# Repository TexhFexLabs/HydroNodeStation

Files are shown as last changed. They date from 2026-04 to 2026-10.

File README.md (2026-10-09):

<div align="center">
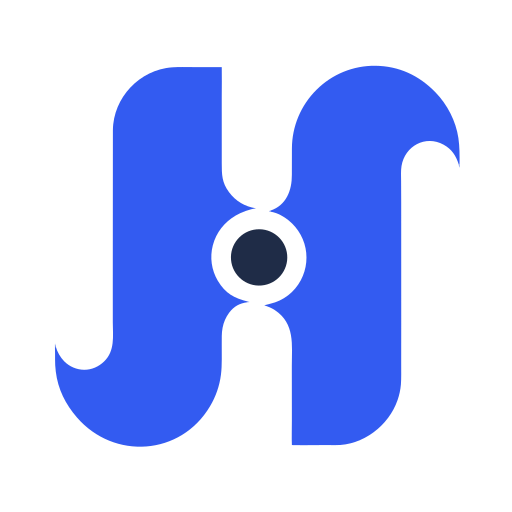
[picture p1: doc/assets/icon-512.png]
HydroNode logo
  
  <h1>HydroNodeStation</h1>
  <p><strong>Solar-powered, open-source LoRaWAN environmental monitoring node</strong></p>
  <p>Powered by <strong>HydroNode</strong></p>

  
  
  
  
  
  
  
</div>

---

> **Live now.** A station is deployed outdoors and streaming real sensor data.
> [View the live dashboard.](https://hydronode.tech/stations/public/004dd7e7-5c27-4de0-bff5-24116f721658)

<div align="center">
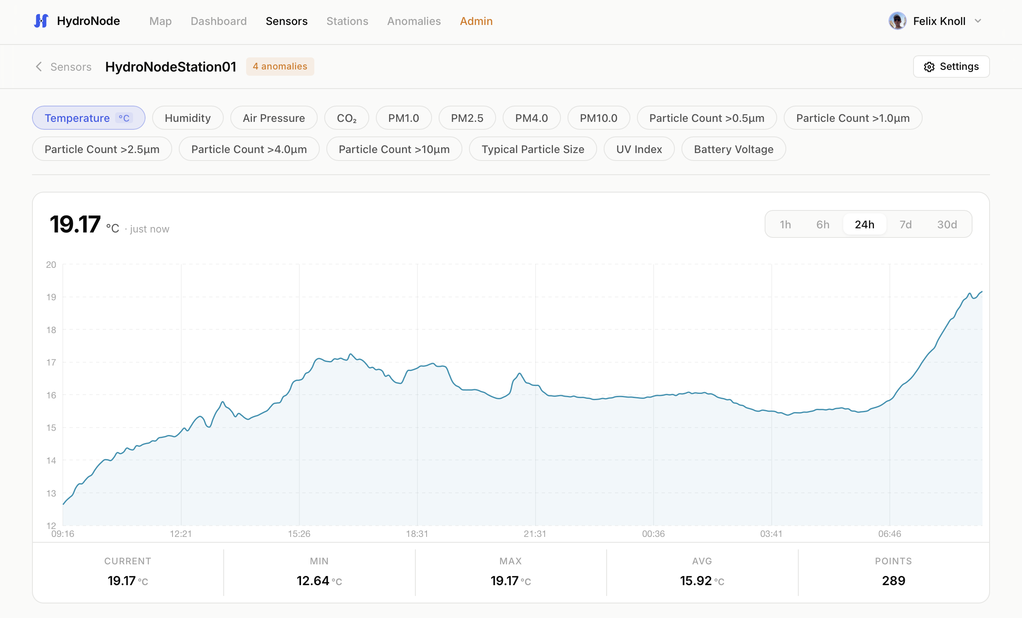
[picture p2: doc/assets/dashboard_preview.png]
HydroNode live dashboard showing HydroNodeStation sensor data
  
</div>

---

## What this is

Hyperlocal environmental data is scarce. Most weather and air quality stations are expensive, need mains power, and are installed at only a handful of official sites per city. Whole neighbourhoods have no measurements of the air they breathe.

The limiting factor is not the sensors. It is power and connectivity. A station that needs mains power or Wi-Fi can only go where that infrastructure already exists, which is not where the data gaps are.

HydroNodeStation is a monitoring node that needs no mains power, no Wi-Fi and no cellular contract. It runs on a small solar panel and a single LiPo cell, transmits over LoRaWAN, and is designed to be reproduced by anyone with a JLCPCB account and a 3D printer.

It is not a paper design. It was built, assembled and deployed as part of a university engineering project, and one station has been reporting continuously.

**Project status:** hardware revision 2 (PCB 1.1) is the supported board, firmware 2.1.0 is written for it and awaits its field acceptance test. Revision 1 boards stay on firmware 1.6.x, which is deployed; one station is live in the field. Long-term solar autonomy through a winter is not verified yet. See [Power budget](#power-budget-measured) for measured numbers instead of estimates.

<div align="center">
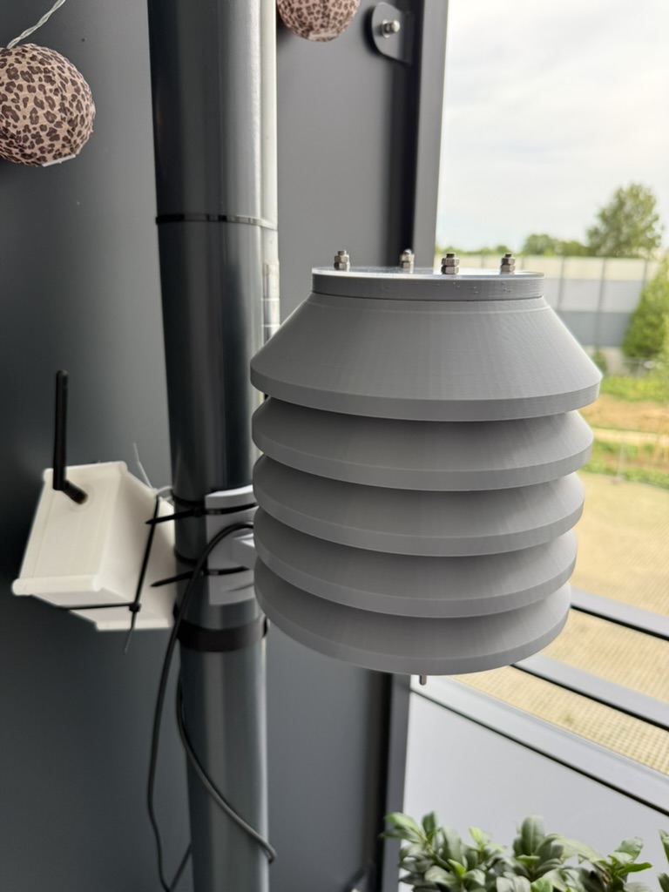
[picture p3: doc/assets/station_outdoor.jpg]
HydroNodeStation deployed outdoors, Stevenson screen mounted on a railing post
  
  <br><em>The deployed station.</em>
</div>

---

## Quick links

| | |
|---|---|
| Live dashboard | [hydronode.tech](https://hydronode.tech/stations/public/004dd7e7-5c27-4de0-bff5-24116f721658) |
| Hardware design (EasyEDA Pro / OSHWLab) | [oshwlab.com/knollfelix004/project_fegzdygg](https://oshwlab.com/knollfelix004/project_fegzdygg) |
| Build a station | [Jump to the build guide](#build-a-station) |
| Firmware reference | [doc/GETTING_STARTED.md](doc/GETTING_STARTED.md) |
| Configuration reference | [doc/CONFIGURATION.md](doc/CONFIGURATION.md) |
| Adding a sensor (Qwiic) | [doc/ADDING_SENSORS.md](doc/ADDING_SENSORS.md) |
| Reliability and rollout notes | [doc/RELIABILITY.md](doc/RELIABILITY.md) |
| Licensing | [LICENSING.md](LICENSING.md) |
| Development history | [doc/DEVELOPMENT_HISTORY.md](doc/DEVELOPMENT_HISTORY.md) |

---

## What it measures

| Quantity | Sensor | I2C address | Notes |
|---|---|---|---|
| CO2 concentration | Sensirion **SCD41** | 0x62 | Single-shot photoacoustic NDIR, plus or minus 40 ppm |
| Particulate matter | Sensirion **SPS30** | 0x69 | PM1.0, PM2.5, PM4, PM10 and number concentration |
| Temperature and humidity | Sensirion **SHT45** | 0x44 | plus or minus 0.1 degrees C, plus or minus 1.0 percent RH |
| Barometric pressure | Bosch **BMP390** | 0x77 | plus or minus 0.5 hPa absolute |
| UV index | Lite-On **LTR390** | 0x53 | UVA and ambient light |
| Battery state of charge | Maxim **MAX17048** | 0x36 | Fuel gauge, no sense resistor needed |

All six share one I2C bus. Sensors are commanded into their own sleep states between measurements. The SPS30 sits on a separate 5 V rail that the firmware switches off entirely through a GPIO.

The sensor set is a starting point, not a limit. Any I2C sensor can be added on the Qwiic connector (CN2) with a firmware adaptation, see [doc/ADDING_SENSORS.md](doc/ADDING_SENSORS.md).

---

## Hardware

### Custom 4-layer PCB

<div align="center">
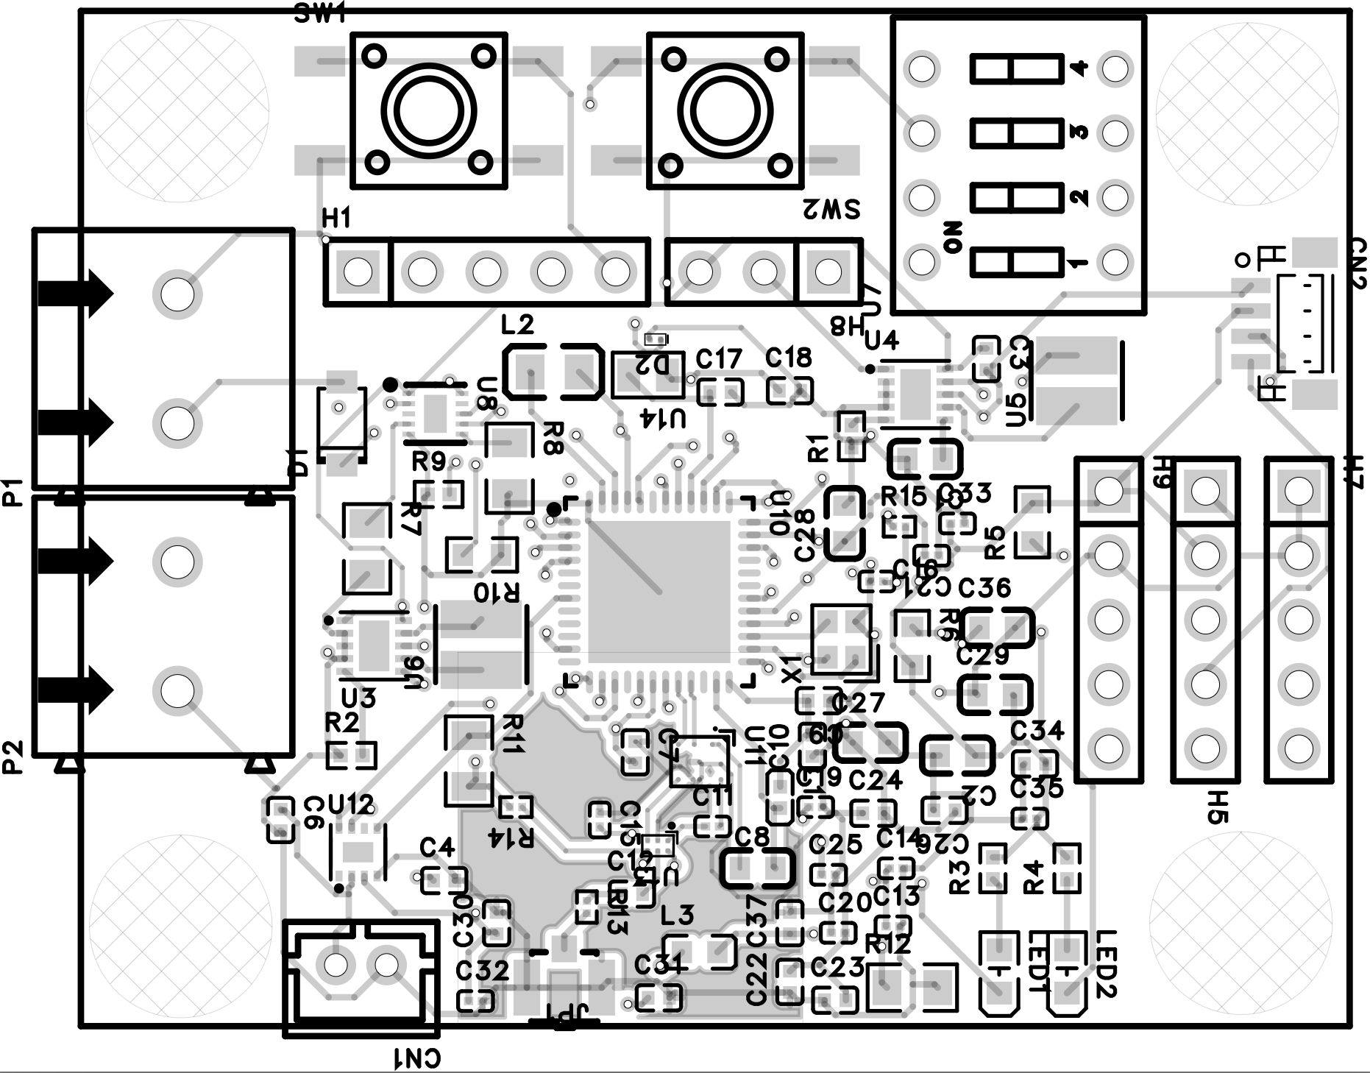
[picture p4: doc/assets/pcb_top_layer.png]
HydroNodeStation PCB top layer
  
</div>

Designed from scratch in EasyEDA Pro, fabricated and assembled at JLCPCB.

| Function | Part |
|---|---|
| MCU and radio | **STM32WLE5CCU6**, Cortex-M4 at 48 MHz with an integrated sub-GHz LoRa transceiver |
| RF front end | **BALFHB-WL-02D3** balun on RFO_HP and **BGS12SN6** TX/RX switch (select PC13, supply PB12), 32 MHz crystal |
| Antenna | External SMA connector |
| Solar charger | **BQ25185** |
| Regulators | Three **TPS63900** buck-boost converters. 3.3 V primary always on, 5 V for the SPS30 (EN5V, PA9) and a switchable 3.3 V rail (EN3V3SW, PA8) |
| Fuel gauge | **MAX17048** |
| Solar measurement | **INA226** on a 68 mOhm shunt plus a voltage divider on ADC PB2 |

**Stackup.** Top and bottom carry signal and supply. Inner 1 is a dedicated ground layer with a continuous copper pour. Inner 2 is a second signal layer. The continuous ground layer gives short return paths and keeps common-mode noise off the I2C and control lines.

**RF layout.** Traces in the RF section are 50 ohm controlled impedance for 868 MHz. A dense ground via fence surrounds the balun, the switch, the decoupling capacitors and the SMA path. It ties the RF field down to the ground layer and suppresses coupling into the rest of the board.

**Connectors.** A 2-pin JST connector and a parallel screw terminal for the battery, a 2-pin screw terminal for the solar panel, a 6-pin screw terminal for the cable to the Stevenson screen (I2C, supply, panel lead), and a 4-pin header for the ST-Link V2 (NRST, SWDCLK, SWDIO, GND). Test pads are provided on the supply rails, the I2C bus and the charger CE pin.

> **Revision 2 (PCB 1.1) pin changes against revision 1.** Charger CE moves to PA2, the RF switch is supplied from PB12, the 5 V and switchable 3.3 V rails have enable pins (PA9, PA8), and an INA226 measures the solar input. Firmware 2.0 requires these; firmware 1.6.x stays for revision 1.

> **Two faults in revision 1, both fixed in the published design.**
>
> **TPS63900 regulator section.** A wiring mistake. The deployed station runs the same chip on a breakout board plugged into the PCB headers as a workaround.
>
> **BQ25185 CE pin.** It has to be driven by an MCU GPIO so the firmware can reset the charger's internal 6 hour safety timeout. Without that, charging stops silently after six hours, which is fatal on a solar node. Revision 2 routes CE to a GPIO that the firmware pulses. On boards already fabricated, this pin has to be hand-soldered to the GPIO.

### Stevenson screen enclosure

<div align="center">
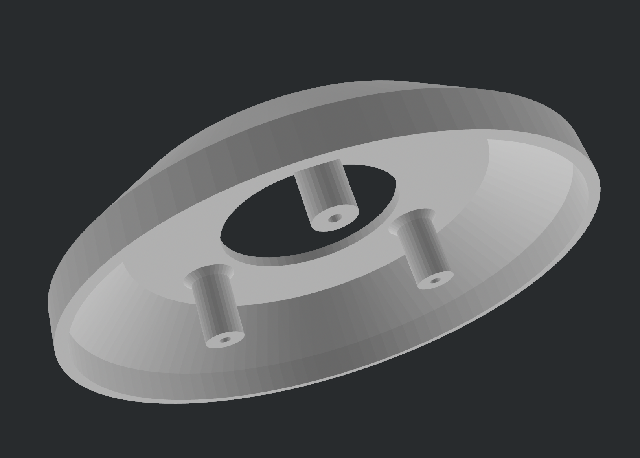
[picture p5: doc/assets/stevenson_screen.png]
3D-printed Stevenson screen middle section
  
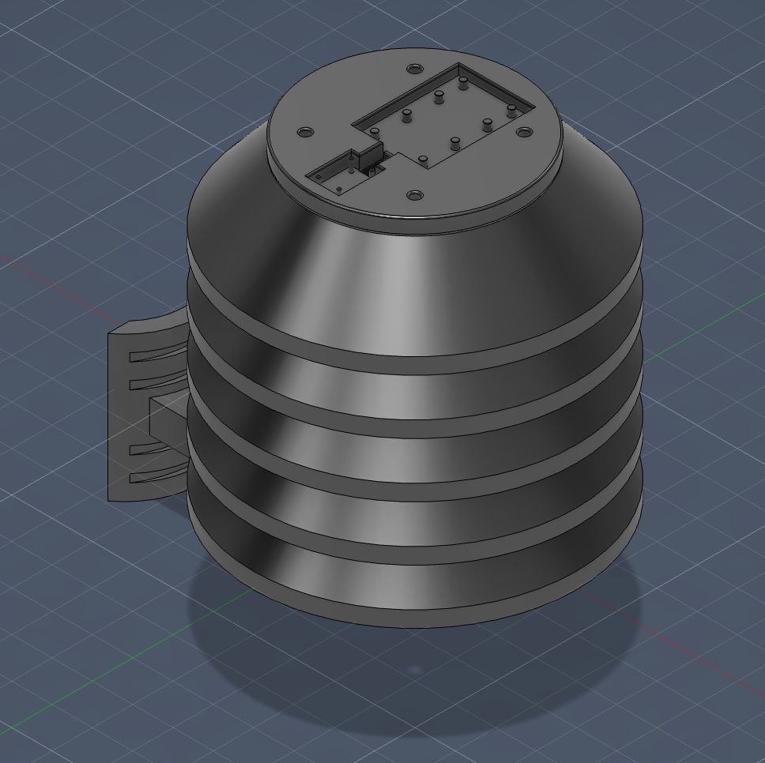
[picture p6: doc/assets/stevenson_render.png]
CAD render of the Stevenson screen with the PCB mounting plate
  
  <br><em>Printed part and the CAD model it comes from. The plate on top carries the PCB.</em>
</div>

Designed in Fusion 360, printed in white ASA. Stacked louvers block direct sun and driving rain while air circulates freely. Without that the housing heats up in sunlight and the temperature and humidity readings are wrong. ASA was chosen over PLA and PETG for outdoor UV stability. A PLA enclosure becomes brittle within a season.

Both models are in [`hardware/CAD/`](hardware/CAD/) as `.3mf` and print on any consumer FDM printer.

### System architecture

```mermaid
flowchart LR
    subgraph Field ["Field deployment"]
        Node1(("HydroNode\nStation #1"))
        Node2(("HydroNode\nStation #2"))
    end

    subgraph Network ["LoRaWAN network server"]
        NS["Helium IoT / ChirpStack v4 / TTN"]
    end

    subgraph Backend ["HydroNode cloud"]
        API{"HTTPS\nwebhook endpoint"}
        Kafka["Kafka pipeline\n(validation and processing)"]
        DB[("PostgreSQL")]
    end

    subgraph Client ["End users"]
        App["iOS app and web dashboard"]
    end

    Node1 -- LoRaWAN --> NS
    Node2 -- LoRaWAN --> NS
    NS -- HTTPS webhook --> API
    API --> Kafka
    Kafka --> DB
    DB --> App
```

---

## Build a station

This is the complete path from ordering parts to seeing your own readings on the dashboard. Budget two to three weeks, most of which is PCB lead time.

### Step 1: order the PCB

1. Open the [OSHWLab project](https://oshwlab.com/knollfelix004/project_fegzdygg) and fork it. It opens in EasyEDA Pro in the browser, so no desktop EDA installation is needed.
2. Order from the editor through JLCPCB. 4 layers, standard process, no exotic requirements.
3. Enable SMT assembly. This matters. The STM32WLE5, the balun and the RF switch are fine-pitch parts, and hand-soldering them is where most reproduction attempts fail.
4. The bill of materials with LCSC part numbers is generated by EasyEDA on the project page and can be ordered from there directly. Populate only the sensors you need, see the cost table below.

### Step 2: order the remaining parts

These are not on the PCB and have to be sourced separately.

| Part | What is deployed today | Notes |
|---|---|---|
| Solar panel | **AnySolar SOLAR CELL G3 THIN**, 6.91 V, 570.8 mW, Vmpp 5.58 V, Impp 102 mA | Fully sufficient in summer. Winter operation is not verified yet. **Do not use a smaller panel.** Same size or larger only. |
| Battery | 1S LiPo, **1200 mAh** | Scale with the panel. Larger is fine and helps in winter. Much smaller is risky, since several overcast days in a row will drain it. |
| Antenna | 868 MHz antenna with an SMA connector | The board has an external SMA connector, so any matched antenna works. |
| Cable to the screen | 6-core cable | Runs from the PCB screw terminal to the sensor head: I2C, supply, panel lead. |
| Cable gland | Waterproof, sized for your cable | For the panel lead entering the enclosure. |
| UV window | 2 mm polystyrene sheet | See the note below. |
| Programmer | ST-Link V2 | Connects to NRST, SWDCLK, SWDIO, GND. |
| Serial adapter | USB to UART, 3.3 V | Needed once, to read the Device EUI off header H1 at 115200 baud. |

> **About the UV window.** The LTR390 has to see UV through the enclosure, but ordinary glass and PETG block most of it and produce a reading that is wrong rather than missing. The deployed station uses roughly 2 mm of polystyrene with an empirical correction factor of 17/13, applied in the firmware as integer arithmetic. That was a cost decision. It works, but polystyrene is not UV-stable and will degrade outdoors. **UV-transmitting acrylic (PMMA UVT) is the better choice** for a station meant to last. Quartz or borosilicate is better still and costs around 50 EUR for a small disc. Issue [#2](../../issues/2) tracks cheaper options.

### Step 3: print the enclosure

Both models are in [`hardware/CAD/`](hardware/CAD/).

- `hydroNodeStation_outdoor_screen.3mf` is the Stevenson screen for the sensor head.
- `hydroNodeStation_outdoor_box.3mf` is the housing for the PCB.

Print in **white ASA**, not PLA and not PETG. White reflects sunlight, which matters for the temperature reading, and ASA survives UV exposure. Expect to iterate once on fit. The original design took several print runs to get right.

### Step 4: assemble

1. Mount the PCB on the plate at the top of the Stevenson screen.
2. Wire the 6-core cable from the PCB screw terminal to the sensor head.
3. Connect the battery to the JST connector or the parallel screw terminal.
4. Connect the solar panel to its screw terminal, routing the lead through the cable gland.
5. Screw the antenna onto the SMA connector.
6. Fit the UV window over the LTR390.

> **Building from revision 1 boards?** Hand-solder the BQ25185 CE pin to the MCU GPIO before you deploy. Without it, charging stops after six hours and the station dies over a few days while sitting in full sun.

> **Battery protection.** In the published schematic the BQ25185 TS/MR pin uses a fixed 10 kilohm resistor, so the charger does not measure battery temperature. Outdoor winter operation needs an appropriate battery NTC and a verified undervoltage path. The firmware cannot protect an unprotected cell below MCU operating voltage. See [doc/RELIABILITY.md](doc/RELIABILITY.md).

### Step 5: install the toolchain

| Tool | Version |
|---|---|
| `arm-none-eabi-gcc` | 12 or newer |
| `cmake` | 3.22 or newer |
| `ninja` | any |
| `openocd` or STM32CubeProgrammer | any |

```bash
# macOS
brew install arm-none-eabi-gcc cmake ninja

# Ubuntu / Debian
sudo apt install gcc-arm-none-eabi cmake ninja-build
```

### Step 6: build the firmware

```bash
git clone https://github.com/TexhFexLabs/HydroNodeStation.git
cd HydroNodeStation/stm32_node

cmake -B build/Release -DCMAKE_BUILD_TYPE=Release -DCMAKE_TOOLCHAIN_FILE=cmake/gcc-arm-none-eabi.cmake
cmake --build build/Release
```

The output is `build/Release/LoRaWAN_End_Node_LBM.elf` plus `.bin` and `.hex`. The `Debug` target builds the same firmware with trace output over USART1, which step 7 uses. Firmware 2.0 needs a revision 2 board (PCB 1.1); for revision 1 check out a 1.6.x release.

Leave the LoRaWAN keys alone for now. `LORAWAN_DEVICE_EUI` stays at all zeros, which tells the firmware to derive the Device EUI from the STM32 hardware UID.

### Step 7: flash and read the Device EUI

Connect the ST-Link V2 to NRST, SWDCLK, SWDIO and GND, then flash:

```bash
openocd -f interface/stlink.cfg -f target/stm32wlx.cfg \
        -c "program build/Release/LoRaWAN_End_Node_LBM.elf verify reset exit"
```

STM32CubeProgrammer works too. Open the `.elf`, select ST-Link, click Download.

Clear the option byte **IWDG_STDBY** once per board, otherwise the station cannot use its Standby stage at deep discharge (it then stays in RECOVERY and reports `0x0544`):

```bash
STM32_Programmer_CLI -c port=SWD -ob IWDG_STDBY=0
```

To read the Device EUI, flash the `Debug` build once (`cmake --preset Debug && cmake --build --preset Debug`, then flash `build/Debug/LoRaWAN_End_Node_LBM.elf`). Connect the USB to UART adapter to header **H1** (PB6 = TX, PB7 = RX) at 115200 baud. The firmware prints the derived **Device EUI** on boot. Write it down, it is needed in the next two steps. With DIP 1 closed, LED1 flashes once per join attempt and twice when the join succeeds.

### Step 8: register the device on a LoRaWAN network server

Create an OTAA device with that Device EUI. Use LoRaWAN 1.0.4 and the regional parameters for your region, EU868 in Europe. Helium IoT, ChirpStack v4 and The Things Network all work.

The network server returns a **Join EUI** and an **App Key**.

### Step 9: enter the keys and reflash

Create `stm32_node/LoRaWAN/App/se-identity-local.h`. This file is git-ignored, and the firmware picks it up automatically:

```c
#define LORAWAN_DEVICE_EUI    00,00,00,00,00,00,00,00   // leave at zero, derived from the chip UID
#define LORAWAN_JOIN_EUI      AA,BB,CC,DD,EE,FF,00,11   // from your network server
#define LORAWAN_APP_KEY       AA,BB,CC,DD,EE,FF,00,11,22,33,44,55,66,77,88,99
#define LORAWAN_GEN_APP_KEY   AA,BB,CC,DD,EE,FF,00,11,22,33,44,55,66,77,88,99
```

`LORAWAN_GEN_APP_KEY` takes the same value as `LORAWAN_APP_KEY` under LoRaWAN 1.0.x.

Never put real keys in the tracked `se-identity.h`, and never commit them. See [SECURITY.md](SECURITY.md).

Rebuild the `Release` target and flash it. The station now starts the OTAA join with your credentials.

### Step 10: connect it to HydroNode

1. Open [hydronode.tech](https://hydronode.tech) or the HydroNode app and register. The first sensor slot is included at no cost.
2. Select the sensor, then go to **Settings, LoRaWAN Binding**.
3. Enter the **Device EUI** from step 7 and save.
4. HydroNode then shows a **webhook URL**.
5. Enter that URL on your network server under **Integrations, HTTP / Webhook**.

That is the whole integration. The backend decodes the payload by fPort, stores it and runs anomaly detection without further configuration. Readings appear in the dashboard and the app from the next uplink onward.

To run your own backend instead, the payload decoder is published as [`doc/payload-decoder.js`](doc/payload-decoder.js) and the payload format is specified in [doc/CONFIGURATION.md](doc/CONFIGURATION.md). Nothing in the firmware is tied to the HydroNode infrastructure.

### Step 11: verify

The first uplink lands on fPort 2 and should appear within one to two minutes if there is gateway coverage.

To place the antenna, close DIP 4 (installation mode) and DIP 1 before power-on. For 30 minutes after the join the station sends every 60 seconds and runs a link check after every third uplink; LED1 then flashes once per gateway that heard it, or once long when none answered.

To check the sensors without LoRaWAN, close DIP 3 (debug profile) before power-on. The node skips LoRaWAN entirely, reads all sensors including the solar measurement in a loop and prints the values on H1 at 115200 baud. This works with the Release build. Open both switches again for normal operation; they are read only at boot.

### Cost

| Build | Sensors populated | Sensor cost |
|---|---|---|
| Minimal | Temperature, humidity, pressure (SHT30 as a substitute) | under 30 USD |
| Air quality | Plus LTR390 UV and SCD41 CO2 | around 70 USD |
| Full node | All six channels including the SPS30 | 120 to 150 USD |

Sensors only. The board itself, the RF section, the power stage and the fabrication come on top, roughly 200 EUR for 5 assembled boards. Unpopulated sensor positions cost nothing and break nothing, so one design serves a single hobbyist node and a research-grade array.

---

## Firmware

Firmware 2.1.0 runs on PCB 1.1. Since 2.1 the send interval and the four battery thresholds can be changed by downlink `14` and the station reports the values in effect on fPort 6. It keeps everything firmware 1.6 brought (fix of the uplink outage after 49.71 days, watchdog and progress recovery, robust sensor shutdown, battery recovery, transactional NVM) and adds solar and fuel gauge data on ports 2 and 3, fault and event reports on fPort 99, command acknowledgements, an adaptive measurement plan with a Standby stage for deep discharge, a daily link check with rejoin, and the installation mode. See [doc/CONFIGURATION.md](doc/CONFIGURATION.md) and [doc/RELIABILITY.md](doc/RELIABILITY.md).

The firmware runs on the STM32Cube ecosystem with the Semtech **LoRa Basics Modem**.

- **STOP2 deep sleep** between transmissions, capped at 8 seconds so the independent watchdog stays fed.
- **3 minute measurement cycle** (`APP_TX_DUTYCYCLE`), adjustable over the air between 30 and 3600 seconds.
- **CO2 every fifth uplink, particulate matter every tenth.** The expensive sensors do not run every cycle.
- **Solar sampling every 30 seconds.** INA226 voltage, current and power, energy and sunshine time, plus the panel voltage on the ADC, collected into a 22-byte block on ports 2 and 3.
- **LoRaWAN Class A** with network-controlled adaptive data rate and a daily link check. Three days without an answer trigger a rejoin.
- **Faults reach the backend.** Missing sensors, read errors, supply states, rejoins and every restart with its reason are reported on fPort 99.
- **Staggered pre-wakeup.** Slow sensors start ahead of the transmit window so the MCU sleeps through their measurement time instead of waiting for them.
    - The **SCD41** runs two power-cycled single shots. A throwaway stabilisation shot starts 12 seconds before the uplink, the useful shot 6 seconds before it. Only the second is transmitted. Without the first, the reading after a power cycle is measurably wrong.
    - The **SPS30** starts 16.5 seconds before the uplink to cover fan spin-up and settling.
- **Battery policy** with hysteresis. Below 3500 mV the interval doubles and PM pauses. Below 3300 mV the node cancels radio and sensor work and checks the voltage every 60 seconds until it recovers. Two readings below 3200 mV put it into Standby with an hourly wake-up (needs the option byte IWDG_STDBY cleared, see [doc/CONFIGURATION.md](doc/CONFIGURATION.md#power-modes)). These are the defaults; downlink `14` changes all four thresholds and the interval (firmware 2.1).

### Downlink commands

Sent on fPort 2. Every command is acknowledged on fPort 99 with its result.

| Payload | Action |
|---|---|
| `10 HH LL` | Set the transmit interval in seconds, 30 to 3600, persisted to flash and in effect at once |
| `11` | Trigger an SPS30 fan cleaning cycle |
| `12` | Request boot, reset and sensor diagnostics on fPort 5 |
| `14 …` | Set interval and the four battery thresholds (12 bytes, firmware 2.1); the station answers with its values on fPort 6 |
| `FF` | Software reset |

The SPS30 also cleans itself every 120 hours, but only when the battery is above 4120 mV.

### Where the data ends up

<div align="center">
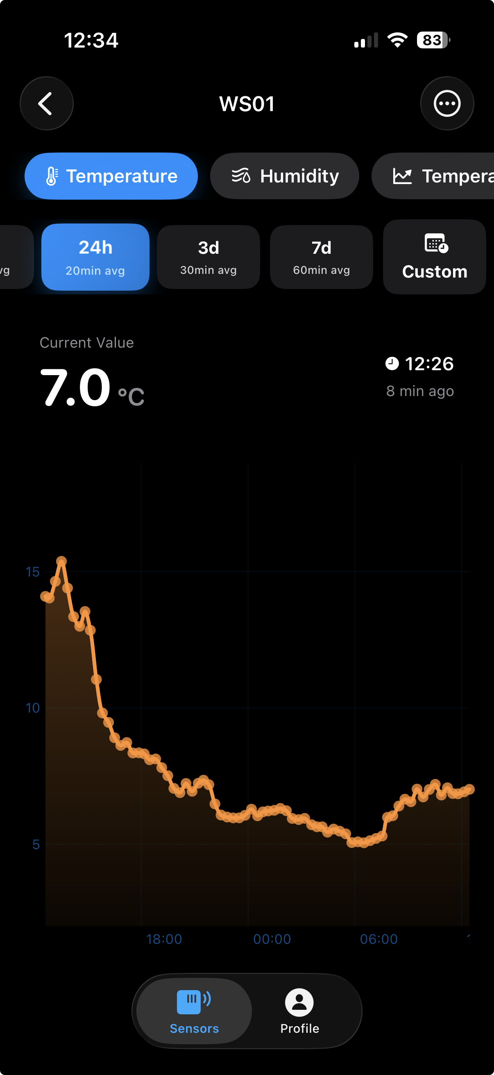
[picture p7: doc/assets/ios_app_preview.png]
iOS app showing a 24 hour temperature chart for station WS01
  
  <br><em>Every channel gets its own history view. The same data is on the public dashboard without a login.</em>
</div>

The network server posts each uplink straight to the HydroNode backend over an HTTPS webhook, with no message broker in between. A Kafka pipeline validates it into PostgreSQL.

### Power budget (measured)

These are PPK2 measurements on the custom PCB, not datasheet arithmetic.

| Source | Interval | Extra charge per event | Events per day | mC per day |
|---|---|---|---|---|
| Baseline (1.1 mA over 86400 s) | | | | 95,040 |
| LoRa transmit (+0.7 mA for 10 s) | 3 min | 7 mC | 480 | 3,360 |
| SCD41 CO2 | 15 min | 77 mC | 96 | 7,392 |
| SPS30 (55 mA for 30 s minus idle) | 30 min | 1,617 mC | 48 | 77,616 |
| **Total** | | | | **183,408** |

`183,408 mC / 3600 = 50.9 mAh per day`, so `1200 mAh / 50.9` is about **24 days on a 1200 mAh cell with no solar input**.

<div align="center">
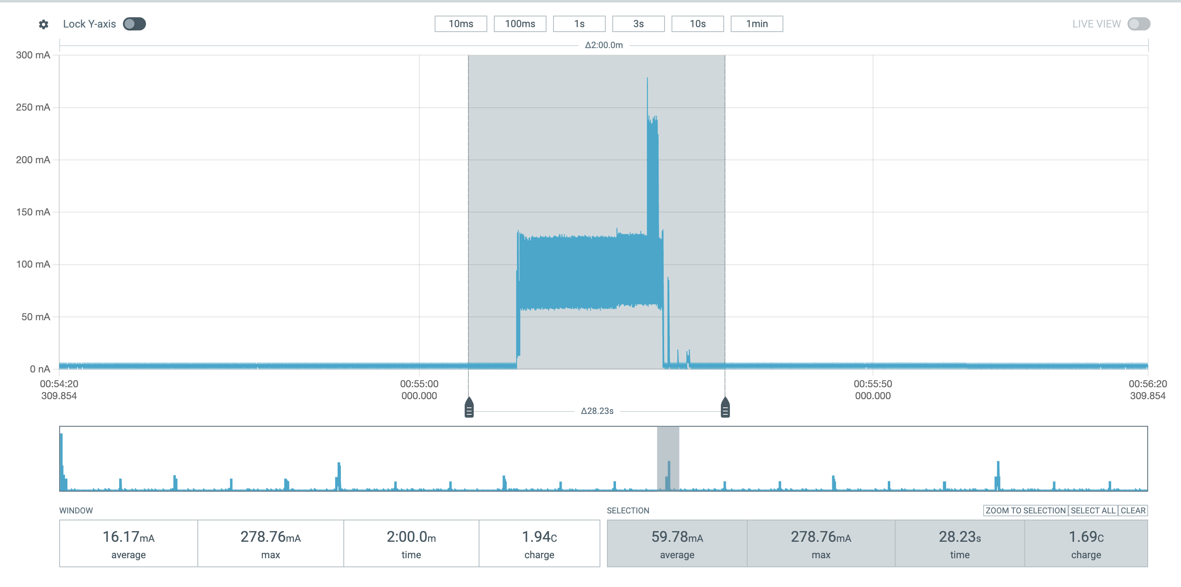
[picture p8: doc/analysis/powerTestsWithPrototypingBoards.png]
PPK2 current trace showing an SPS30 measurement event against the sleep baseline
  
  <br><em>PPK2 capture of one SPS30 measurement event: 28 s, 1.69 C, peaking at 279 mA against the
  sleep baseline. Recorded during the prototyping-board stage. The numbers in the table above are
  from the custom PCB.</em>
</div>

> **One unsolved problem.** The day-average baseline draw is 1.1 mA. Adding up the sleep currents of every component on the board gives roughly 5.7 microamps, a factor of about 200. The suspects are SCD41 IR source leakage, BQ25185 quiescent current and PCB leakage paths. This is not solved, and closing it is the highest-impact open task on the project. If you have hunted sleep-current problems on STM32WL designs, see issue [#1](../../issues/1).

Solar harvesting is designed to keep the node online indefinitely. Energy-balance logging through a full seasonal cycle is running now. No autonomy figure will be published before matched PPK2 measurements support it.

---

## Repository structure

```
HydroNodeStation/
├── stm32_node/          Firmware (STM32WLE5, CMake, LoRa Basics Modem)
│   ├── Core/Src/        Own sensor drivers: SHT45, BMP390, LTR390, SCD41, SPS30, MAX17048, BQ25185
│   ├── LoRaWAN/App/     Application logic and the key template
│   ├── tests/           Host-side regression tests, no hardware required
│   └── cmake/           Toolchain files
├── hardware/
│   ├── ordered_pcb/     Schematic PDF and PCB renders as fabricated
│   ├── schematics_pcb/  Schematic and PCB exports
│   ├── CAD/             Stevenson screen and PCB housing, .3mf
│   └── datasheets/      Component datasheets, vendor copyright, see LICENSING.md
├── doc/
│   ├── GETTING_STARTED.md          Firmware reference
│   ├── CONFIGURATION.md            Pins, timing, power modes, payloads, fault codes, downlinks
│   ├── ADDING_SENSORS.md           Where your own Qwiic/I2C sensor goes in the firmware
│   ├── RELIABILITY.md              Reliability and rollout notes, firmware 1.6 and 2.0
│   ├── DEVELOPMENT_HISTORY.md      Issue and pull request record of the private phase
│   ├── payload-decoder.js          LoRaWAN payload decoder
│   ├── open-source-documentation/  OSHWLab project description
│   ├── study-documentation/        Full project report, German
│   ├── zwischenbericht/            Interim report, German
│   ├── presentations/              Pitch decks
│   ├── assets/                     Images used in the documentation
│   └── analysis/                   Power measurements
└── LICENSES/            Full licence texts
```

The live bill of materials with LCSC part numbers is generated by EasyEDA on the [OSHWLab project page](https://oshwlab.com/knollfelix004/project_fegzdygg) and can be ordered from there directly.

---

## Contributing

Contributions are welcome. The design only gets better with more deployments behind it, and you do not need to write firmware to help.

The most useful things right now:

- **Field reports.** Build a station, deploy it, and report your location, sensor configuration and what broke. Real deployment data is worth more than code.
- **The 1.1 mA leakage hunt.** See the power budget above. Highest impact open problem.
- **A UV-transmitting window that lasts.** Polystyrene works but degrades. See issue [#2](../../issues/2).
- **Drivers for additional I2C sensors.** The bus architecture is deliberately open-ended.
- **Enclosure improvements.** Sealing, print reliability, alternative mounts.

Open an issue first for anything non-trivial. Details are in [CONTRIBUTING.md](CONTRIBUTING.md), and this project follows the [Contributor Covenant](CODE_OF_CONDUCT.md).

Issues labelled [`good first issue`](../../issues?q=is%3Aissue+is%3Aopen+label%3A%22good+first+issue%22) and [`help wanted`](../../issues?q=is%3Aissue+is%3Aopen+label%3A%22help+wanted%22) are the easiest way in.

---

## Security

Never commit real LoRaWAN keys. [SECURITY.md](SECURITY.md) explains how key material is handled here and how to report a vulnerability privately.

---

## License

This is a mixed hardware and software project with three licences. The file-level map is in [LICENSING.md](LICENSING.md).

| Part | Licence |
|---|---|
| Hardware: schematic, PCB, CAD | [CERN-OHL-S v2](LICENSE), strongly reciprocal |
| Documentation and media | [CC BY-SA 4.0](LICENSES/CC-BY-SA-4.0.txt) |
| Firmware, own code | [MIT](LICENSES/MIT.txt) |
| Firmware, ST and Arm and Semtech components | Unchanged upstream terms, BSD-3-Clause and Apache-2.0 |

There is no non-commercial restriction. You may build, modify and sell this design. Modified hardware designs have to be shared back under the same licence.

---

## Built with

Designed in [EasyEDA Pro](https://easyeda.com/), fabricated at [JLCPCB](https://jlcpcb.com/), and published on [OSHWLab](https://oshwlab.com/knollfelix004/project_fegzdygg). The complete 4-layer board including the RF section was designed in a browser, ordered from the editor, and shared so anyone can fork it.

---

<div align="center">
  <strong>Build it. Deploy it. Fork it.</strong><br>
  Live data at <a href="https://hydronode.tech">hydronode.tech</a>
</div>

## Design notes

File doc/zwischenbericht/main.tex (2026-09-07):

\documentclass[11pt,a4paper]{scrartcl}

\usepackage[T1]{fontenc}
\usepackage[utf8]{inputenc}
\usepackage[ngerman]{babel}
\usepackage{lmodern}
\usepackage{microtype}
\usepackage[a4paper,margin=2.5cm]{geometry}
% xcolor loaded below with table option
\usepackage{graphicx}
\usepackage{float}
\usepackage{setspace}
\usepackage{amsmath}
\usepackage{longtable}
\usepackage{multirow}
\usepackage{booktabs}
\usepackage{tabularx}
\usepackage{array}
\usepackage[table]{xcolor}
\usepackage[hidelinks]{hyperref}
\usepackage{xurl}

\definecolor{accent}{HTML}{0B4F6C}
\definecolor{colgreen}{HTML}{2E7D32}
\definecolor{colorange}{HTML}{E65100}
\definecolor{colred}{HTML}{C62828}
\definecolor{colblue}{HTML}{0B4F6C}
\definecolor{rowgray}{HTML}{F5F5F5}

\setstretch{1.15}
\setkomafont{disposition}{\color{accent}\bfseries}

\newcommand{\status}[1]{%
  \ifstrequal{#1}{Fertig}{\textcolor{colgreen}{\textbf{Fertig}}}{}%
  \ifstrequal{#1}{In Arbeit}{\textcolor{colorange}{\textbf{In Arbeit}}}{}%
  \ifstrequal{#1}{Geplant}{\textcolor{colblue}{\textbf{Geplant}}}{}%
  \ifstrequal{#1}{Weggelassen}{\textcolor{colred}{\textbf{Weggelassen}}}{}%
}

\begin{document}

% ───────────────────────────────────────────────────────
%  Titelseite
% ───────────────────────────────────────────────────────
\begin{titlepage}
  \centering
  \vspace*{3cm}

  {\color{accent}\rule{\linewidth}{2pt}}
  \vspace{0.8cm}

  {\LARGE\bfseries\color{accent} DAPI Zwischenstatusbericht\par}
  \vspace{0.4cm}
  {\large HydroNodeStation 01\par}
  {\normalsize Autarke Wetterstation inkl.\ KI-Analyse im HydroNode-Netzwerk\par}

  \vspace{0.8cm}
  {\color{accent}\rule{\linewidth}{1pt}}
  \vspace{2cm}

  \begin{tabular}{ll}
    \textbf{Autor:}       & Felix Knoll \\[4pt]
    \textbf{Kurs:}        & DAPI, Einzel-Projekt \\[4pt]
    \textbf{Datum:}       & 30.\ Mai 2026 \\
  \end{tabular}

  \vfill
  {\color{accent}\rule{\linewidth}{2pt}}
\end{titlepage}

% ───────────────────────────────────────────────────────
\section{Projektstatus}
% ───────────────────────────────────────────────────────

Das Projekt \textit{HydroNodeStation 01} befindet sich auf der Zielgeraden.
Der technische Kern ist abgeschlossen: Alle fünf Kernsensoren (Temperatur,
Luftfeuchtigkeit, Luftdruck, UV-Index, Feinstaub, CO${}_2$) liefern zuverlässige
Messwerte.
Die Station sendet Daten über LoRaWAN im Helium-Netzwerk; die Datenpipeline über
Amazon SNS zum HydroNode-Backend ist aktiv.
Website und iOS-App zeigen Echtzeit- und Verlaufsdaten an.

Der aktuelle Schwerpunkt liegt auf dem Hardwaretest im 3D-gedruckten
Stevenson-Screen-Gehäuse im Ausseneinsatz, die bisherigen Ergebnisse sehen gut aus.
Der TPS63900-Spannungsregler des PCBs hatte einen Fehler; als Workaround läuft
der Chip derzeit als externes Breakout-Board an den PCB-Headern, mit minimalem
Mehraufwand und gleicher Effizienz.
Das korrigierte PCB-Design ist bereits erarbeitet.
Offen sind noch die finale Solar-Verifikation, die KI-Evaluation und die
Abschlussdokumentation.

% ───────────────────────────────────────────────────────
\section{Soll-Zustand (Projektplan)}
% ───────────────────────────────────────────────────────

Im Projektplan wurden 20 Features mit insgesamt \textbf{160 Stunden} eingeplant
(Tabelle~\ref{tab:features}).

\begin{longtable}{>{\bfseries}p{0.5cm} p{13.5cm} r}
  \toprule
  \# & Feature / Aufgabe & Std. \\
  \midrule
  \endfirsthead
  \toprule
  \# & Feature / Aufgabe & Std. \\
  \midrule
  \endhead
  \bottomrule
  \endfoot
  \bottomrule
  \endlastfoot

  1  & Hardware-Auswahl \& Beschaffung (MCU, Sensoren, Solar, Akku, Gehäuse) & 8 \\
  \rowcolor{rowgray}
  2  & Schaltplan \& Aufbau der Wetterstation-Elektronik & 9 \\
  3  & Sensor: Temperatur, Luftfeuchtigkeit \& Luftdruck & 2 \\
  \rowcolor{rowgray}
  4  & Sensor: UV-Index \& Lichtstärke & 2 \\
  5  & Sensor: Partikelkonzentration (SPS30) & 4 \\
  \rowcolor{rowgray}
  6  & Sensor: CO${}_2$-Konzentration (SCD41) & 4 \\
  7  & Sensor: Umgebungslautstärke (MEMS-Mikrofon) & 3 \\
  \rowcolor{rowgray}
  8  & Standalone-Test: Sensoren \& LoRaWAN ohne Systemanbindung & 8 \\
  9  & PCB-Design, Bestellung \& Bestückung & 9 \\
  \rowcolor{rowgray}
  10 & Autarke Stromversorgung: Solar-Laderegler \& LiPo-Akku-Management & 13 \\
  11 & Deep-Sleep \& Power-Management Firmware & 7 \\
  \rowcolor{rowgray}
  12 & LoRaWAN-Firmware: Payload-Codec, Sendezyklus, Duty-Cycle-Management & 12 \\
  13 & Helium-Netzwerk: Registrierung, Console-Integration, Decoder & 5 \\
  \rowcolor{rowgray}
  14 & Backend: LoRaWAN-Datenpipeline zu HydroNode (Amazon SNS) & 8 \\
  15 & Website: Echtzeit-Dashboard für alle Stationssensoren & 14 \\
  \rowcolor{rowgray}
  16 & App: Historische Verlaufsdiagramme (alle Sensorkanäle) & 6 \\
  17 & App: Stations-Verwaltung (Hinzufügen, Benennen, Statusanzeige) & 4 \\
  \rowcolor{rowgray}
  18 & KI-Evaluation: Datensatz-Aufbereitung \& Modellauswahl & 8 \\
  19 & KI-Evaluation: Testing, Benchmarking \& Ergebnisdokumentation & 8 \\
  \rowcolor{rowgray}
  20 & Feldtest, Integrationstests \& Abschlussdokumentation & 16 \\
  \midrule
  \multicolumn{2}{r}{\textbf{Gesamt}} & \textbf{160} \\
\end{longtable}
\vspace{-1em}
\begin{center}
  \small\textit{Tabelle 1: Geplante Features mit Aufwandsschätzung aus dem Projektplan (Pitch, 26.03.2026)}
  \label{tab:features}
\end{center}

% ───────────────────────────────────────────────────────
\section{Ist-Zustand (aktueller Stand)}
% ───────────────────────────────────────────────────────

Bis zum 30.\ Mai 2026 wurden insgesamt \textbf{154 Stunden} in das Projekt investiert.
Der grösste Teil der geplanten Features ist abgeschlossen oder befindet sich in einem
fortgeschrittenen Stadium.

\subsection{Abgeschlossene Bereiche}

\begin{itemize}
  \item \textbf{Hardware \& Beschaffung:} Alle Komponenten wurden ausgewählt und bestellt.
        Als Hauptchip wird der STM32WLE5JC verwendet, der MCU und LoRa-Transceiver
        in einem einzigen Chip integriert und dadurch sehr energieeffizient ist.

  \item \textbf{Sensorik:} Folgende Sensoren sind in Betrieb und liefern zuverlässige
        Messwerte: SHT45 (Temperatur und Luftfeuchtigkeit), BMP390 (Luftdruck),
        LTR390 (UV-Index), SPS30 (Feinstaub) und SCD41 (CO${}_2$).
        Der im Plan vorgesehene Lautstärkesensor (MAX4466) wurde aus dem Scope
        genommen, da der Fokus auf den Kernsensoren liegt.

  \item \textbf{PCB-Design und Bestückung:} Ein eigenes PCB wurde in EasyEDA entworfen
        und über JLCPCB produziert. Das PCB ist bestückt und läuft stabil.
        Ein Fehler im TPS63900-Spannungsregler wurde identifiziert: Der Chip arbeitet
        nicht wie geplant. In Absprache mit einem Experten wurden Anpassungen erarbeitet;
        das korrigierte PCB-Design sollte für die bereits bestellten Boards passen.
        Als physischer Workaround wurde der fehlerhafte IC vom LiPo-Akku-Plus und dem
        3{,}3-V-Netz getrennt und der gleiche Chip als Breakout-Board an die PCB-Header
        angesteckt. Das System läuft damit identisch wie zuvor, mit minimalem
        Overhead und gleicher Effizienz.
        Das PCB-Design wird auf OSHWLab als Open-Source-Projekt veröffentlicht und
        nimmt am OSHWLab Open-Source-Contest teil.

  \item \textbf{Firmware:} Deep-Sleep und Power-Management sind implementiert und
        getestet. Der LoRaWAN-Stack mit Payload-Codec, Sendezyklus und
        Duty-Cycle-Management läuft stabil.

  \item \textbf{Helium-Netzwerk \& Backend:} Die Station sendet Daten erfolgreich
        über das Helium-Netzwerk. Die Datenpipeline über Amazon SNS zum HydroNode-
        Backend ist aktiv.

  \item \textbf{Website:} Ein Echtzeit-Dashboard für alle Stationssensoren wurde
        erstellt und ist öffentlich erreichbar. Die aktuellen Messwerte der Station
        können bereits live eingesehen werden unter:\\
        \url{https://hydronode.tech/stations/public/004dd7e7-5c27-4de0-bff5-24116f721658}

  \item \textbf{App-Erweiterungen:} Die iOS-App wurde um historische Verlaufsdiagramme
        für alle Sensorkanäle sowie um die Stationsverwaltung erweitert.

  \item \textbf{Gehäuse:} Das Gehäuse folgt dem Stevenson-Screen-Prinzip: übereinander
        angeordnete Lamellen halten Sonne und Regen ab, lassen aber Luft frei
        zirkulieren. Gedruckt in UV-beständigem ASA-Filament auf einem eigens
        angeschafften 3D-Drucker. Die Sensorik ist eingebaut; der Freilufttest läuft
        mit bisher guten Ergebnissen.
\end{itemize}

\subsection{Laufende Bereiche}

\begin{itemize}
  \item \textbf{Solarladung:} Das PCB läuft bereits mit Akku-Betrieb. Der TPS63900
        wird repariert, danach ist die vollständige Autarkie mit Solar gegeben.

  \item \textbf{KI-Evaluation:} Im HydroNode-Backend werden Sensordaten bereits
        automatisch auf Anomalien analysiert, auch mit den neuen Outdoor-Daten.
        Eine formale Evaluation mit Modellauswahl, Benchmarking und Dokumentation
        steht noch aus.

  \item \textbf{Feldtest \& Abschlussdokumentation:} Erste Langzeittests laufen
        bereits. Ein finaler Feldtest mit Aufstellung an der OTH Regensburg ist geplant.
\end{itemize}

% ───────────────────────────────────────────────────────
\section{Soll / Ist Vergleich}
% ───────────────────────────────────────────────────────

Tabelle~\ref{tab:vergleich} zeigt den Vergleich zwischen dem geplanten und dem
aktuellen Status für alle Features.

\begin{longtable}{>{\bfseries}p{0.5cm} p{6.5cm} r r l}
  \toprule
  \# & Feature & Geplant & Ist (est.) & Status \\
  \midrule
  \endfirsthead
  \toprule
  \# & Feature & Geplant & Ist (est.) & Status \\
  \midrule
  \endhead
  \bottomrule
  \endfoot
  \bottomrule
  \endlastfoot

  1  & Hardware-Auswahl \& Beschaffung & 8\,h & 7\,h & \status{Fertig} \\
  \rowcolor{rowgray}
  2  & Schaltplan \& Elektronik-Aufbau & 9\,h & 4\,h & \status{Fertig} \\
  3  & Sensor: Temperatur / Feuchte / Druck & 2\,h & 3\,h & \status{Fertig} \\
  \rowcolor{rowgray}
  4  & Sensor: UV-Index (LTR390 statt VEML6075) & 2\,h & 2\,h & \status{Fertig} \\
  5  & Sensor: Feinstaub SPS30 & 4\,h & 3\,h & \status{Fertig} \\
  \rowcolor{rowgray}
  6  & Sensor: CO${}_2$ SCD41 & 4\,h & 3\,h & \status{Fertig} \\
  7  & Sensor: Lautstärke (MAX4466) & 3\,h & 0\,h & \status{Weggelassen} \\
  \rowcolor{rowgray}
  8  & Standalone-Tests Sensoren \& LoRaWAN & 8\,h & 3\,h & \status{Fertig} \\
  9  & PCB-Design, Bestellung \& Bestückung & 9\,h & \textasciitilde56\,h & \status{In Arbeit} \\
  \rowcolor{rowgray}
  10 & Autarke Stromversorgung Solar \& Akku & 13\,h & \textasciitilde7\,h & \status{In Arbeit} \\
  11 & Deep-Sleep \& Power-Management & 7\,h & \textasciitilde10\,h & \status{Fertig} \\
  \rowcolor{rowgray}
  12 & LoRaWAN-Firmware & 12\,h & \textasciitilde11\,h & \status{Fertig} \\
  13 & Helium-Netzwerk Registrierung \& Decoder & 5\,h & \textasciitilde3\,h & \status{Fertig} \\
  \rowcolor{rowgray}
  14 & Backend: Pipeline zu HydroNode & 8\,h & \textasciitilde3\,h & \status{Fertig} \\
  15 & Website Echtzeit-Dashboard & 14\,h & 10\,h & \status{Fertig} \\
  \rowcolor{rowgray}
  16 & App: Verlaufsdiagramme & 6\,h & \textasciitilde6\,h & \status{Fertig} \\
  17 & App: Stationsverwaltung & 4\,h & \textasciitilde6\,h & \status{Fertig} \\
  \rowcolor{rowgray}
  18 & KI-Eval: Datensatz \& Modellauswahl & 8\,h & \textasciitilde2\,h & \status{In Arbeit} \\
  19 & KI-Eval: Testing \& Benchmarking & 8\,h & 0\,h & \status{Geplant} \\
  \rowcolor{rowgray}
  20 & Feldtest \& Abschlussdokumentation & 16\,h & \textasciitilde7\,h & \status{In Arbeit} \\
  \midrule
  \multicolumn{2}{l}{\textbf{Gesamt (inkl.\ 3D-Gehäuse, nicht geplant)}} & \textbf{160\,h} & \textbf{154\,h} & \\
\end{longtable}
\vspace{-1em}
\begin{center}
  \small\textit{Tabelle 2: Soll/Ist-Vergleich aller Features.}
  \label{tab:vergleich}
\end{center}

\noindent\textbf{Hinweis:} Die Ist-Stunden pro Feature sind Schätzungen. Im Arbeitstagebuch
wird nach Datum und Tätigkeit erfasst, nicht nach Feature-Nummer. Deshalb lassen sich
die Stunden nur näherungsweise zuordnen.

% ───────────────────────────────────────────────────────
\section{Stundenvergleich}
% ───────────────────────────────────────────────────────

Tabelle~\ref{tab:stunden} vergleicht die geplanten und tatsächlich aufgewendeten Stunden
gruppiert nach Bereich.

\begin{table}[H]
  \centering
  \begin{tabularx}{\textwidth}{X r r r}
    \toprule
    \textbf{Bereich} & \textbf{Geplant (h)} & \textbf{Ist (h, est.)} & \textbf{Differenz} \\
    \midrule
    Hardware, Beschaffung, Schaltplan & 17 & \textasciitilde9 & $-8$ \\
    Sensorik (5 von 6 Sensoren) & 12 & \textasciitilde11 & $-1$ \\
    Standalone-Tests & 8 & \textasciitilde3 & $-5$ \\
    PCB-Design, Bestellung, Inbetriebnahme & 9 & \textasciitilde50 & $+41$ \\
    Autarke Stromversorgung (Solar) & 13 & \textasciitilde7 & $-6$ \\
    Firmware (Deep-Sleep, LoRaWAN) & 19 & \textasciitilde21 & $+2$ \\
    Helium-Netzwerk \& Backend & 13 & \textasciitilde6 & $-7$ \\
    Website \& App & 24 & \textasciitilde23 & $-1$ \\
    KI-Evaluation & 16 & \textasciitilde2 & $-14$ \\
    Feldtest \& Dokumentation & 16 & \textasciitilde10 & $-6$ \\
    3D-Gehäuse (nicht geplant) & 0 & \textasciitilde12 & $+12$ \\
    \midrule
    \textbf{Gesamt (exakt laut Arbeitstagebuch)} & \textbf{160} & \textbf{154} & $-6$ \\
    \bottomrule
  \end{tabularx}
  \caption{Stundenvergleich Soll/Ist nach Bereichen (Ist-Werte geschätzt aus Arbeitstagebuch)}
  \label{tab:stunden}
\end{table}

\paragraph{Wichtigste Beobachtung:} Das PCB-Design hat mit ca.\ 50 Stunden weit mehr
Zeit gekostet als die geplanten 9 Stunden. Das entspricht einem Mehraufwand von rund
\textbf{+41 Stunden} in diesem Bereich. Dieser Mehraufwand wurde durch Einsparungen in
anderen Bereichen teilweise ausgeglichen: Helium und Backend liefen schneller als
erwartet, und die Standalone-Tests waren durch frühe Prototypentests bereits
abgedeckt. Der exakte Gesamtwert von 154 Stunden stammt direkt aus dem Arbeitstagebuch.

% ───────────────────────────────────────────────────────
\section{Abweichungen und Probleme}
% ───────────────────────────────────────────────────────

\subsection{PCB-Aufwand deutlich höher als geplant}

\textbf{Problem:} Im Projektplan waren 9 Stunden für das PCB eingeplant. Tatsächlich
wurden ca.\ 56 Stunden aufgewendet.

\textbf{Grund:} Das PCB wurde von Grund auf in EasyEDA neu entwickelt, da kein
geeignetes Open-Source-Design für den STM32WLE5JC mit allen benötigten Schnittstellen
existiert. EasyEDA ist ein browserbasiertes PCB-Design-Tool, das eng mit LCSC und
JLCPCB verknüpft ist und dadurch Bauteilauswahl und Fertigung vereinfacht. Hinzu kamen
mehrere Iterationen für RF-Design, Antennenmatching und Komponentenplatzierung. Nach
Erhalt der gefertigten Platine wurden ausserdem Bugs gefunden und behoben, unter
anderem ein fehlerhafter TPS63900-Spannungsregler. Das fertige Design wird auf
OSHWLab als Open-Source-Projekt veröffentlicht und nimmt am OSHWLab Open-Source-Contest
teil.

\textbf{Lösung:} Das Problem wurde in Absprache mit einem Experten analysiert; das
korrigierte PCB-Design soll für die bereits bestellten Boards funktionieren.
Als physischer Workaround wurde der fehlerhafte TPS63900 vom LiPo-Akku-Plus und dem
3{,}3-V-Netz getrennt und derselbe Chip als Breakout-Board an die PCB-Header angesteckt.
Das System läuft damit identisch wie zuvor, mit minimalem Overhead und gleicher Effizienz.
Die Solarladung wird nach finaler Verifikation freigeschaltet.

\subsection{Sensor-Wechsel}

\textbf{Situation:} Im Projektplan wurden bestimmte Sensoren als Kandidaten genannt.
Im Verlauf wurden leistungsfähigere Alternativen gewählt: BME280 wurde durch SHT45
und BMP390 ersetzt (genauer und energieeffizienter), VEML6075 durch LTR390
(breiterer UV-Messbereich, I2C statt analoger Ausgang).

\textbf{Bewertung:} Alle Sensoren laufen stabil. Die neuen Sensoren sind für den
Aussenbetrieb besser geeignet als die ursprünglich geplanten.

\subsection{Lautstärkesensor entfallen}

\textbf{Problem:} Feature 7 (Sensor Umgebungslautstärke, MAX4466, 3 Stunden geplant)
wurde aus dem Scope genommen.

\textbf{Grund:} Der Fokus lag auf den Kernfunktionen. Ein analoges MEMS-Mikrofon
erfordert zusätzliche Signalverarbeitung, die im verfügbaren Zeitrahmen nicht
sauber umgesetzt werden konnte.

\textbf{Lösung:} Das Feature wird als ``out of scope'' markiert. Die wichtigsten
Umweltdaten (Temperatur, Luftfeuchtigkeit, Luftdruck, UV, Feinstaub, CO${}_2$)
werden vollständig erfasst.

\subsection{KI-Evaluation noch nicht abgeschlossen}

\textbf{Problem:} Für die KI-Evaluation waren 16 Stunden geplant. Bisher wurden
erst ca.\ 2 Stunden investiert, da der PCB-Aufwand Priorität hatte.

\textbf{Lösung:} Die KI-Analyse ist bereits im Backend aktiv (Anomalieerkennung auf
Sensordaten). Eine formale Evaluation mit Modellauswahl und Dokumentation ist als
nächster Schritt geplant, sobald die Hardware vollständig stabil läuft.

\subsection{Nicht geplanter Mehraufwand: Gehäuse nach Stevenson-Screen-Prinzip}

\textbf{Situation:} Das Gehäuse-Design und der 3D-Druck wurde im Projektplan nicht
als eigenes Feature aufgeführt. Tatsächlich wurden ca.\ 11 Stunden für Design in
Fusion 360 und mehrere Druckdurchläufe aufgewendet.

\textbf{Warum dieser Aufwand nötig war:} Für eine korrekte Messung von
Aussentemperatur und Luftfeuchtigkeit darf sich das Gehäuse nicht durch Sonneneinstrahlung
aufheizen. Deshalb wurde das Design an einen Stevenson-Screen angelehnt: übereinander
liegende Lamellen blockieren direkte Sonneneinstrahlung und Regen, lassen aber
gleichzeitig Luft frei zirkulieren. Als Material wurde ASA gewählt, da ASA
UV-beständig, witterungsfest und für den dauerhaften Ausseneinsatz geeignet ist.
Der Druck erfolgte auf einem eigens für das Projekt angeschafften 3D-Drucker.

\subsection{Offener Punkt: UV-transparentes Glas für den UV-Sensor}

\textbf{Problem:} Der UV-Sensor LTR390 muss geschützt verbaut werden und trotzdem
UV-Licht empfangen können. Normales Glas oder transparentes PETG blockiert einen
grossen Teil der UV-Strahlung und verfälscht so die Messwerte.

\textbf{Stand:} Das passende UV-transparente Glas (Quarzglas oder Borosilikatglas)
würde mit Versand ca.\ 50 Euro kosten. Aktuell werden günstigere Alternativen
getestet, zum Beispiel dünne UV-transparente Kunststofffolien oder andere optische
Materialien, die UV-A und UV-B durchlassen. Dieses Detail ist für die Genauigkeit
der UV-Messung im Feldtest relevant.

% ───────────────────────────────────────────────────────
\section{Restarbeiten und Ausblick}
% ───────────────────────────────────────────────────────

Folgende Aufgaben stehen noch an:

\begin{enumerate}
  \item \textbf{Sensorplatine löten:} Eine eigene kleine Platine für den Stevenson-Screen
        wird noch gelötet. Sie wird über ein Datenkabel mit dem PCB verbunden und
        nimmt alle Sensoren passend auf.

  \item \textbf{3D-Druck Sensorhalterung:} Das abschliessende 3D-Modell für die
        Aufnahme der Sensorplatine im Stevenson-Screen muss noch gedruckt werden.

  \item \textbf{Solar-Autarkie:} Die vollständige Autarkie mit Solarversorgung muss
        noch validiert werden, insbesondere ob an bewölkten Tagen ausreichend Strom
        für den Dauerbetrieb erzeugt wird.

  \item \textbf{KI-Evaluation:} Datensatz aufbereiten, Modell auswählen
        und Ergebnisse dokumentieren.

  \item \textbf{Feldtest:} Station dauerhaft aufstellen (geplant an der OTH
        Regensburg), Langzeit-Integrationstests durchführen.

  \item \textbf{Abschlussdokumentation:} Alle Ergebnisse in der Studiendokumentation
        zusammenführen und finalisieren.
\end{enumerate}

\vspace{1em}
\noindent Der technische Kern des Projekts ist fertiggestellt. Die Station sendet
Sensordaten autark über LoRaWAN, die Daten sind in der App und auf der Website
einsehbar. Die verbleibenden Arbeiten betreffen hauptsächlich die Solar-Verifikation,
die KI-Evaluation und die Abschlussdokumentation.

\end{document}

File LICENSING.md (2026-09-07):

# Licensing

HydroNodeStation is a mixed hardware/software project, so different parts of
this repository carry different licences. All of them are OSI- or OSHWA-aligned
open-source licences. There is no non-commercial restriction anywhere.

| Part of the project | Paths | Licence | SPDX |
|---|---|---|---|
| **Hardware design**: schematic, PCB, CAD enclosure models | `hardware/` | CERN Open Hardware Licence Version 2, Strongly Reciprocal | `CERN-OHL-S-2.0` |
| **Documentation and media**: docs, reports, images, renders | `doc/`, `README.md` | Creative Commons Attribution-ShareAlike 4.0 International | `CC-BY-SA-4.0` |
| **Firmware**, own code | see list below | MIT | `MIT` |
| **Firmware**, third party | `stm32_node/Drivers/`, `stm32_node/Middlewares/`, `stm32_node/Utilities/` | unchanged upstream terms | see below |

Copyright © 2026 Felix Knoll (TexhFexLabs), unless stated otherwise.

Full licence texts are in [`LICENSES/`](LICENSES/). The repository root
[`LICENSE`](LICENSE) contains CERN-OHL-S v2, because the hardware design is the
defining artefact of this project.

---

## Why these licences

**CERN-OHL-S v2 for the hardware.** It is the reference licence for open-source
hardware and it is *strongly reciprocal*: anyone may study, build, modify, and
sell this board, but if they distribute a modified design they must release
their changes under the same terms. The community keeps the derivatives.

**CC BY-SA 4.0 for the documentation.** Same reciprocal idea, applied to text
and images. Creative Commons explicitly recommends against using CC licences
for hardware designs or software, which is why they are scoped to documentation
only here.

**MIT for the firmware.** No friction. Anyone can lift a sensor driver from this
repository into a completely unrelated project without licence contamination.
Sensor drivers are exactly the kind of code that should be trivially reusable.

---

## Firmware: own code (MIT)

The following files were written for this project and are MIT licensed:

```
stm32_node/Core/Inc/bmp390.h          stm32_node/Core/Src/bmp390.c
stm32_node/Core/Inc/bq25185.h         stm32_node/Core/Src/bq25185.c
stm32_node/Core/Inc/ltr390.h          stm32_node/Core/Src/ltr390.c
stm32_node/Core/Inc/max17048.h        stm32_node/Core/Src/max17048.c
stm32_node/Core/Inc/scd41.h           stm32_node/Core/Src/scd41.c
stm32_node/Core/Inc/sht45.h           stm32_node/Core/Src/sht45.c
stm32_node/Core/Inc/sps30.h           stm32_node/Core/Src/sps30.c
stm32_node/Core/Inc/sw_uart.h         stm32_node/Core/Src/sw_uart.c
stm32_node/Core/Inc/nvm_store.h       stm32_node/Core/Src/nvm_store.c
stm32_node/Core/Inc/power_policy.h    stm32_node/Core/Src/power_policy.c
stm32_node/Core/Inc/runtime_health.h  stm32_node/Core/Src/runtime_health.c
stm32_node/Core/Inc/debug_profile.h   stm32_node/Core/Src/debug_profile.c
stm32_node/tests/                     doc/payload-decoder.js
```

**Mixed files.** `stm32_node/Core/Src/*.c` and `stm32_node/LoRaWAN/App/*.c` that
were generated by STM32CubeMX keep their original STMicroelectronics copyright
header. The project's own logic in those files lives inside the
`/* USER CODE BEGIN */ … /* USER CODE END */` blocks and is contributed by the
author under MIT. The generated scaffolding around it stays under ST's terms.

## Firmware: third-party components

Vendored and left untouched. Their original licences apply in full:

| Component | Origin | Licence |
|---|---|---|
| STM32WLxx HAL / LL drivers | STMicroelectronics | BSD-3-Clause |
| CMSIS Core | Arm Limited | Apache-2.0 |
| LoRa Basics Modem (`smtc_modem_*`) | Semtech / STMicroelectronics | BSD-3-Clause (Revised) |
| Sequencer, timer server, low-power manager | STMicroelectronics | BSD-3-Clause |

Nothing in this repository relicenses those components.

---

## Reusing this project

**You may**, under the terms above:

- build the board, for yourself or commercially
- modify the schematic, PCB, and enclosure
- sell assembled stations
- lift the firmware drivers into your own projects
- reuse the documentation

**You must**, in return:

- credit the original project (all three licences require attribution)
- release modified *hardware designs* under CERN-OHL-S v2 (hardware reciprocity)
- release modified *documentation* under CC BY-SA 4.0

The MIT-licensed firmware carries no reciprocity requirement.

## Notice for redistribution

If you build and distribute hardware based on this design, CERN-OHL-S v2 §3.3
requires you to pass on the design files (or a written offer for them) together
with the product, and to keep the licence notices intact.

## Trademarks

"HydroNode" and "TexhFexLabs" are not licensed under any of the above. You may
state that your device is based on HydroNodeStation; do not present it as an
official HydroNode product.

## Datasheets

`hardware/datasheets/` contains manufacturer datasheets and application notes
(STMicroelectronics, Sensirion, Bosch, Seeed Studio). Those documents are the
property of their respective manufacturers, are included here purely for the
convenience of anyone reproducing the board, and are **not** covered by this
project's licences.

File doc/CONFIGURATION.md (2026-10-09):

# Configuration reference (firmware 2.0, PCB 1.1)

Firmware 2.0 targets hardware revision 2 (PCB 1.1). Boards of revision 1 stay on firmware 1.6.x: the pin map differs (charger CE, RF switch supply, switched rails, INA226) and 2.0 does not run on them.

For fault recovery, migration and hardware test requirements see [RELIABILITY.md](RELIABILITY.md).

## Credentials

Put production credentials in `stm32_node/LoRaWAN/App/se-identity-local.h`, which is ignored by Git. Use the same four `LORAWAN_DEVICE_EUI`, `LORAWAN_JOIN_EUI`, `LORAWAN_APP_KEY`, and `LORAWAN_GEN_APP_KEY` macro names as in `se-identity.h`. Do not edit the tracked default header or use skip-worktree to hide production keys. Byte lists use comma-separated hexadecimal tokens without `0x`, as in the default header. An all-zero DevEUI selects the silicon-derived ID; a nonzero one is respected.

## Build flags

`Core/Inc/sys_conf.h`:

| Flag | Release | Meaning |
|---|---|---|
| `APP_LOG_ENABLED` | 0 | Trace over USART1 (H1, PB6/PB7). The Debug preset sets 1. |
| `DEBUGGER_ENABLED` | 0 | Keeps SWD alive in STOP2. Never routes probe lines onto board pins. |
| `LOW_POWER_DISABLE` | 0 | 0 enables STOP2. |
| `SCD41_ENABLED` | 1 | 0 excludes all CO2 work; port 3 is then never sent. |
| `PULSE_COUNTERS_ENABLED` | 0 | 1 counts contacts on PA4 and PA5 (see below). 0 keeps the pins analog and sends `0xFFFF` in both counter fields. |

Both CMake presets (Release, Debug) target the STM32WLE5 on PCB 1.1. `stm32_node.ioc` is frozen and must not be regenerated, see `stm32_node/CLAUDE.md`.

## Pins (PCB 1.1)

| Net | Pin | Use |
|---|---|---|
| `EN5V` | PA9 | 5 V rail (SPS30). On from boot, stays on; the SPS30 sleeps over I2C. |
| `EN3V3SW` | PA8 | Switchable 3.3 V rail. Off; nothing on this station uses it. |
| `CHG_CE` | PA2 | BQ25185 CE. Analog = charging (R7 pulls low), push-pull high for the 500 ms pulse every 2 h. |
| `RF_SW_VDD` / `RF_SW_CTRL` | PB12 / PC13 | RF switch supply and select, see RELIABILITY.md. PB0 (VDD_TCXO) is never driven. |
| `SOLAR_ADC` | PB2 (ADC_IN4) | Panel voltage through 150 k / 100 k, factor 2.5. |
| `MAX17048_ALRT` | PA0 | Analog, not used (gauge runs in hibernate). |
| `CNT1` / `CNT2` | PA4 / PA5 | Contact counters, only with `PULSE_COUNTERS_ENABLED`. |
| `DIP3_DEBUG` / `DIP4_INSTALL` | PB4 / PB8 | Read once at boot, active low. |
| `LED1` / `LED_DIAG` | PB5 / PB3 | Low-active, visible only with DIP 1 / DIP 2 closed. |
| `DBG_UART` | PB6 / PB7 | USART1 on H1, only while the debug profile or a trace writes. |

I2C2 on PA11 (SDA) / PA12 (SCL) carries SHT45 0x44, BMP390 0x77, LTR390 0x53, SCD41 0x62, SPS30 0x69, MAX17048 0x36 and INA226 0x40. The Qwiic connector CN2 (always powered from VCC) is on the same bus; firmware 2.0 has no driver for it, see [ADDING_SENSORS.md](ADDING_SENSORS.md). Unused pins are analog.

## Timing and energy

| Setting | Default | Location |
|---|---|---|
| Uplink interval | 180 s, downlink `10 HH LL` or `14` sets 30 to 3600 s and applies at once | `LoRaWAN/App/lora_app.h` |
| TX power | EIRP from the stack (EU868 16 dBm) minus `BOARD_ANTENNA_GAIN_DB` (2) = conducted power | `LoRaWAN/Target/radio_board_if.h` |
| Fault frames (fPort 99) | urgent with the next uplink, the rest at most hourly, counters daily | `Core/Inc/fault_report.h` |
| Settings report (fPort 6) | after every join, after every `10`/`14`, otherwise daily | `Core/Inc/device_settings.h` |
| SCD41 first / useful shot | 12 / 6 s before the uplink | `lora_app.h` |
| SPS30 start | 16.5 s before the uplink | `lora_app.h` |
| Solar sample (INA226 + ADC) | every 30 s in NORMAL and SAVE | `lora_app.c` |
| MAX17048 | hibernate, measures every 45 s on its own | `max17048.c` |
| Link check | 24 h after the join, then daily; rejoin after 3 unanswered days | `Core/Inc/link_check.h` |
| Charger CE pulse | 500 ms every 2 h | `lora_app.c` |
| Maximum STOP2 sleep | 8 s for the independent watchdog | `Core/Inc/runtime_health.h` |

### Power modes

The measurement plan follows the battery. The four thresholds have defaults in `Core/Inc/power_policy.h` (starting values to validate against the installed cell and its protection circuit) and can be changed by downlink `14` since firmware 2.1. The table shows the defaults; SAVE always ends at Save + 150 mV.

| Mode | Enter | Leave | Interval | CO2 | PM | Radio |
|---|---|---|---|---|---|---|
| NORMAL | | | 180 s | every 5th round | every 10th round | yes |
| SAVE | below Save (3500 mV) | Save + 150 (3650 mV) | 2 × interval | every 10th round (hourly) | no | yes |
| RECOVERY | below Recovery (3300 mV) or 3 invalid readings | Resume (3600 mV) stable for 60 s | none | no | no | off |
| Standby | in RECOVERY, 2 valid readings in a row below Standby (3200 mV) | wake-up every 60 min, boot at Resume (3600 mV) or more | none | no | no | off |

The station checks new thresholds against the same rules as the backend: every value 2800 to 4200 mV, Standby at least 50 mV below Recovery, Recovery at least 50 mV below Save, Resume at least 100 mV above Recovery and at most 400 mV above Save.

The battery is checked every 60 s. An invalid reading never leads into Standby: a missing measurement is no undervoltage. Mode changes are reported on fPort 99 (`0x0320`/`0x8320` SAVE, `0x0321`/`0x8321` RECOVERY). RECOVERY entry and exit leave together once the radio is back.

Standby turns off everything except VCC, the RTC with its LSE and the fuel gauge. The INA226 is shut down, the RF switch is off, and the EN pins float so the 1 MΩ pull-downs switch off the 5 V and 3V3SWITCHABLE rails. Waking up is a reset: the boot sees `PWR_FLAG_SB`, reads only the MAX17048, and goes back to Standby below Resume. Standby keeps Resume in the RTC backup register DR8, so these hourly checks never read flash. The full boot afterwards reports `0x0540` with reason 8.

**Option byte IWDG_STDBY.** The independent watchdog must be frozen in Standby, otherwise it resets the MCU after a few seconds. Clear `IWDG_STDBY` once when setting up a board, with STM32CubeProgrammer (Option bytes, User configuration, uncheck IWDG_STDBY) or `STM32_Programmer_CLI -c port=SWD -ob IWDG_STDBY=0`. The firmware checks `FLASH->OPTR` at every boot. Without the setting the station never enters Standby, stays in RECOVERY, and reports `0x0544` at every boot.

## DIP switches

| DIP | Function |
|---|---|
| 1 | Connects LED1 (PB5). Open: LED1 stays dark whatever the firmware does. |
| 2 | Connects LED_DIAG (PB3). |
| 3 | Debug profile: no LoRaWAN, all sensors (with INA226 V/I/P, solar ADC, SOC, charge rate, board temperature and counters) read in a loop and printed over USART1 on H1, 115200 baud. Wins over DIP 4. |
| 4 | Installation mode: after the first join, 30 min of 60-second uplinks on port 2 (the modem keeps the duty cycle), a link check after every 3rd accepted uplink, at most 10 per run. Normal operation afterwards until the next boot. |

DIP 3 and 4 are read once at boot with a short internal pull-up (closed = low); the pins are analog afterwards, so a closed switch draws no current.

## LEDs

| Phase | LED1 (DIP 1) | LED_DIAG (DIP 2) |
|---|---|---|
| Boot until the first uplink | short flash per join attempt, double flash on join, one flash for the first uplink; dark at the latest 30 min after boot | |
| Installation mode | 50 ms flash per accepted uplink; link check answer: one flash per gateway (max. 5), no answer: one long flash (1 s) | |
| Fault | | reason, pause, failing step (see RELIABILITY.md); reason 6 (LSE) and 8 (before Standby) as well |

Outside these patterns both pins are analog.

## Contact counters

With `PULSE_COUNTERS_ENABLED=1`, PA4 (counter 1, rain gauge, 50 ms lockout) and PA5 (counter 2, anemometer, 2 ms lockout) count falling edges through EXTI without internal pull-ups. LPTIM2 would count without waking up, but it does not run in Stop 2, so both channels use EXTI. The board's RC filter (1 MΩ / 1 nF) is meant for contacts up to about 50 Hz; fast signals are not supported. Counts are reported per block (see below) and saturate at `0xFFFE`.

## Downlinks (fPort 2)

| Payload | Action |
|---|---|
| `10 HH LL` | Set the interval in seconds, 30 to 3600. Stored in flash, then the next round is scheduled from now. The settings revision stays. |
| `14 RR II II SS SS CC CC BB BB UU UU` | Set interval and battery thresholds at once (firmware 2.1, 12 bytes, see below). |
| `11` | SPS30 fan cleaning, only in NORMAL with a valid battery reading |
| `12` | Diagnostic response on fPort 5 |
| `FF` | Restart. Stores reason 7 first; the acknowledgement is the `0x0540` entry with reason 7 after the boot. |

Every non-empty downlink on fPort 2 is acknowledged on fPort 99 as code `0x06CC` (CC = command byte) with the result in the detail. Empty downlinks and other ports are ignored without an acknowledgement. The acknowledgement leaves with the next fPort 99 frame, not at once.

| Result | Meaning |
|---|---|
| 0 | executed (`10`: the new interval is in effect; `14`: the new values are in effect) |
| 1 | length or parameter invalid |
| 2 | refused because of battery or power mode |
| 3 | could not be saved (`10`/`14`: nothing changes) |
| 4 | unknown command |
| 5 | the modem did not accept the reply (`12`) |
| 6 | execution failed (`11`: SPS30 did not respond or cleaning did not start) |

### Settings (`14`, firmware 2.1)

| Off | Field | Type |
|---|---|---|
| 0 | `0x14` | u8 |
| 1 | Revision, 1 to 255 (0 is reserved for factory values) | u8 |
| 2 | Interval, 30 to 3600 s | u16 |
| 4 | Save mV | u16 |
| 6 | Recovery mV | u16 |
| 8 | Standby mV | u16 |
| 10 | Resume mV | u16 |

Example: `14 07 0258 0D7A 0CB2 0C1C 0DDE` sets revision 7, 600 s, Save 3450, Recovery 3250, Standby 3100 and Resume 3550 mV. A wrong length, revision 0 or a value outside the rules answers `0x0614` with result 1 and changes nothing. Otherwise the station stores everything in one flash write, uses the interval from now and the thresholds from the next battery check, and answers result 0 (or 3 when the flash write failed). In every case the settings report on fPort 6 follows, so the backend sees the values in effect. The HydroNode backend sends `14` through its downlink integration (Profile, LoRaWAN).

The values live in the NVM config area next to the 2.0 interval record (one 16-byte record: version, revision, interval, four thresholds, CRC-16). A station updated from 2.0 starts with the default thresholds and its stored interval. A broken record means defaults and `0x0543` with detail 11.

## Payloads

All fields are big-endian. Every port has one fixed length. Missing unsigned values are `0xFFFF`, missing signed values `0x8000`. Decoder: [payload-decoder.js](payload-decoder.js).

| fPort | Bytes | Content |
|---|---|---|
| 2 | 32 | Base (10) + block (22) |
| 3 | 34 | Base (10) + CO2 (2) + block (22) |
| 4 | 32 | Base + CO2 + PM, no block (as in 1.x) |
| 5 | 26 | Diagnostics on request, layout in RELIABILITY.md |
| 6 | 18 | Settings report (firmware 2.1), below |
| 99 | 4 to 32 | Faults, events, command acknowledgements |

Port 4 carries no block: 54 bytes would not fit DR0 to DR2 (51 bytes in EU868). Its block values flow into the next port 2 or 3 frame.

**Base.** Temperature i16 0.01 °C, relative humidity u16 0.01 %, pressure u16 0.1 hPa, battery u16 mV, UV index u16 0.01. CO2 u16 ppm. Port 4 continues with PM1/2.5/4/10 u16 0.1 µg/m³, NC0.5/1/2.5/4/10 u16 0.1 #/cm³ and typical particle size u16 0.001 µm. Port 4 keeps its CO2 slot as missing when CO2 is disabled.

**Block** (offset from the start of the block):

| Off | Field | Type | Unit | Missing |
|---|---|---|---|---|
| 0 | Solar voltage INA226, mean | u16 | mV | `0xFFFF` |
| 2 | Solar current INA226, mean | u16 | 0.1 mA | `0xFFFF` |
| 4 | Solar power, mean | u16 | mW | `0xFFFF` |
| 6 | Solar energy since the last block | u16 | 0.1 mWh | `0xFFFF` |
| 8 | Sunshine time since the last block | u16 | s | `0xFFFF` |
| 10 | Solar voltage ADC PB2, mean | u16 | mV | `0xFFFF` |
| 12 | State of charge | u16 | 0.01 % | `0xFFFF` |
| 14 | Charge rate | i16 | 0.01 %/h | `0x8000` |
| 16 | Board temperature | i16 | 0.01 °C | `0x8000` |
| 18 | Counter 1 (PA4) since the last block | u16 | pulses | `0xFFFF` = off |
| 20 | Counter 2 (PA5) since the last block | u16 | pulses | `0xFFFF` = off |

"Since the last block" means since the last block the modem accepted. Sums saturate at `0xFFFE`. Sunshine counts a 30-second sample when the panel delivers more than 68 mW or the ADC sees more than 5.5 V. Backend layouts may leave the counters out; surplus bytes are ignored.

**Settings report** (fPort 6, unconfirmed, after every join behind the boot frame, after every `10`/`14` and otherwise daily, never in RECOVERY; one more uplink only when it is due):

| Off | Field | Type |
|---|---|---|
| 0 | Layout version (1) | u8 |
| 1 | Firmware major | u8 |
| 2 | Firmware minor | u8 |
| 3 | Hardware (2 = PCB 1.1) | u8 |
| 4 | Revision (0 = factory values) | u8 |
| 5 | Power mode (0 NORMAL, 1 SAVE, 2 RECOVERY) | u8 |
| 6 | Interval s | u16 |
| 8 | Save mV | u16 |
| 10 | Recovery mV | u16 |
| 12 | Standby mV | u16 |
| 14 | Resume mV | u16 |
| 16 | Flags: bit 0 Standby possible (IWDG_STDBY cleared), bit 1 values from the stored record, bit 2 contact counters built in | u16 |

Example with the factory values: `01 02 01 02 00 00 012C 0DAC 0CE4 0C80 0E10 0001`.

Firmware 1.x frames (port 2 with 10 bytes, port 3 with 12) still decode without the block, so a station keeping its DevEUI stays readable during the swap. Port 2 grows from 10 to 32 bytes; at SF12 an uplink takes about 1.5 s instead of 1.0 s, so the TTN fair use (30 s uplink airtime per day) gets tight at 180 s on poor links.

## Faults and events (fPort 99)

Unconfirmed uplink, 1 to 8 entries of 4 bytes: code u16 + detail u16. Code bit 15 = resolved (1) or occurred (0), bits 14..8 = category, bits 7..0 = part or event. The table is `stm32_node/Core/Inc/fault_codes.h`; codes are wire format and never renumbered.

| Category | Meaning | Bit 15 | Detail |
|---|---|---|---|
| `0x01` | Part not found at start | yes | 7-bit I2C address, otherwise 0. Resolved: 0 |
| `0x02` | Read errors in operation (3 in a row) | yes | HAL I2C error bits of the last attempt, otherwise 0. Resolved: failed attempts, saturating |
| `0x03` | Supply | yes | battery mV, `0xFFFF` unknown |
| `0x04` | Radio / LoRaWAN | no | see below |
| `0x05` | System | no | see below |
| `0x06` | Command acknowledgement | no | result, see Downlinks |

Parts for `0x01`/`0x02`: `0x01` SHT45, `0x02` BMP390, `0x03` LTR390, `0x04` SCD41, `0x05` SPS30, `0x06` MAX17048, `0x07` INA226, `0x08` solar ADC, `0x09` internal temperature sensor, `0x10` I2C bus (recovery failed).

| Code | Event | Detail |
|---|---|---|
| `0x0320` | SAVE | battery mV |
| `0x0321` | RECOVERY | battery mV |
| `0x0323` | Battery reading invalid | battery mV or `0xFFFF` |
| `0x0430` | Rejoined after the link check | days without an answer |
| `0x0431` | Uplink not sent (TX done "not sent"), once a day | count in that day |
| `0x0432` | Uplink request rejected (not BUSY/NO_TIME), once a day | count in that day |
| `0x0540` | Restart | high byte: reason, low byte: reset flags |
| `0x0541` | Firmware version | major << 8 \| minor, `0x0200` |
| `0x0542` | LSE started in the second attempt | attempts |
| `0x0543` | NVM error | last NVM error code |
| `0x0544` | Option byte IWDG_STDBY not cleared, no Standby | 0 |
| `0x054F` | Queue overflow | dropped entries |

Restart reasons (high byte of `0x0540`): 0 none, 1 HAL, 2 CPU, 3 modem, 4 missing progress, 5 NVM, 6 LSE, 7 command `FF`, 8 Standby wake-up. Reset flags (low byte): bit 0 pin, 1 brown-out, 2 software, 3 IWDG, 4 WWDG, 5 low-power, 6 option byte, bit 7 free.

Examples: `0102 0077` = BMP390 not found at start; `0205 0004` = SPS30 read errors (NACK); `8205 0007` = SPS30 reads again after 7 failed attempts; `0540 0001` + `0541 0200` = boot after a pin reset, firmware 2.0.

**Sending.** States (`0x01`-`0x03`) are reported once on entry and once on exit; repeated errors while a state is active add nothing. Events are reported per occurrence, except `0x0431`/`0x0432`: they are counted and reported once a day, only when the count is not 0. After every boot, once after the join, `0x0540` and `0x0541` leave in one frame.

Entries are urgent or normal. Urgent: boot info (`0x0540`-`0x0542`, `0x0544`), rejoin `0x0430`, part not found (`0x01`), supply (`0x03`) and command acknowledgements (`0x06`). They make a frame due with the next regular uplink. Everything else (read errors, NVM, the daily counters, overflow) waits until an hour has passed since the last fault frame, or rides along with an urgent one. A frame carries up to 8 entries, so a burst costs one uplink.

A part whose read errors open again within 6 h of its last report is flapping: the new open is reported, but "resolved" follows only after 6 h of good reads, and its detail counts every failed read since the open. One open and close per part and 6 h, at most one more open.

A RAM queue holds 16 entries; at most one fPort 99 frame per round, right after the accepted regular uplink. The rest follows in a later round. On overflow the oldest resolved entries go first, then the oldest; `0x054F` reports the loss. Nothing survives a reset except the restart reason (RTC backup DR6/DR7). Each frame costs one extra uplink, and only when something happened.

The HydroNode backend shows every entry in the device console, keeps open states in the monitoring status and can mail them (off by default). Because nothing survives a reset, the boot entry `0x0540` closes all open states; what is still broken is reported again right after it, and a state back within 24 h counts as the same fault (same "since", no second mail).

RF region is selected by `ACTIVE_REGION` in `lora_app.h`; the compiled region set is in `LoRaWAN/Target/lorawan_conf.h`.

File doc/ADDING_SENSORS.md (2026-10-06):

# Adding a sensor (Qwiic / I2C)

PCB 1.1 has a Qwiic connector, **CN2**: a 4-pin JST-SH (1 mm) socket with GND, 3.3 V, SDA, SCL. Qwiic (SparkFun) and STEMMA QT (Adafruit) breakouts plug straight in, and further boards can be chained. Firmware 2.0 ships no driver for anything on CN2; this page shows where your own code goes. Every place is marked in the source with a comment starting `ADD YOUR SENSOR`, so `grep -rn "ADD YOUR SENSOR" stm32_node` lists them all.

## Before you plug something in

- **Same bus.** CN2 is wired to I2C2 (PA11 SDA, PA12 SCL, 4.7 kOhm pull-ups to VCC) together with the built-in parts. Used addresses: `0x36` MAX17048, `0x40` INA226, `0x44` SHT45, `0x53` LTR390, `0x62` SCD41, `0x69` SPS30, `0x77` BMP390. Your part needs a different one.
- **Always powered.** CN2's 3.3 V comes from VCC, which is never switched off. Pick a part with a sleep or one-shot mode and put it to sleep after each reading, otherwise its idle current runs the battery down. A part that has to be cut off completely belongs on 3V3SWITCHABLE (connector P4), switched with `PowerRail_3V3Sw_Activate()` / `PowerRail_3V3Sw_Deactivate()` in `Core/Src/power_rail.c`.
- **One faulty module disturbs everything.** A breakout that holds SDA low blocks all sensors; the station then reports read errors for the other parts and `0x0210` (bus recovery failed) on fPort 99. Breakouts with their own pull-ups add to the board's 4.7 kOhm; with several of them, remove theirs.

## Step by step

1. **Driver.** Add `Core/Inc/<part>.h` and `Core/Src/<part>.c`, modelled on `sht45.c`: blocking `HAL_I2C_*` calls on `hi2c2` with a timeout, return codes, values as integers in a fixed unit (e.g. 0.01 degC), never floats on the wire. Add the `.c` file to the source list in `cmake/stm32cubemx/CMakeLists.txt`.
2. **Fault id.** Add `FAULT_COMP_<PART>` in `Core/Inc/fault_codes.h`. Ids `0x0A` to `0x0F` are free; beyond that raise `FAULT_COMPONENTS` in `fault_report.h` (at most `0x20`). Add the same id with its name to the backend table (`DeviceFaultCodes.COMPONENTS` in hydronode-backend) and to `PARTS` in `doc/payload-decoder.js`, so missing parts and read errors show up with a name instead of "Code 0x01NN".
3. **Data field.** Add a field to `sensor_t` in `Core/Inc/sys_sensors.h` and a free `SENSOR_VALID_*` bit (bits 6 to 15).
4. **Init.** In `EnvSensors_Init()` (`Core/Src/sys_sensors.c`): call your init and `Fault_ComponentInit(FAULT_COMP_<PART>, found, address)`.
5. **Read.** In `EnvSensors_Read()`: read, store the value, set the valid bit, call `note_result(FAULT_COMP_<PART>, ok)`, and `I2C2_RecoverBus()` after a failure, like the blocks above it. Three failures in a row become a read-error report on fPort 99 automatically.
6. **Sleep.** In `EnvSensors_Sleep()`: put the part back to sleep.
7. **Slow parts.** A part that needs seconds to measure gets a pre-measurement timer like the SCD41 (`ScheduleNextRound()` in `LoRaWAN/App/lora_app.c`). The timer callback only posts an event; the I2C work runs in `ProcessSensorEvents()`. Never touch I2C from a timer or interrupt.
8. **Send.** Ports 2, 3 and 4 have fixed lengths that backend layouts depend on; do not change them. Give your data its own port instead, for example fPort 6 = port 2 plus your bytes: a new constant and layout in `Core/Inc/payload.h` / `Core/Src/payload.c`, selected in `Payload_Port()`. Same length on every send, missing values as `0xFFFF` (unsigned) or `0x8000` (signed), at most 51 bytes so the frame still fits DR0 to DR2 in EU868. In HydroNode, add a layout for the new fPort in the sensor's LoRaWAN settings and enter the missing value per channel.
9. **Debug output.** Print the value in `DebugProfile_Run()` (`Core/Src/debug_profile.c`) so DIP 3 shows it on H1.
10. **Check.** `python3 tests/run_tests.py`, `node tests/test_decoder.js`, `cmake --build --preset Release`. Keep the last 8 KiB of flash free (the linker map shows the size).

Scaling and conversions are easiest to get right as a small host test in `stm32_node/tests/`, like `test_payload.c`.

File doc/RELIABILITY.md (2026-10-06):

# Long-term operation (firmware 1.6 and 2.0)

Firmware 2.0 runs on PCB 1.1 and keeps every mechanism of 1.6 below. What 2.0 adds for the new board is in [Firmware 2.0 (PCB 1.1)](#firmware-20-pcb-11) at the end.

The reproducible outage is in the STM32 LoRaWAN port: `SysTimeToMs(SysTimeGet()) / 1000` produces seconds from a wrapping 32-bit millisecond value. After 49.710 days, an alarm spanning the wrap has a deadline larger than the largest value this clock can ever return. No further periodic uplink occurs, even with a full battery. This defect matches the reported symptom; the historical field failures were not captured with a debugger.

## Implemented changes

| Area | Behavior in 1.6 |
|---|---|
| Time | All 44 affected middleware expressions use monotonic MCU seconds. The RTC epoch read accounts for a pending underflow interrupt and a wrap during the read. HAL_GetTick returns milliseconds; a temporary SysTick provides bounded startup timeouts. |
| Recovery | Independent IWDG starts before peripheral initialization. STOP2 sleeps are capped at 8 seconds; only thread-mode progress feeds the watchdog. Missing measurement cycles have a separate deadline (interval + 600 seconds); queued TX has a 900-second limit. Faults reset the MCU and preserve a reason in RTC backup registers. |
| Sensor scheduling | Sensor timer callbacks set flags only. The main loop serializes I2C work; the SCD41 driver no longer deinitializes the bus underneath other sensors. Late premeasurement events are discarded. Short device command delays remain bounded main-loop waits. |
| SPS30 | Stop waits 20 ms before Sleep; command errors propagate; initialization handles a sensor still measuring after a MCU-only reset. Failed shutdown attempts trigger recovery. A true sensor power cycle still requires suitable hardware. |
| Battery | Checks precede heavy work. NORMAL, SAVE and RECOVERY have hysteresis. Missing battery measurements never enable sensor loads or flash writes. Radio/sensor initialization is deferred at a low-voltage boot. |
| Joining | Standard modem join backoff is enabled. Unsuccessful attempts run in at most five-minute windows, followed by 5/10/20/40/60-minute pauses. There is no periodic reboot merely because the gateway is absent. |
| Flash | Two CRC-protected snapshots with sequence and final commit marker. Only the inactive page is erased. Legacy context/config is migrated without erasing the old pages. Unchanged data is not rewritten; failed nonce writes stop the join. |
| Data | Missing sensor values use explicit sentinels. The supplied decoder handles negative temperatures, missing data and malformed frames. Port 4 retains its CO2 slot even when SCD41 is disabled. |
| Credentials | `se-identity-local.h` supplies ignored local credentials. Tracked header contains defaults and no hidden skip-worktree changes. Debug logs print DevEUI, never keys. |
| Energy | Normal cadence is unchanged. Production UART/DWT reinitialization and activity LED are disabled. SPS30 sleep sequencing is corrected. No measured percentage saving is claimed. |

## Battery policy

Defaults are conservative starting values for a 1S LiPo, configurable in `Core/Inc/power_policy.h`. Validate against the actual cell and load behavior.

- Normal: default 180-second uplinks, CO2 every fifth and PM every tenth uplink.
- Below 3500 mV: SAVE doubles the interval. Return to NORMAL at 3650 mV.
- Below 3300 mV, or after three failed voltage reads: RECOVERY cancels sensor timers and radio activity. Check the battery every 60 seconds; wake briefly every at most 8 seconds for watchdog supervision.
- Recovery exit: at least 3600 mV on checks spanning 60 seconds. Below this threshold or on a failed reading, restart the stability interval. Sensor setup and join then resume automatically.
- A boot with insufficient/unknown voltage starts in RECOVERY. A healthy boot does not need the recovery delay.

The firmware cannot physically disconnect the permanently supplied sensors or protect an unprotected cell below MCU operating voltage. In the supplied schematic, BQ25185 TS/MR uses a fixed 10-kOhm resistor, so it does not measure battery temperature. An appropriate battery NTC and verified hardware undervoltage/restart path remain necessary for outdoor winter operation. The charger CE pulse remains independent every two hours; changing a working charging circuit without measured status/temperature feedback would be unjustified. The physical regulator workaround was not identified as the reported outage cause.

## Persistence and flashing

Application code is limited to 248 KiB. `0x0803E000` and `0x0803E800` store new snapshots. `0x0803F000` and `0x0803F800` remain the legacy context/config; an unused doubleword at `0x0803F7F8` marks migration. Do not mass-erase these pages during a routine upgrade. Do not downgrade to legacy firmware using stale nonce records; reprovision if a downgrade is required. Boot after an interrupted first migration uses a valid new snapshot or the original context. Once migration is marked, two invalid snapshots cause a fault instead of silently restoring obsolete nonces.

The first page rewrite implementation has been bypassed for application and modem state. `flash_if.c` remains available for legacy interfaces but is no longer used by these persistence callbacks. Read/write callbacks validate context type, offset and size. Flash writes require a valid battery reading at or above the recovery threshold. Reads of interrupted flash records handle ECC errors only while accessing those records; other CPU/NMI faults reset.

A write is reported successful once its snapshot is committed and verified. The migration marker is set afterwards and never decides the result: reporting a committed write as lost would reset the MCU over data that is safe. Because the legacy `flash_if.c` reprogrammed whole pages including their unused tail, the marker doubleword reads erased on an upgraded board but cannot be programmed again; the marker step therefore erases the legacy context page once before retrying. That page is obsolete at this point, since the snapshot being marked already carries the migrated content.

A fault blinks its reason on the diagnostic LED (PB3), then after a pause the failing step, and stores both in `RTC_BKP_DR6`/`DR7` for the next boot and the `0x12` diagnostic. Without this an unattended reset is undiagnosable: trace and debugger are disabled in the production build.

The modem performs OTAA after a restart; this is not full session continuation. Repeated power loss, flash endurance, oscillator failures and supply ramps still require physical fault-injection tests.

## Payload compatibility and diagnostics

Firmware 2.0 sends 32/34/32 bytes on fPort 2/3/4 (ports 2 and 3 end in the solar and fuel gauge block) and fault frames on fPort 99, see [CONFIGURATION.md](CONFIGURATION.md). Scaling of the base fields is unchanged. Missing unsigned fields are `0xFFFF`; missing signed fields are `0x8000`. Consumers must decode these as missing, not large numeric readings. Use [payload-decoder.js](payload-decoder.js); it still reads 1.x frames. The HydroNode backend marks such channels with a per-channel missing value and reads fPort 99 without a layout.

Downlink `0x12` on fPort 2 requests a diagnostic uplink on fPort 5 (26 bytes, big-endian; byte 14 is the fault reason, byte 15 the failing step, bytes 22-23 the modem anomaly count, byte 24 the NVM error count and byte 25 the last NVM error). This optional response can be deferred/rejected by a busy modem; it is not sent automatically every cycle.

| Offset | Field |
|---|---|
| 0 | Version = 1 (u8) |
| 1 | Power mode: 0 normal, 1 save, 2 recovery (u8) |
| 2 | MCU RTC seconds (u32; RTC can retain time across software resets) |
| 6 | Boot count (u32, RTC backup retained while powered) |
| 10 | RCC reset flags captured at boot (u32) |
| 14 | Previous explicit fault: 0 none, 1 HAL, 2 CPU, 3 modem, 4 missing progress, 5 NVM, 6 LSE, 7 command FF, 8 Standby wake-up (u16) |
| 16 | Uplink-request error count this boot (u16, saturating) |
| 18 | Sensor error count this boot (u16, saturating) |
| 20 | Last measurement validity bits: battery, T/RH, pressure, UV, CO2, PM (u16) |

## Validation

Run from the repository root:

```
python3 stm32_node/tests/run_tests.py
node stm32_node/tests/test_decoder.js
cmake -S stm32_node -B stm32_node/build/Release -DCMAKE_BUILD_TYPE=Release -DCMAKE_TOOLCHAIN_FILE=cmake/gcc-arm-none-eabi.cmake
cmake --build stm32_node/build/Release
```

Host tests compile the actual health module, power policy, NVM store, SPS30/SCD41 drivers, extracted modem alarm setter/supervisor function and extracted RTC epoch reader. They cover five simulated years / 876,000 alarms, 208 interrupted-write scenarios, CRC fallback, migration, invalid battery reads, hysteresis, SPS30 command timing and RTC interrupt ordering. These tests do not emulate an entire STM32 or RF network.

Resets are confined to conditions nothing else can recover from: CPU faults, the HAL error handler, a broken modem event queue, a transmission stuck for 15 minutes, five consecutive non-busy uplink rejections, a lost alarm timer, and the progress deadline. Modem panics, context read/write failures and an unreadable store are counted and reported, not reset: their conditions either resolve on their own or persist in flash, where a reset only loops. The stack's own panic sites are reachable in normal operation - the no-downlink threshold trips after 2400 uplinks, roughly five days at the default duty cycle.

Before field deployment, verify watchdog recovery, STOP2 current, RTC rollover, missing/shorted sensors, no-gateway behavior, voltage ramps with load spikes, actual flash power cuts and decoder compatibility on the board. Run a soak test beyond the former 50-day failure point. Firmware was built and host-tested, not flashed remotely.

## Energy claims

The study's roughly 1.1-mA baseline alone represents 26.4 mAh/day. Finding its physical cause can save more than small arithmetic optimizations. Its 77-mC CO2 entry is for one shot; this firmware intentionally takes two shots per useful reading. Its SPS30 event duration also differs from the current premeasurement schedule. Reintegrate current traces for the same firmware, battery-side voltage, radio conditions and measurement cadence before claiming a percentage saving. A doubled interval means 50% fewer periodic uplinks, not 50% less total power.

Hardware sources: [BQ25185 datasheet](https://www.ti.com/lit/ds/symlink/bq25185.pdf), repository `hardware/datasheets/sps30_datasheet.pdf` (Table 8, Sleep only in Idle), `hardware/datasheets/scd4x_low_power_appnote.pdf` (discard first single shot after power-down). Original study and schematic exports are retained as historical project documents.

Local verification on 2026-09-06: Release 88,144 B ROM, Debug 168,936 B ROM, CO2-disabled Release 87,000 B ROM. All three link successfully within the reserved flash limit. Remaining three compiler warnings are existing middleware variables unused when tracing is disabled.

## Firmware 2.0 (PCB 1.1)

| Area | Behavior in 2.0 |
|---|---|
| LSE | Started by the application, not by `HAL_RCC_OscConfig`: drive MEDIUMHIGH, 2 s for LSERDY, then LSE off, drive HIGH and a second attempt. A running LSE after a system reset is left alone. If the second attempt fails too, reason 6 goes to DR6, the code blinks on LED_DIAG and the MCU restarts after 60 s; a later cold start can succeed. There is no LSI fallback: the RTC times the LoRaWAN receive windows. A start that needed the second attempt is reported as `0x0542`. |
| Radio clock and PA | 32 MHz crystal X1, no TCXO (PB0 is never driven). Only RFO_HP is wired; `paSelect` follows the TX configuration instead of a fixed RFO_LP. The stack asks for EIRP; the PA gets that minus `BOARD_ANTENNA_GAIN_DB` (default 2 dB), so a 2 dBi antenna stays at 16 dBm EIRP. Change the define with the antenna. |
| RF switch | PB12 supplies the BGS12SN6 only while the radio works. The modem's TCXO hooks drive it: before every TX or RX task CTRL low, PB12 high, 1 ms settle; after every radio sleep CTRL low, PB12 low. The modem gets a 2 ms startup delay, so TX and both receive windows start early by that much and RX1/RX2 do not move. Receiving uses CTRL low (RF1), sending CTRL high (RF2); CTRL only changes while the switch is supplied. The radio planner sleeps between TX and RX1; the next task switches the supply on again. |
| ADR and link check | After every join the ADR profile is network controlled. 24 h after the join and then daily a LinkCheckReq leaves as its own MAC uplink after a regular TX done. Three unanswered days in a row: the station leaves the network, stops its timers and joins again with the normal backoff; the rejoin is reported as `0x0430` with the days. Every rejoin uses a DevNonce. Link checks in installation mode do not count as silent days. |
| Supply rails | 5 V is on from boot (after 5 ms for the regulator and 100 ms for the SPS30), also when the boot starts in RECOVERY. 3V3SWITCHABLE stays off. Levels are set before the pin mode changes. |
| Standby | A second stage below RECOVERY for deep discharge, see [CONFIGURATION.md](CONFIGURATION.md#power-modes). It needs the option byte IWDG_STDBY cleared; without it the station stays in RECOVERY and reports `0x0544`. The hourly checks in Standby do not count as boots; the boot that joins again reports `0x0540` with reason 8. |
| Fault reports | Missing parts, read errors, supply states, rejoins, rejected uplinks, NVM errors and every restart reach the backend on fPort 99 instead of only blinking on a board nobody watches. Urgent entries leave with the next uplink, the rest at most hourly; flapping parts are damped for 6 h and radio counters come once a day, so a bad sensor or poor coverage does not eat the airtime. |
| Diagnostics | Trace and the debug profile write over USART1 on H1 (PB6/PB7) only while they print. Probe lines are gone; a radio monitor output on a board pin breaks the build. |

Hardware verification of 2.0 (RF timing, levels, currents, LSE cold start, Standby wake-up) is tracked in the field acceptance test and still open.

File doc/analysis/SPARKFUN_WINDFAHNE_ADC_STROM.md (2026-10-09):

# SparkFun-Windfahne: ADC-Beschaltung und Strom

Stand: 06.10.2026. Forschung/Planung für zweite Station, keine Firmwareänderung. Basis: SparkFun Weather Meter SEN-15901; passende Kitrevision/Steckerbelegung prüfen.

## Anschluss

Die Windfahne ist passiv: acht Reedkontakte und Widerstände erzeugen 16 mögliche Widerstandswerte, teils durch zwei gleichzeitig geschlossene Kontakte. Sie hat keine eigene I2C-Schnittstelle und gibt ohne externe Speisung keine auslesbare Spannung aus.

Benötigt werden **ein ADC-Eingang** und ein externer **10-kΩ-Widerstand, vorzugsweise 1 %**. Für niedrigen mittleren Verbrauch den Widerstand über einen GPIO speisen:

`GPIO-Ausgang → 10 kΩ → Messpunkt → Windfahne → GND`

Der Messpunkt geht zusätzlich zum ADC-Eingang. GPIO HIGH entspricht etwa 3,3 V, GPIO LOW schaltet den Teiler praktisch stromlos. Die zwei Windfahnenleitungen liegen zwischen Messpunkt und GND. Ein dauerhaftes 3,3-V-Netz könnte ebenfalls speisen, würde jedoch den Teilerstrom ständig ziehen.

Der eine freie STM32-Analogeingang reicht dafür. Optional ein externer I2C-ADC wie ADS1115, falls der Pin anderweitig verwendet wird. Die fertigen Regen-/Windgeschwindigkeits-Impulszähler PA4/PA5 zählen Kontakte; sie ersetzen keine Widerstandsauswertung der Windrichtung.

## Spannung und Ströme bei 3,3 V

`V_ADC = 3,3 V × R_Fahne / (10 kΩ + R_Fahne)`

`I_Teiler = 3,3 V / (10 kΩ + R_Fahne)`

| Ausrichtung | Widerstand | Nominelle ADC-Spannung | Strom während Speisung |
|---|---:|---:|---:|
| 0° / N | 33 kΩ | 2,533 V | 76,7 µA |
| 90° / E | 1 kΩ | 0,300 V | 300,0 µA |
| 112,5° / ESE | 688 Ω | 0,212 V | 308,8 µA |
| 180° / S | 3,9 kΩ | 0,926 V | 237,4 µA |
| 270° / W | 120 kΩ | 3,046 V | 25,4 µA |

Die vollständige 16-Richtungen-Widerstandstabelle steht im Datenblatt. Richtungszuordnung anhand kalibrierter Spannungsbereiche, nicht nur exakter Sollwerte; Widerstände, GPIO-Voh, Kontakt- und Leitungseffekte erzeugen Abweichungen. Sensor mechanisch nach Norden ausrichten. ADC-Referenz/Vdda berücksichtigen, möglichst ratiometrisch messen. Die Datenblattbeispielschaltung mit 5 V nicht ungeprüft an 3,3-V-ADC anschließen.

Die GPIO-Speisung ist bei höchstens etwa 0,31 mA eine kleine Last; konkrete GPIO-Voh und ADC-Werte am Board prüfen. Dessen interne Pull-up-Toleranz ist kein Ersatz für einen definierten externen 10-kΩ-Widerstand.

## Stromsparen und Einlesen

1. GPIO auf HIGH setzen.
2. Spannung einschwingen lassen und mehrere ADC-Werte lesen/mitteln.
3. GPIO auf LOW, ADC nach Messsitzung abschalten.

Optionaler RC-Filter zur Störunterdrückung: beispielhaft 1 kΩ Serie zum ADC und 10 nF gegen GND an dessen Eingang. Worst-case Quellwiderstand des Teilers ca. 9,23 kΩ; mit 1 kΩ Serie und 10 nF liegt die RC-Zeitkonstante bei ca. 0,10 ms. Etwa 1–2 ms Wartezeit ist dafür ein plausibler Ausgangspunkt, nicht eine Messzeitgarantie für beliebige Kabel/Filter/ADC-Einstellungen. ADC-Abtastzeit nach Eingangsimpedanz einstellen. Größere Kondensatoren verlängern die Wartezeit.

Für **2 ms aktiv pro Sekunde** ergibt sich rechnerisch:

- Während eingeschaltet: etwa **25–309 µA** aus 3,3 V.
- Während aus: **praktisch kein Teilerstrom**, reale GPIO-/Schaltungsleckströme bleiben.
- Durchschnitt: etwa **0,051–0,618 µA**.

Bei 2 ms alle 60 s: etwa **0,00085–0,0103 µA** mittlerer Teilerstrom. Das Beispiel betrachtet nur den passiven Teiler. **ADC, MCU-Wachzeit, Kommunikation und Schutz-/Zusatzschaltung fehlen darin.** Diese können das Windfahnenbudget übersteigen; nicht als Gesamtstationsstrom ausgeben. Beim externen ADC außerdem Wandlungszeit und Ruhestrom berücksichtigen, statt pauschal die 2-ms-MCU-Messung anzunehmen.

1 Hz ist ein praktikabler Ausgangspunkt für Richtungssampling; Übertragung kann seltener erfolgen. Winkel bei späterer Mittelung zirkulär behandeln, z. B. 359°/1° nicht arithmetisch zu 180° mitteln. Bei sehr schwachem Wind ist die mechanische Ausrichtung weniger aussagekräftig.

## Quellen und Prüfung

- [SparkFun Weather Meter Hookup Guide](https://learn.sparkfun.com/tutorials/weather-meter-hookup-guide/all): passive Messgeber, Kontakte und Spannungsteiler.
- [SEN-15901 Datenblatt](https://cdn.sparkfun.com/assets/d/1/e/0/6/DS-15901-Weather_Meter.pdf): 16 Widerstände, Minimum 688 Ω / Maximum 120 kΩ. Die relevante Seite wurde gerendert und visuell geprüft.
- [SparkFun Weather Meter Kit](https://www.sparkfun.com/weather-meter-kit.html): konkrete Kitrevision.
- Bestehender Projektcode: ADC-Solarpfad PB2 bereits belegt; weitere freie Anschlüsse/Pinbelegung für Windfahne erst im konkreten Aufbau festlegen.

Nominelle Werte durchgerechnet; kein echter Sensor vermessen und kein Pin/Treiber implementiert.

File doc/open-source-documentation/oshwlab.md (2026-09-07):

# HydroNodeStation: Solar-Powered Open-Source Environmental Monitoring Node (STM32WLE5 + LoRaWAN)

> **[IMAGE 1, COVER]** Finished station mounted outdoors, Stevenson screen and
> solar panel visible, daylight. *Set this image as the project cover.*

A solar-powered, six-channel environmental sensor node built around a bare
STM32WLE5 die that carries the MCU and the LoRa radio on one chip. Designed
from scratch in EasyEDA Pro, fabricated at JLCPCB, deployed outdoors, and
streaming live data right now with no login required.

**Live public dashboard: https://hydronode.tech/stations/public/004dd7e7-5c27-4de0-bff5-24116f721658**

| | |
|---|---|
| **Status** | Built, assembled, deployed, field-tested. Live data flowing today |
| **Design tool** | 100 percent EasyEDA Pro, schematic and 4-layer PCB |
| **Fabrication** | JLCPCB, including SMT assembly |
| **Radio** | LoRaWAN Class A, EU868, Helium network, Semtech LoRa Basics Modem |
| **Measurement cycle** | 3 minutes, adjustable over the air from 30 to 3600 seconds |
| **Battery life, measured** | About 24 days on a 1200 mAh LiPo with zero solar input |
| **Board cost** | About 200 EUR for 5 assembled boards including shipping |
| **Sensor cost** | Under 30 USD minimal, 120 to 150 USD fully populated |
| **Licences** | Hardware CERN-OHL-S v2, docs CC BY-SA 4.0, firmware MIT |

> **Demo video:** `<YOUTUBE-LINK-HIER-EINFÜGEN>`
> Full build, deployment and live-data walkthrough.

---

## 1. The problem this solves

Air quality is a public health issue and climate variability is increasing, yet
hyperlocal environmental data is still scarce. Official monitoring stations are
expensive, need mains power, and are installed at only a handful of sites per
city. The gaps between them span kilometres. Whole neighbourhoods have no
measurements of the air they breathe.

The limiting factor has never been the sensors. It is power and connectivity. A
station that needs mains power or Wi-Fi can only go where that infrastructure
already exists, which is not where the data gaps are.

HydroNodeStation removes that constraint. It needs no mains power, no Wi-Fi and
no cellular contract. Put it on a pole, a rooftop, a balcony railing or a fence
in the middle of a field. It runs unattended and reports every three minutes
over a LoRaWAN link that spans kilometres.

The design goal was never a weather station. It was a station anyone can
reproduce, at a cost that scales with their budget, so that dense environmental
monitoring becomes something a community can build for itself.

---

## 2. What makes it different

Each point below was a deliberate engineering decision rather than a default.

### 2.1 Bare STM32WLE5 die, not a pre-made LoRa module

Almost every open-source LoRaWAN node uses a certified radio module: RAK, Seeed
E5, or an RFM95 next to a separate MCU. That is the easy path. It costs you
control of the RF front end, board area, and the module markup.

This design places the bare **STM32WLE5CCU6** on the board and builds the RF
chain itself. A **BALFHB-WL-02D3** integrated balun and a **BGS12SN6** TX/RX
switch on GPIO PC13 give properly matched, separate transmit and receive paths
at 868 MHz. The result is full control of impedance, ground return and antenna
feed, in a node that is smaller and cheaper than any module-based equivalent.

At the time of design, no suitable open-source STM32WLE5 reference design with
this sensor set existed. Closing that gap is the core open-source contribution
of this project.

### 2.2 Staggered pre-wakeup, so the MCU never waits on a sensor

The two interesting sensors are slow. The SCD41 needs about 5 seconds per
single-shot measurement. The SPS30 needs fan spin-up plus settling. A naive
implementation keeps the MCU awake through all of it, and that is where the
energy actually goes.

Instead the firmware schedules each slow sensor backwards from the transmit
window and sleeps through their measurement time.

- The **SCD41** runs two power-cycled single shots. A throwaway stabilisation
  shot starts 12 seconds before the uplink, then the useful shot starts
  6 seconds before it. Only the second is transmitted. The first exists purely
  to settle the photoacoustic cell after power-up. Without it, the first reading
  after a power cycle is measurably wrong.
- The **SPS30** starts 16.5 seconds before the uplink to cover fan spin-up and
  particle settling.

The MCU is in STOP2 for essentially all of that time.

### 2.3 Buck-boost instead of an LDO

Two **TPS63900** buck-boost converters supply the board. The primary rail holds
3.3 V across the entire battery curve from 2.5 V to 4.2 V and is always on. The
secondary rail produces 5 V for the SPS30 and is switched off entirely by a
GPIO when the particulate sensor is not measuring.

Two consequences matter. Sensor accuracy and radio output power stay constant
regardless of battery state, where an LDO-based node degrades slowly as the cell
drains. And the battery is used down to its last usable volt, because no energy
is burned as heat in a linear regulator.

### 2.4 Sensor-agnostic by architecture

All sensors sit on one I2C bus and are commanded into their own power-down
states between measurements. The reference sensor set is a starting point, not
a limit. Any I2C sensor can be added with a firmware adaptation: soil moisture,
VOC, noise, radiation, water level. The platform is an extensible research
instrument rather than a fixed product.

### 2.5 Remote control without a site visit

An unattended node is only maintainable if you can change its behaviour over
the air. The firmware accepts LoRaWAN downlink commands on fPort 2.

| Command | Effect |
|---|---|
| `10 HH LL` | Set the transmit interval in seconds, 30 to 3600, persisted to flash |
| `11` | Trigger an SPS30 fan-cleaning cycle |
| `12` | Request boot, reset and sensor diagnostics on fPort 5 |
| `FF` | Software reset |

Combined with the transactional NVM layer, a station can be re-tuned, diagnosed
and recovered without anyone climbing to it. The SPS30 additionally cleans
itself every 120 hours, but only when the battery is above 4120 mV, so
maintenance can never brown out the node.

---

## 3. What it measures

> **[IMAGE 2]** Assembled PCB, top side, sensors populated, macro shot.

| Quantity | Sensor | I2C address | Accuracy |
|---|---|---|---|
| CO2 concentration | Sensirion **SCD41** | 0x62 | Single-shot photoacoustic NDIR, plus or minus 40 ppm |
| Particulate matter | Sensirion **SPS30** | 0x69 | PM1.0, PM2.5, PM4, PM10 and number concentration |
| Temperature and humidity | Sensirion **SHT45** | 0x44 | plus or minus 0.1 degrees C, plus or minus 1.0 percent RH |
| Barometric pressure | Bosch **BMP390** | 0x77 | plus or minus 0.5 hPa absolute |
| UV index | Lite-On **LTR390** | 0x53 | UVA and ambient light, needs a UV-transmitting window |
| Battery state of charge | Maxim **MAX17048** | 0x36 | I2C fuel gauge, no sense resistor |

All six channels are live and validated in the field. This is measured
hardware, not a bill of materials wish list.

> **The sensor set changed during development, and the reasoning is published.**
> The original BME280 was replaced by SHT45 plus BMP390, which is more accurate
> and lower power at a similar cost. The analog VEML6075 was replaced by the
> LTR390, which has a wider range, a native I2C interface, and does not consume
> an ADC channel. An ambient noise channel was evaluated and dropped to keep the
> power budget honest. Anyone reproducing this board gets the second iteration
> of these decisions rather than the first guess.

---

## 4. Hardware design

> **[IMAGE 3]** EasyEDA Pro 3D render of the 4-layer PCB, top and bottom.

### 4.1 PCB

Four layers, designed from scratch in EasyEDA Pro.

**Stackup.** Top and bottom carry signal and supply traces. Inner 1 is a
dedicated ground layer with a continuous copper pour. Inner 2 is a second signal
layer. The continuous ground layer gives short return paths and keeps
common-mode noise off the I2C and control lines.

**RF section.** Traces are 50 ohm controlled impedance for 868 MHz. A dense
ground via fence surrounds the balun, the RF switch, the decoupling capacitors
and the SMA path. It ties the RF field down to the ground layer and suppresses
coupling into the rest of the board. Keep-out zones follow the manufacturer's
reference layout, which is the single most common omission in DIY LoRa boards.
The antenna is external on an SMA connector.

**Connectors.** A 2-pin JST connector with a parallel screw terminal for the
battery. A 2-pin screw terminal for the solar panel. A 6-pin screw terminal for
the cable running to the Stevenson screen, carrying I2C, supply and the panel
lead. A 4-pin header for the ST-Link V2: NRST, SWDCLK, SWDIO, GND.

**Test pads** are provided on the supply rails, the I2C bus and the charger CE
pin. A board you cannot probe is a board you cannot debug.

The RF layout and antenna matching were by far the most time-intensive part of
the project, and are where most of the reusable open-source value sits. Anyone
forking this board inherits an RF section that has been iterated and measured
rather than copied from a datasheet diagram.

### 4.2 Power path

> **[IMAGE 4]** Enclosure open, PCB installed, wiring and solar cable gland
> visible.

```
Solar panel ──► BQ25185 ──► 1S LiPo ──► TPS63900 #1 ──► 3.3 V, always on
6.91 V         (charge      1200 mAh   (buck-boost)     ├─► STM32WLE5 + RF
570 mW          controller) 2.5-4.2 V                   └─► I2C sensor bus
                                       TPS63900 #2 ──► 5 V, GPIO switched
                                       (buck-boost)    └─► SPS30
```

- **BQ25185** solar charge controller. Harvests from a small panel, handles the
  full LiPo charge profile, and keeps the system running while charging.
- **TPS63900**, two of them. Under 0.5 microamp quiescent, over 95 percent
  efficiency. See section 2.3.
- **MAX17048** fuel gauge. Real state-of-charge telemetry is sent with every
  packet, so an operator can see a node's energy budget remotely instead of
  guessing.

**Solar panel and battery as deployed.** An AnySolar SOLAR CELL G3 THIN, 6.91 V
open circuit, 570.8 mW, Vmpp 5.58 V, Impp 102 mA, feeding a 1200 mAh 1S LiPo.
That combination is fully sufficient through summer. Winter operation is being
tested now. Do not use a smaller panel: same size or larger only. The battery
can be scaled with the panel, but going much smaller is risky, because several
overcast days in a row will drain it.

### 4.3 Measured power budget, and one unsolved problem

These are PPK2 measurements on the actual custom PCB, not datasheet arithmetic.
They are published in full, including the part that does not look good yet.

| Source | Interval | Extra charge per event | Events per day | mC per day |
|---|---|---|---|---|
| Baseline, 1.1 mA over 86400 s | | | | 95,040 |
| LoRa transmit, +0.7 mA for 10 s | 3 min | 7 mC | 480 | 3,360 |
| SCD41 CO2 | 15 min | 77 mC | 96 | 7,392 |
| SPS30, 55 mA for 30 s minus idle | 30 min | 1,617 mC | 48 | 77,616 |
| **Total** | | | | **183,408** |

`183,408 mC / 3600 = 50.9 mAh per day`, which gives about **24 days on a
1200 mAh cell with zero solar input**.

> **The open problem, stated plainly.** The day-average baseline draw is
> 1.1 mA. Adding up the sleep currents of every component on the board gives
> roughly 5.7 microamps, a factor of about 200. The suspects are SCD41 IR source
> leakage, BQ25185 quiescent current, and PCB leakage paths. This is not solved,
> and closing it is the highest-impact open task on the project.
>
> It is published rather than hidden because that is what an open-source
> hardware project is for. Someone reproducing this board deserves to know the
> real number before ordering parts, and someone with STM32WL leakage experience
> can now actually help. The issue is open on GitHub.

Design decisions that are proven and unaffected by the above:

| Decision | Effect |
|---|---|
| LoRaWAN instead of Wi-Fi or cellular | Kilometres of range at a fraction of the energy per byte |
| Single-chip STM32WLE5 | Removes the power and board cost of a discrete transceiver |
| SF7 with adaptive data rate | Minimises on-air time, the largest per-event energy cost |
| Buck-boost across 2.5 to 4.2 V | No LDO dropout losses, battery used to its last usable volt |
| Staggered pre-wakeup, section 2.2 | MCU sleeps through slow-sensor settling |
| 5 V rail switched off by GPIO | The SPS30 draws nothing between measurements |
| 3 minute cycle, adjustable over the air | Time resolution tunable per deployment without reflashing |

Solar harvesting is designed to keep the node online indefinitely. Energy
balance logging through a full seasonal cycle is running now and is not
complete.

---

## 5. Firmware and data pipeline

> **[IMAGE 5]** Live web dashboard and the iOS app side by side.

Measurement cycle, 3 minutes, adjustable over the air:

```
STOP2 sleep ──► pre-wake SPS30 (T-16.5 s) ──► SCD41 stabilisation shot (T-12 s)
     ▲                                                    │
     │                                       SCD41 useful shot (T-6 s)
     │                                                    ▼
     └── radio off, sensors asleep ◄── LoRaWAN TX ◄── read all, pack payload
```

- **Deterministic rather than event-driven.** Predictable energy per cycle,
  predictable battery life, predictable data density.
- **Compact binary payload codec.** Every byte on air costs energy, so the
  payload is bit-packed rather than JSON. The matching decoder is published for
  the network-server side.
- **CO2 every fifth uplink, particulate matter every tenth.** The expensive
  sensors do not run every cycle.
- **LoRaWAN Class A** on the Helium network, EU868, built on the Semtech LoRa
  Basics Modem, with duty-cycle compliance handled in firmware.
- **Robust recovery paths.** Incomplete SCD41 measurement sequences are rejected
  rather than transmitted as bad data. Watchdog and progress recovery, battery
  recovery, and two CRC-protected flash snapshots keep the node from bricking
  itself in the field.
- **Battery policy with hysteresis.** Below 3500 mV the interval doubles. Below
  3300 mV the node cancels radio and sensor work and checks the voltage every
  60 seconds until it recovers.

**A real bug, found by a host-side test.** The uplink alarm overflowed
reproducibly after 49.71 days, which is 2^32 milliseconds. Firmware 1.6 fixes
it, and the regression test that caught it ships in the repository. Any node
built from this design before that fix would have silently stopped transmitting
after seven weeks.

**Backend.** The network server posts every uplink straight to the HydroNode
backend over an HTTPS webhook, with no message broker in between. That keeps
the whole pipeline reproducible by anyone running their own server.

```
Network server ──HTTPS webhook──► HydroNode API ──► Kafka pipeline ──► PostgreSQL
Helium, ChirpStack v4 or TTN                        validation             │
                                                                           ▼
                                                   public dashboard + iOS app
```

Automated anomaly detection runs on the incoming stream and flags implausible
readings. Users can register their own stations, name them, and browse
historical charts per channel. Because the decoder is published and the
integration is a plain webhook, you can point a station at your own backend
instead. Nothing here is locked to my infrastructure.

---

## 6. Enclosure

> **[IMAGE 6]** 3D-printed Stevenson screen, close-up of the stacked louvers.
>
> **[IMAGE 7]** CAD render of the Stevenson screen and the PCB housing.

A sealed printed housing for the electronics, plus a 3D-printed Stevenson screen
for the sensor head, designed in Fusion 360 and printed in white UV-resistant
ASA.

This is not decoration. Stacked louvers block direct sun and driving rain while
air circulates freely. Without it the housing heats up in sunlight and the
temperature and humidity readings are simply wrong. ASA was chosen over PLA and
PETG for outdoor UV stability, because a PLA enclosure becomes brittle within a
season. Several print runs were needed to get the fit right.

Mounting is on a standard pole or balcony railing. A waterproof cable gland
handles the solar lead.

Both models are attached to this project as `.3mf` and print on any consumer
FDM printer.

> **Open detail, the UV window.** The LTR390 has to see UV through the
> enclosure, but ordinary glass and PETG block most of the UV band and produce a
> reading that is wrong rather than missing. The deployed station uses roughly
> 2 mm of polystyrene with an empirical correction factor of 17/13, applied in
> the firmware as integer arithmetic. That was a cost decision. It works, but
> polystyrene is not UV-stable and will degrade outdoors. UV-transmitting
> acrylic (PMMA UVT) is the better choice for a station meant to last. Quartz or
> borosilicate is better still and costs around 50 EUR for a small disc. If you
> reproduce this, budget for the window material. It is the one part where the
> cheap option quietly gives you wrong data.

---

## 7. Engineering log, including what went wrong

Open-source hardware is only useful if the failures are published too.
Otherwise everyone repeats them.

Two faults were found on the first fabricated board. Both are fixed in the
published design.

**1. TPS63900 regulator section.** A wiring bug in the buck-boost section. The
root cause was identified and corrected together with an experienced power
electronics engineer, and the corrected design drops into the same board
outline. In the meantime the deployed station runs on a deliberate workaround:
the same TPS63900 on a breakout board plugged into the PCB headers. Efficiency
is identical and the measurements are unaffected, which is why live data has
been flowing throughout.

**2. BQ25185 charger CE pin.** The charger has an internal 6 hour safety
timeout. If CE is not driven by an MCU GPIO, the firmware cannot reset that
timeout and charging stops silently after six hours. On a solar node that is
fatal, and it would have taken weeks of confusing field data to diagnose. The
corrected design routes CE to a GPIO that the firmware pulses. On boards already
fabricated, the pin has to be hand-soldered to the GPIO.

**3. The 1.1 mA baseline, still open.** See section 4.3. Not solved, published
anyway.

A further honest note for anyone deploying outdoors: in the published schematic
the BQ25185 TS/MR pin uses a fixed 10 kilohm resistor, so the charger does not
measure battery temperature. Winter operation needs an appropriate battery NTC
and a verified undervoltage path. The firmware cannot protect an unprotected
cell below MCU operating voltage.

---

## 8. Reproduce it yourself

Everything needed is attached to this project. No desktop EDA installation is
required, because EasyEDA runs in the browser.

1. **Fork this project** in EasyEDA Pro using the button at the top of this
   page.
2. **Order the PCB** directly from the editor through JLCPCB. Four layers,
   standard process, no exotic requirements. About 200 EUR for 5 assembled
   boards including shipping, 2 to 3 weeks lead time.
3. **Enable SMT assembly.** The STM32WLE5, the balun and the RF switch are
   fine-pitch parts, and hand-soldering them is where most reproduction attempts
   fail.
4. **Order the parts.** The bill of materials on this page carries LCSC part
   numbers and can be ordered directly. Populate only the sensors you need.
5. **Source the rest.** Solar panel, 1S LiPo, 868 MHz SMA antenna, 6-core cable,
   waterproof cable gland, UV window material, ST-Link V2, USB to UART adapter.
6. **Print the enclosure.** Both `.3mf` files are attached. White ASA, not PLA.
7. **Build and flash the firmware.** The Device EUI is derived automatically
   from the STM32 unique ID and printed over the debug UART on boot. You only
   register that EUI with your network server and set your own Join EUI and App
   Key.
8. **Join a LoRaWAN network** (Helium, ChirpStack or TTN) and point its HTTP
   webhook at your backend, or at the open HydroNode backend.

The full step-by-step guide, including toolchain setup, flashing and the
HydroNode binding, is in the GitHub repository README.

### Cost, scaled to what you need

| Build | Sensors populated | Sensor cost |
|---|---|---|
| **Minimal** | Temperature, humidity, pressure with an SHT30 substitute | under 30 USD |
| **Air quality** | Plus LTR390 UV and SCD41 CO2 | around 70 USD |
| **Full research node** | All six channels including SPS30 particulate | 120 to 150 USD |

Sensors only. The board itself, the RF section, the power stage and the
fabrication come on top, roughly 200 EUR for 5 assembled boards.

Unpopulated sensor positions cost nothing and break nothing. One design serves a
single hobbyist node and a research-grade air quality array.

---

## 9. Environmental sustainability

Sustainability here is a design constraint rather than a marketing line. It is
the reason the architecture looks the way it does.

- **Zero grid energy in operation.** Solar harvested, battery buffered. Net grid
  consumption over the device lifetime is none.
- **Energy budget as a first-class constraint.** Every architectural choice,
  from the single-chip radio to the buck-boost converters, the staggered
  pre-wakeup and the switched 5 V rail, exists to keep the harvesting panel
  small. Less silicon, less material, less embodied carbon than a node that
  compensates for a lazy power budget with a bigger panel. The remaining 1.1 mA
  baseline in section 4.3 is the last piece of that argument still to be earned,
  and it is stated openly rather than rounded away.
- **LoRaWAN over cellular.** No SIM, no load on carrier infrastructure, orders
  of magnitude less energy per transmitted byte.
- **Long service life by material choice.** UV-resistant ASA instead of PLA, so
  the enclosure survives years outdoors instead of one season. The printed parts
  are not consumables.
- **Repairable and modular.** Headers for the sensor modules, test points on
  every rail, no glue, no potting, no proprietary connectors. A failed sensor is
  a 10 USD replacement, not a landfilled board.
- **Partial population means no waste.** You buy and mount only the sensors your
  use case needs.
- **The purpose is environmental.** Beyond its own footprint, the node exists to
  generate the air quality and climate data that local environmental decisions
  currently lack.

---

## 10. Open source

All design files are published, and everything below is genuinely reusable.

| Component | Licence |
|---|---|
| Hardware: schematic, PCB, CAD enclosure | [CERN-OHL-S v2](https://cern-ohl.web.cern.ch/), strongly reciprocal |
| Documentation and media | [CC BY-SA 4.0](https://creativecommons.org/licenses/by-sa/4.0/) |
| Firmware, own code | [MIT](https://opensource.org/license/mit) |

Vendored third-party components keep their upstream terms: STMicroelectronics
HAL and utilities under BSD-3-Clause, Arm CMSIS under Apache-2.0, and the
Semtech LoRa Basics Modem under BSD-3-Clause.

**Why these licences.** CERN-OHL-S is the OSHWA- and OSI-aligned standard for
open hardware. Anyone may build, sell and modify the board, but improvements to
the hardware have to be shared back under the same terms, so the community keeps
the derivatives. MIT on the firmware imposes no friction on reuse in unrelated
projects.

**Attached to this project:**

- Full EasyEDA Pro schematic and 4-layer PCB, forkable in one click, with
  Gerbers and pick-and-place generated straight from the editor
- Bill of materials with LCSC part numbers, orderable directly
- `.3mf` Stevenson screen for the sensor head
- `.3mf` housing for the PCB
- This documentation

**In the GitHub repository:**

- Full firmware source with a CMake build for both board targets
- Payload decoder for the network-server side
- Host-side regression tests that run without any hardware
- A complete build guide, plus configuration and reliability references

**Repository: https://github.com/TexhFexLabs/HydroNodeStation**

---

## 11. Roadmap

Honest status of what is not finished.

- **The 1.1 mA baseline**, section 4.3. The highest-impact open task. Suspects
  identified, root cause not yet proven. Help is genuinely welcome.
- **Revision 2 boards** with the corrected TPS63900 section and the routed
  BQ25185 CE pin, going into fabrication.
- **Solar autonomy verification.** Energy balance logging through a full
  seasonal cycle is running now. No autonomy claim will be published before
  matched PPK2 measurements support it.
- **UV window material.** Cheaper UV-transmitting alternatives to polystyrene
  are under test, see section 6.
- **CO2 calibration.** A guided forced-recalibration procedure and dynamic
  BMP390 pressure compensation for the SCD41. Automatic self-calibration is not
  supported in power-down single-shot mode, so this has to be explicit.
- **Machine learning evaluation** for anomaly detection and calibration on the
  accumulated dataset.
- **Multi-node deployment.** The actual point of the project is a dense local
  mesh, not a single station.

---

## 12. Thanks

This project would not exist in physical form without EasyEDA, JLCPCB and
OSHWLab. The complete 4-layer board including the RF section was designed in
EasyEDA Pro, ordered from JLCPCB straight out of the editor, and shared here on
OSHWLab so that anyone can fork it and build their own.

Going from schematic to a working, deployed, data-streaming station in a
browser, without a single desktop EDA licence, is what makes open hardware
accessible to students and hobbyists.

---

**Build it. Deploy it. Fork it.**
Live data is flowing at https://hydronode.tech

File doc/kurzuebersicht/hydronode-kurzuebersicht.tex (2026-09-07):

\documentclass[11pt,a4paper]{scrartcl}

\usepackage[T1]{fontenc}
\usepackage[utf8]{inputenc}
\usepackage[ngerman]{babel}
\usepackage{lmodern}
\usepackage{microtype}
\usepackage[a4paper,margin=2.4cm]{geometry}
\usepackage{setspace}
\usepackage[hidelinks]{hyperref}
\usepackage{xurl}
\usepackage{booktabs}
\usepackage{tabularx}
\usepackage{array}
\usepackage[table]{xcolor}
\usepackage{enumitem}

\definecolor{accent}{HTML}{0B4F6C}
\definecolor{rowgray}{HTML}{F5F5F5}

\setstretch{1.05}
\setkomafont{disposition}{\color{accent}\bfseries}
\emergencystretch=3em
\setlist{nosep,leftmargin=1.3em}

\newcolumntype{L}{>{\raggedright\arraybackslash}X}

\pagestyle{plain}

\begin{document}

\begin{center}
  {\LARGE\bfseries\color{accent} Umweltmessstation HydroNodeStation01\par}
  \vspace{0.4em}
  {\large Kurzübersicht\par}
  \vspace{0.6em}
  {\normalsize Felix Knoll \quad$\cdot$\quad OTH Regensburg \quad$\cdot$\quad \today\par}
\end{center}
\vspace{1em}

\section*{Kurzfassung}

Die HydroNodeStation01 ist eine solarbetriebene Umweltmessstation für den autonomen Außeneinsatz. Sie misst Temperatur, Luftfeuchte, Luftdruck, UV\hspace{0pt}-Index, CO$_2$ und Feinstaub und überträgt die Werte per LoRaWAN an ein öffentliches Dashboard. Sie benötigt weder einen Stromanschluss noch einen Netzwerkanschluss und läuft seit Ende Mai 2026 im Freien.

Die Station entstand als Projektarbeit im Studiengang Technische Informatik. Platine, Gehäuse, Firmware und Backend wurden vollständig neu entwickelt, weil für den verwendeten Funkchip kein geeignetes offenes Design verfügbar war.

\begin{table}[h]
  \centering
  \rowcolors{2}{rowgray}{white}
  \begin{tabularx}{\textwidth}{lL}
    \toprule
    \textbf{Punkt} & \textbf{Angabe} \\
    \midrule
    Messintervall     & 3 Minuten. CO$_2$ alle 15 Minuten, Feinstaub alle 30 Minuten \\
    Energieversorgung & Solarpanel mit Pufferakku \\
    Übertragung       & LoRaWAN über das Helium\hspace{0pt}-Netz \\
    Reichweite        & Im Feldtest über 10 Kilometer nachgewiesen \\
    Materialkosten    & rund 250 Euro je Station \\
    Entwicklungsaufwand & 170 Stunden \\
    Lizenz            & Hardware CC BY\hspace{0pt}-NC\hspace{0pt}-SA 4.0, Firmware BSD\hspace{0pt}-3\hspace{0pt}-Clause \\
    Stand             & Im Feldtest seit Ende Mai 2026 \\
    \bottomrule
  \end{tabularx}
\end{table}

\section*{Messgrößen}

\begin{table}[h]
  \centering
  \rowcolors{2}{rowgray}{white}
  \begin{tabularx}{\textwidth}{lLl}
    \toprule
    \textbf{Sensor} & \textbf{Messgröße} & \textbf{Genauigkeit} \\
    \midrule
    SHT45    & Temperatur, Luftfeuchte                          & $\pm0{,}1\,^\circ$C, $\pm1{,}0\,\%$ \\
    BMP390   & Luftdruck                                        & $\pm0{,}5$\,hPa \\
    LTR390   & UV\hspace{0pt}-Index                             & \\
    SCD41    & CO$_2$                                           & $\pm40$\,ppm \\
    SPS30    & Feinstaub PM1.0, PM2.5, PM4.0, PM10              & \\
    MAX17048 & Akkuspannung der Station                         & \\
    \bottomrule
  \end{tabularx}
\end{table}

Die Sensoren sitzen in einem selbst konstruierten Lamellengehäuse nach dem Prinzip der Wetterhütte, gedruckt aus weißem ASA. Das Material ist UV\hspace{0pt}-beständig und witterungsfest. Das Gehäuse hält Direktsonne und Regen von den Sensoren fern und lässt gleichzeitig Luft zirkulieren.

\section*{Betrieb}

Gemessen wurde ein mittlerer Stromverbrauch von rund 2,12 Milliampere, entsprechend etwa 50,9 Milliamperestunden pro Tag. Mit einem Akku von 1200 Milliamperestunden ergibt das eine Reserve von rund 24 Tagen ohne Sonneneinstrahlung.

Fällt die Akkuspannung unter 3300 Millivolt, schaltet die Station Funk und Sensoren ab und prüft nur noch minütlich die Versorgung. Sie nimmt den Messbetrieb selbsttätig wieder auf, sobald die Spannung 3600 Millivolt erreicht und diese Schwelle eine Minute lang hält. Zwischen 3500 und 3650 Millivolt sendet sie im doppelten Intervall. Eine Station, die zeitweise schweigt, ist deshalb nicht zwingend defekt.

Die Firmware überwacht sich selbst und startet im Störungsfall neu. Sie meldet sich anschließend ohne Eingriff von außen wieder am Funknetz an.

Zum Aufstellen wird ein Platz im Freien mit ausreichender Sonneneinstrahlung für das Solarpanel benötigt. Weitere Infrastruktur ist nicht erforderlich.

\section*{Kosten und Aufwand}

\begin{table}[h]
  \centering
  \rowcolors{2}{rowgray}{white}
  \begin{tabularx}{\textwidth}{Lr}
    \toprule
    \textbf{Position} & \textbf{Betrag} \\
    \midrule
    Elektronik mit allen sechs Sensoren                  & 150 bis 200 Euro \\
    ASA\hspace{0pt}-Filament für das Gehäuse            & rund 30 Euro \\
    3D\hspace{0pt}-Druck, Solarpanel, Akku und Kleinteile & übrige Kosten \\
    \midrule
    \textbf{Gesamt je Station}                          & \textbf{rund 250 Euro} \\
    \bottomrule
  \end{tabularx}
\end{table}

Angegeben sind Materialkosten ohne Arbeitszeit. Die Platinen mussten im Fünferpack bestellt werden, weil der Fertiger keine kleineren Mengen anbietet. Fünf Stück kosteten inklusive Versand rund 200 Euro. Beschränkt man die Bestückung auf Temperatur, Feuchte, Druck und UV und verzichtet auf CO$_2$ und Feinstaub, sinken die Kosten der Elektronik auf unter 30 Euro.

Der Entwicklungsaufwand lag bei 170 Stunden gegenüber 160 geplanten. Der größte Mehraufwand entfiel auf den Platinenentwurf mit rund 50 statt der geplanten 9 Stunden sowie auf das Gehäuse mit rund 12 Stunden, das ursprünglich nicht eingeplant war.

\section*{Daten und Veröffentlichung}

Die Messwerte laufen über das Funknetz in HydroNode, eine selbst entwickelte Plattform aus Backend, Weboberfläche und iOS\hspace{0pt}-App. Eine automatische Anomalieerkennung prüft die Messreihen und meldet auffällige Sprünge oder Ausfälle. Die Plattform ist über diese eine Station hinaus einsetzbar.

Die Live\hspace{0pt}-Werte der Station sind öffentlich und ohne Benutzerkonto einsehbar:

\begin{center}
\url{https://hydronode.tech/stations/public/004dd7e7-5c27-4de0-bff5-24116f721658}
\end{center}

Geplant ist, mehrere Stationen dieser Bauart an verschiedenen Standorten aufzustellen, damit möglichst viele Menschen Messwerte aus ihrer unmittelbaren Umgebung einsehen können.

Das Projekt ist quelloffen veröffentlicht. Schaltplan, Platinenentwurf, Gehäusedaten, Stückliste, Firmware und Inbetriebnahmeanleitung liegen unter \url{https://github.com/TexhFexLabs/hydroNodeStation01}. Hardware und Gehäuse stehen unter CC BY\hspace{0pt}-NC\hspace{0pt}-SA 4.0, die Firmware unter BSD\hspace{0pt}-3\hspace{0pt}-Clause.

\section*{Stand und offene Punkte}

Alle sechs Sensoren, der LoRaWAN\hspace{0pt}-Betrieb und die Übertragung ins Backend sind verifiziert. Die Station steht seit Ende Mai 2026 im Außentest.

Zwei Punkte sind noch offen. Die Solarautarkie unter verschiedenen Lichtbedingungen ist nicht abschließend verifiziert, und die Langzeitmessung der tatsächlichen Batterielaufzeit läuft noch.

Die ausführliche technische Dokumentation liegt als Projektdokumentation zur HydroNodeStation01 bei.

\end{document}

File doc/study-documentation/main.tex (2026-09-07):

\documentclass[11pt,a4paper]{scrartcl}

\usepackage[T1]{fontenc}
\usepackage[utf8]{inputenc}
\usepackage[ngerman]{babel}
\usepackage{lmodern}
\usepackage{microtype}
\usepackage[a4paper,margin=2.5cm]{geometry}
\usepackage{graphicx}
\usepackage{float}
\usepackage{tikz}
\usetikzlibrary{arrows.meta,backgrounds,calc,fit,positioning,shapes.geometric}
\usepackage{setspace}
\usepackage{amsmath}
\usepackage[hidelinks]{hyperref}
\usepackage{xurl}
\usepackage{booktabs}
\usepackage{tabularx}
\usepackage{array}
\usepackage[table]{xcolor}
\usepackage{longtable}
\usepackage{multirow}
\usepackage{etoolbox}

\definecolor{colgreen}{HTML}{2E7D32}
\definecolor{colorange}{HTML}{E65100}
\definecolor{colblue}{HTML}{0B4F6C}
\definecolor{colred}{HTML}{C62828}
\definecolor{rowgray}{HTML}{F5F5F5}

\newcommand{\status}[1]{%
  \ifstrequal{#1}{Fertig}{\textcolor{colgreen}{\textbf{Fertig}}}{}%
  \ifstrequal{#1}{In Arbeit}{\textcolor{colorange}{\textbf{In Arbeit}}}{}%
  \ifstrequal{#1}{Geplant}{\textcolor{colblue}{\textbf{Geplant}}}{}%
  \ifstrequal{#1}{Weggelassen}{\textcolor{colred}{\textbf{Weggelassen}}}{}%
}

\definecolor{accent}{HTML}{0B4F6C}
\setstretch{1.1}
\setkomafont{disposition}{\color{accent}\bfseries}
\emergencystretch=3em
\RedeclareSectionCommand[tocnumwidth=2.5em]{section}

\begin{document}
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

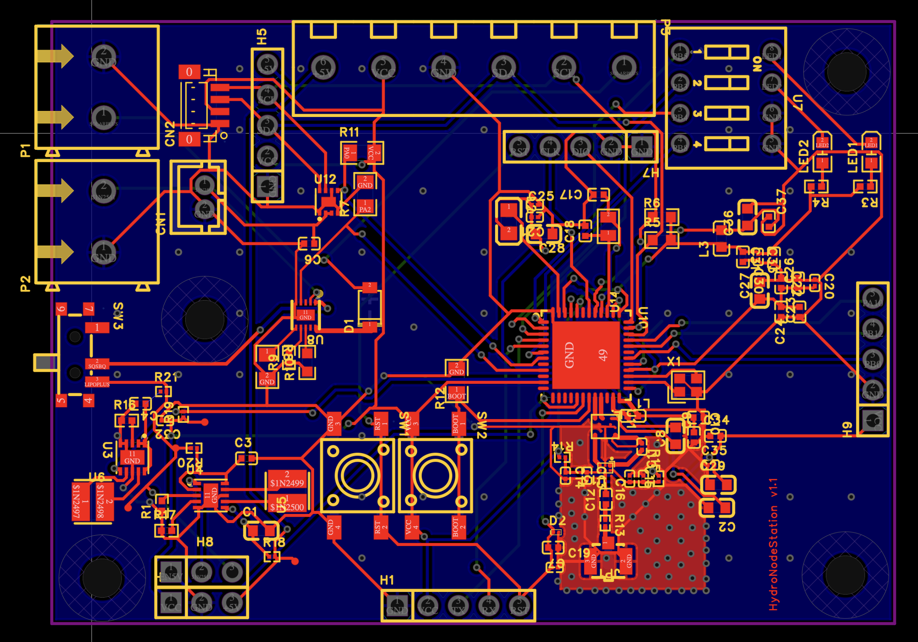
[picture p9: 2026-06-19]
hardware/schematics_pcb/PCB_EASYEDA.png

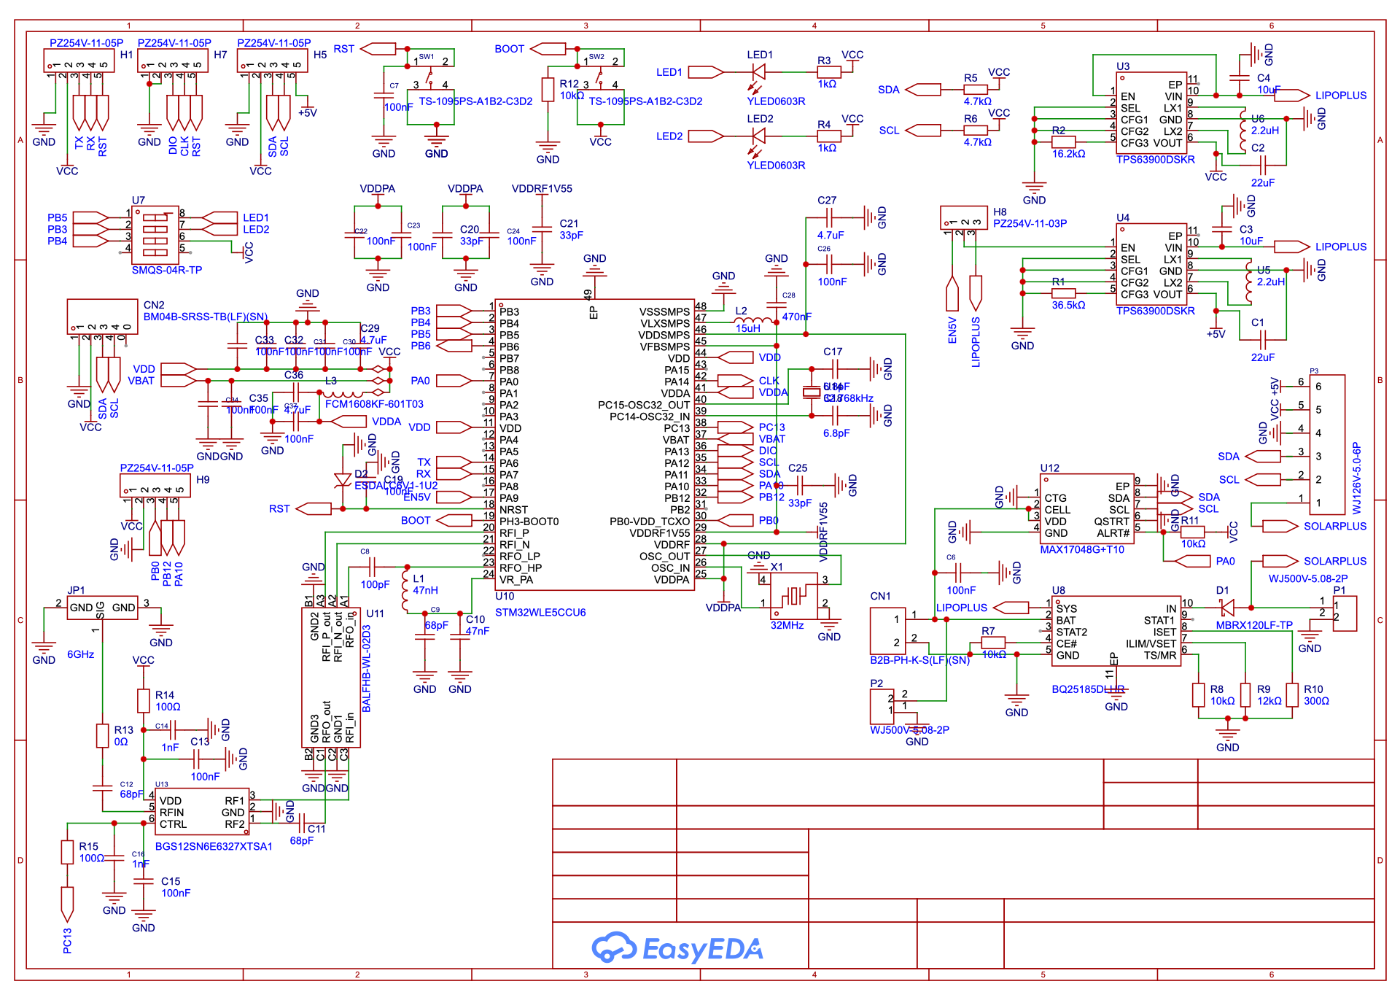
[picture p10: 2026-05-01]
hardware/ordered_pcb/schematic_preview.png

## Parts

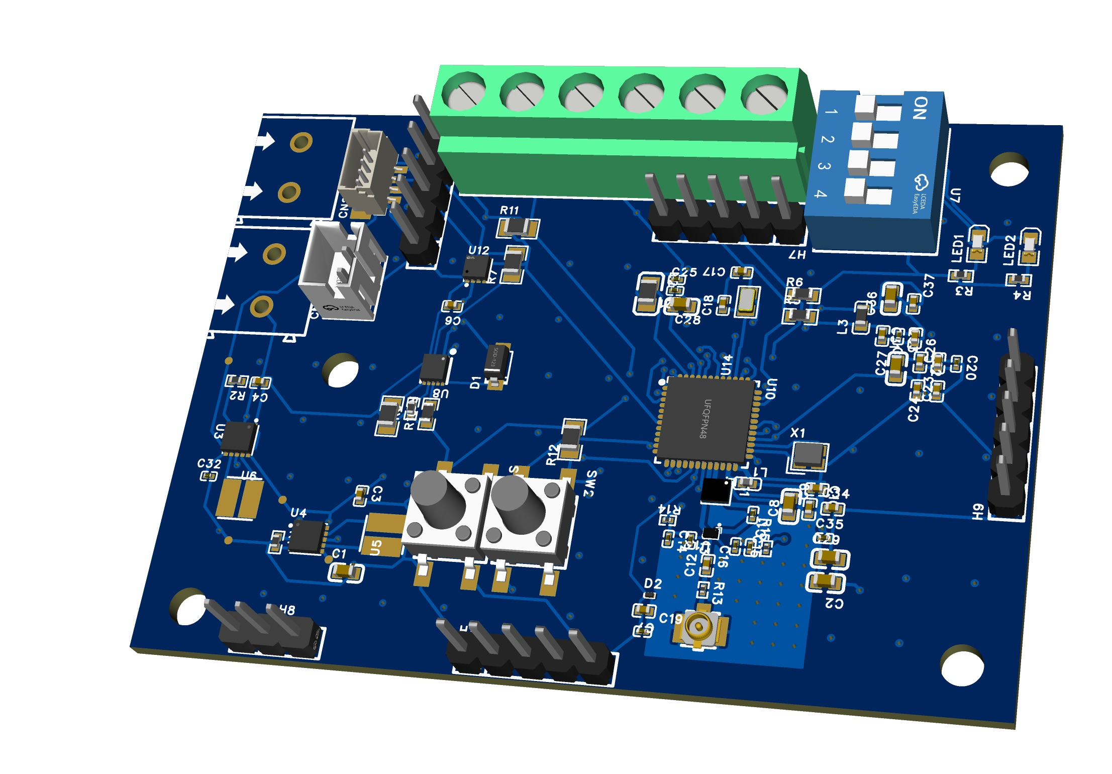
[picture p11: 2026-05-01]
hardware/ordered_pcb/pcb_3d_render.png

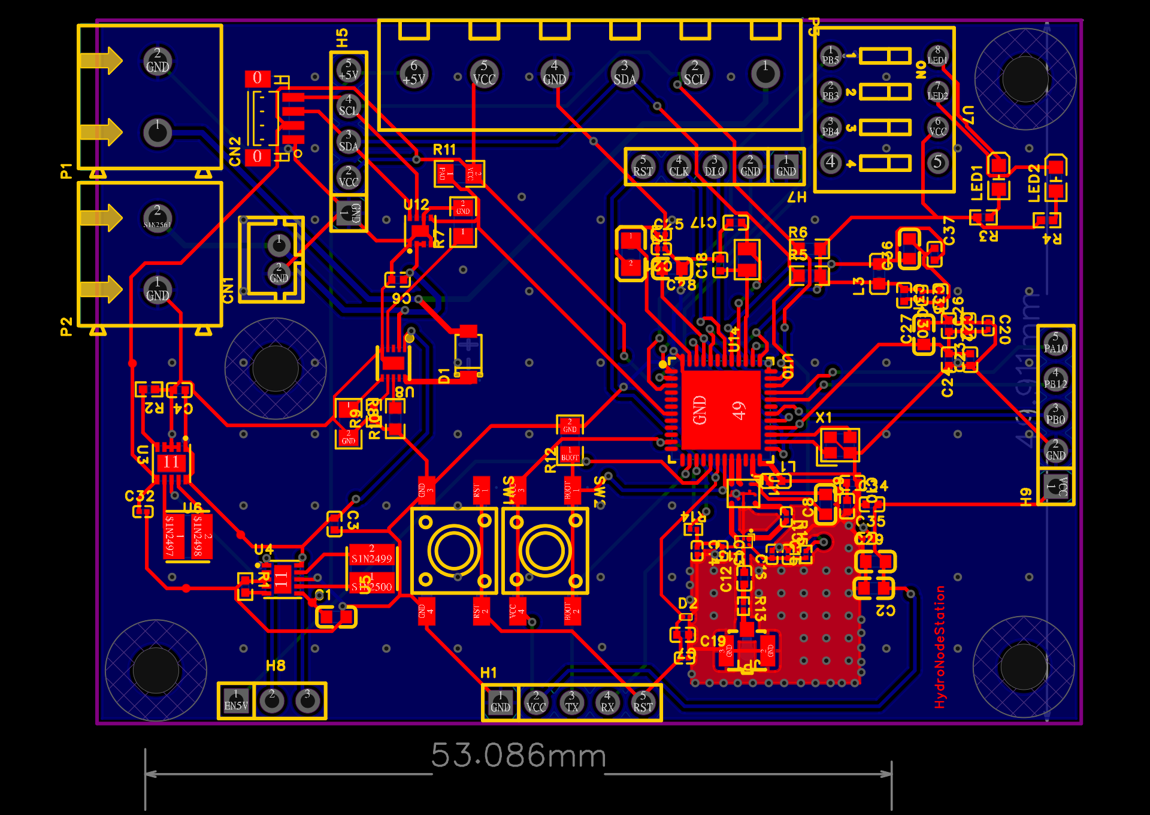
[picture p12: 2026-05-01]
hardware/ordered_pcb/pcb_routing.png

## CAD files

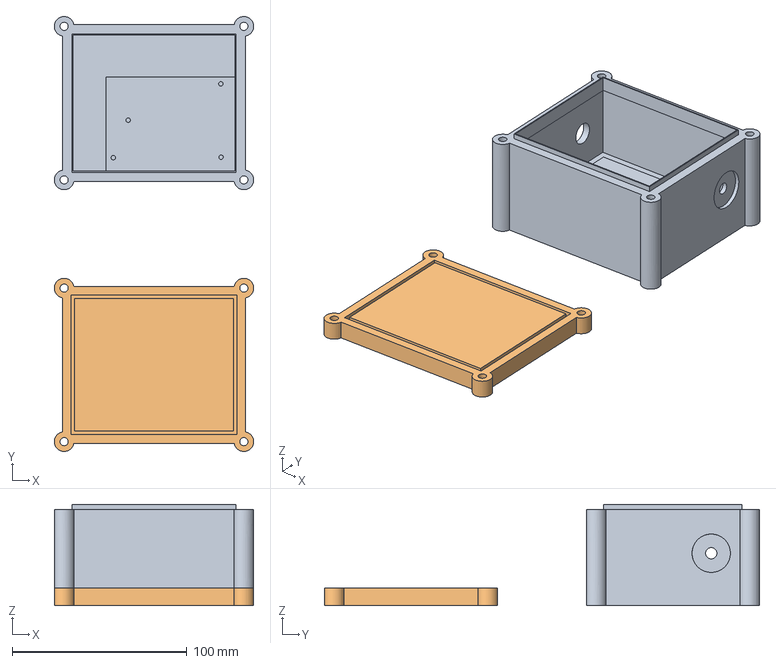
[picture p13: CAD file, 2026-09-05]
hardware/CAD/hydroNodeStation_outdoor_box.3mf
114.3 x 249.3 x 58.0 mm
Körper6
TOP

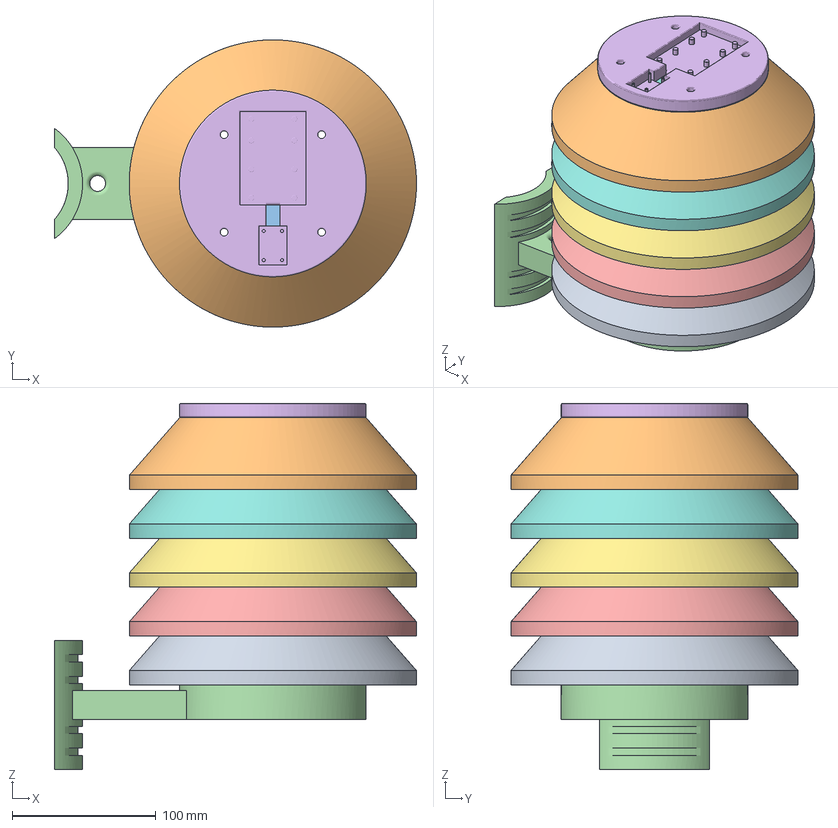
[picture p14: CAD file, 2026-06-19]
hardware/CAD/hydroNodeStation_outdoor_screen.3mf
252.0 x 200.0 x 255.0 mm
Körper1
Körper10
Körper11
Körper12
Körper5
Körper6
Körper8
Körper9

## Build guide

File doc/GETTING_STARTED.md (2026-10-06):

# Firmware reference

The full path from ordering parts to live readings is in the
[build guide in the README](../README.md#build-a-station). This file is the
firmware-side reference: toolchain detail, flashing options, key handling and
debugging.

For timing, payload format and downlink commands see
[CONFIGURATION.md](CONFIGURATION.md). For fault recovery, flash migration and
the hardware tests still outstanding see [RELIABILITY.md](RELIABILITY.md).

---

## 1. Prerequisites

| Tool | Version | Purpose |
|---|---|---|
| `arm-none-eabi-gcc` | 12 or newer | ARM GCC toolchain |
| `cmake` | 3.22 or newer | Build system |
| `ninja` or `make` | any | CMake generator backend |
| ST-Link V2 or J-Link | hardware | Flashing over SWD |
| `openocd` or STM32CubeProgrammer | any | Flash utility |
| USB to UART adapter, 3.3 V | hardware | Reading the debug console on H1 (USART1, PB6 TX / PB7 RX) |

```bash
# macOS
brew install arm-none-eabi-gcc cmake ninja

# Ubuntu / Debian
sudo apt install gcc-arm-none-eabi cmake ninja-build
```

---

## 2. Build

```bash
git clone https://github.com/TexhFexLabs/HydroNodeStation.git
cd HydroNodeStation/stm32_node
```

**PCB 1.1, STM32WLE5CCU6 (firmware 2.0; revision 1 boards use a 1.6.x release):**

```bash
cmake -B build/Release \
  -DCMAKE_BUILD_TYPE=Release \
  -DCMAKE_TOOLCHAIN_FILE=cmake/gcc-arm-none-eabi.cmake
cmake --build build/Release
```

**Same board with trace output over USART1:**

```bash
cmake -B build/Debug \
  -DCMAKE_BUILD_TYPE=Debug \
  -DCMAKE_TOOLCHAIN_FILE=cmake/gcc-arm-none-eabi.cmake
cmake --build build/Debug
```

Output lands in the respective build directory as
`LoRaWAN_End_Node_LBM.elf`, `.bin` and `.hex`.

Both targets compile for STM32WLE5 and share all application logic. Only the
pin mapping and the MCU variant differ. GitHub Actions builds both on every
push, so a change that breaks one target is caught before it is merged.

Configure once. Afterwards `cmake --build build/Release` is enough, and
re-running the configure step with the toolchain flag is not necessary.

---

## 3. LoRaWAN keys

Create `stm32_node/LoRaWAN/App/se-identity-local.h`. The file is listed in
`.gitignore`, and `se-identity.h` includes it automatically when it exists.

```c
// Device EUI, leave at zero to derive it from the STM32 hardware UID
#define LORAWAN_DEVICE_EUI    00,00,00,00,00,00,00,00

// Join EUI, also called App EUI, big-endian, from your network server
#define LORAWAN_JOIN_EUI      AA,BB,CC,DD,EE,FF,00,11

// Application key, 16 bytes, big-endian, from your network server
#define LORAWAN_APP_KEY       AA,BB,CC,DD,EE,FF,00,11,22,33,44,55,66,77,88,99
#define LORAWAN_GEN_APP_KEY   AA,BB,CC,DD,EE,FF,00,11,22,33,44,55,66,77,88,99
```

Byte lists are comma-separated hexadecimal tokens without `0x`, matching the
format in the tracked default header.

`LORAWAN_GEN_APP_KEY` takes the same value as `LORAWAN_APP_KEY` under
LoRaWAN 1.0.x.

> **Never put real keys in the tracked `se-identity.h`, and never commit them.**
> Do not use `skip-worktree` or `.git/info/exclude` to hide production keys in a
> tracked file. The local header exists for exactly this purpose. See
> [SECURITY.md](../SECURITY.md).

A zero `LORAWAN_DEVICE_EUI` selects the silicon-derived ID, which is the
recommended setting for the custom PCB. A non-zero value is respected.

---

## 4. Flash

SWD pinout on the custom PCB header: `NRST`, `SWDCLK` on PA14, `SWDIO` on PA13,
`GND`. Supply the board from its own battery or externally at 3.3 V.

**OpenOCD with an ST-Link:**

```bash
openocd -f interface/stlink.cfg \
        -f target/stm32wlx.cfg \
        -c "program build/Release/LoRaWAN_End_Node_LBM.elf verify reset exit"
```

**STM32CubeProgrammer:** open the `.elf` or `.hex`, select ST-Link, click
Download.

> **Do not mass erase during an upgrade.** A normal firmware update has to
> preserve the last 8 KiB of flash, which holds the LoRaWAN context and the
> persisted configuration. See [RELIABILITY.md](RELIABILITY.md).

---

## 5. Read the Device EUI

Flash the Debug build once and connect the USB to UART adapter to header **H1**
(PB6 = TX) at 115200 baud. The firmware prints the derived Device EUI on boot.
Clear the option byte IWDG_STDBY once per board
(`STM32_Programmer_CLI -c port=SWD -ob IWDG_STDBY=0`), see
[CONFIGURATION.md](CONFIGURATION.md#power-modes).

Register that EUI as an OTAA device on your network server using LoRaWAN 1.0.4
and the regional parameters for your region. Helium IoT, ChirpStack v4 and
The Things Network are all supported. The server returns the Join EUI and the
App Key for section 3.

The RF region is selected by `ACTIVE_REGION` in `LoRaWAN/App/lora_app.h`. The
compiled region set is in `LoRaWAN/Target/lorawan_conf.h`.

---

## 6. Connect to HydroNode

1. Open [hydronode.tech](https://hydronode.tech) or the HydroNode app and
   register. The first sensor slot is included at no cost.
2. Select the sensor, then open **Settings, LoRaWAN Binding**.
3. Enter the Device EUI and save.
4. HydroNode displays a webhook URL. Enter that URL on your network server under
   **Integrations, HTTP / Webhook**.

The backend decodes the payload by fPort and acknowledges uplinks
automatically. No decoder configuration is needed on your side.

To run your own backend instead, use [payload-decoder.js](payload-decoder.js).
Before deploying firmware 2.0 against an existing backend, make sure its
decoder knows the 32/34-byte ports 2/3, treats the missing-value sentinels as
absent readings rather than as real measurements, and ignores or reads fPort 99. The sentinels are documented in
[CONFIGURATION.md](CONFIGURATION.md).

### Additional sensor slots

Further sensors are available for a small cost contribution covering hardware
and running infrastructure. For academic or research use, write to
[contact@hydronode.tech](mailto:contact@hydronode.tech). Complimentary slots are
available for student and university projects.

---

## 7. Verify the first uplink

The first uplink goes out on fPort 2 and should reach the dashboard within one
to two minutes if there is gateway coverage.

If nothing arrives, check in this order:

1. Is the Device EUI on the network server identical to the one printed on H1?
2. Did the join succeed? Enable logging (below) and watch the console.
3. Is there gateway coverage at the deployment site? Move the node closer to a
   known gateway to rule this out.
4. Is the webhook URL entered on the network server?

The join backoff is deliberate. Unsuccessful attempts run in windows of at most
five minutes, followed by pauses of 5, 10, 20, 40 and 60 minutes. The node does
not reboot merely because no gateway is in range.

---

## 8. Debugging

**Serial logging in normal operation.** Set `APP_LOG_ENABLED 1` in
`Core/Inc/sys_conf.h` (the Debug preset does this) and rebuild. The console
appears on H1 (PB6) at 115200 baud.
Debug logs print the DevEUI and never the keys.

**Debug profile mode.** Close DIP 3 before power-on (also in the Release
build). The node skips LoRaWAN entirely and reads all sensors, including the
solar measurement and fuel gauge, in a loop and prints the values on H1.
DIP 4 instead starts the installation mode, see
[CONFIGURATION.md](CONFIGURATION.md#dip-switches). This is the fastest
way to bring up sensors or check calibration without waiting for transmit
windows.

**Production defaults** are `APP_LOG_ENABLED=0` and `DEBUGGER_ENABLED=0`, with
`LOW_POWER_DISABLE=0` so STOP2 is active. Leaving logging on in the field costs
energy.

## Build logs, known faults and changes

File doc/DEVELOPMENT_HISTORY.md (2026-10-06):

# Development History

This project was developed in a private GitHub repository from January to
September 2026 and republished here as an open-source project. The original
repository's issue and pull-request threads did not carry over, so this file
preserves the development record.

The commit history itself is complete and unmodified apart from the removal of
development LoRaWAN key material and personal data (see [SECURITY.md](../SECURITY.md)).

## Issues (25)

| # | Title | Labels | Opened | Closed |
|---|---|---|---|---|
| 1 | update project structure | documentation | 2026-03-31 | 2026-04-05 |
| 2 | update README.md | documentation | 2026-03-31 | 2026-08-05 |
| 3 | add RX actions | none | 2026-03-31 | 2026-04-27 |
| 4 | Test LoRaWAN environmental strength at OTH | none | 2026-03-31 | open |
| 5 | Monitor problems/power consumption with poor to no reception | none | 2026-03-31 | 2026-08-05 |
| 6 | Implement deep sleep mode with reduced transmission frequency when battery level is low | none | 2026-03-31 | 2026-05-27 |
| 7 | implement scd41 | none | 2026-03-31 | 2026-04-16 |
| 8 | implement sps30 | none | 2026-03-31 | 2026-04-16 |
| 9 | implement MAX17048 | none | 2026-03-31 | 2026-04-14 |
| 10 | implement bme390 | none | 2026-04-01 | 2026-04-14 |
| 11 | implement sht45 bmp390 ltr390 and max17048 | none | 2026-04-01 | 2026-04-14 |
| 12 | implement LTR390 | none | 2026-04-01 | 2026-04-14 |
| 13 | implement debug interface | enhancement | 2026-04-01 | 2026-06-13 |
| 14 | design pcb | none | 2026-04-01 | 2026-04-24 |
| 16 | add gh actions | enhancement | 2026-04-05 | 2026-04-05 |
| 21 | update ioc to match | bug | 2026-04-05 | 2026-04-05 |
| 24 | update to clion and new stack | enhancement | 2026-04-09 | 2026-04-13 |
| 28 | fix ltr390 error | bug | 2026-04-14 | 2026-04-27 |
| 30 | implement helium status request | enhancement | 2026-04-15 | open |
| 36 | document project | documentation | 2026-04-21 | 2026-04-21 |
| 38 | Fan cleaning not working at init | bug | 2026-04-21 | 2026-04-23 |
| 43 | Refactor the SendTxData function to make it suitable for the HydroNode network | enhancement | 2026-04-27 | 2026-04-27 |
| 45 | test pcb | none | 2026-05-08 | 2026-05-30 |
| 46 | implement on chip uv index calc | none | 2026-05-27 | 2026-06-13 |
| 50 | project cleanup | documentation | 2026-06-13 | 2026-06-19 |

## Pull requests (31)

| # | Title | Branch | Opened | Merged |
|---|---|---|---|---|
| 15 | Withoutstmide | `withoutstmide` | 2026-04-05 | 2026-04-05 |
| 17 | add action | `16-add-gh-actions` | 2026-04-05 | 2026-04-05 |
| 18 | update makefile for actions | `16-add-gh-actions` | 2026-04-05 | 2026-04-05 |
| 19 | test | `16-add-gh-actions` | 2026-04-05 | 2026-04-05 |
| 20 | 16 add gh actions | `16-add-gh-actions` | 2026-04-05 | 2026-04-05 |
| 22 | Update Makefile and README for toolchain configuration on macOS and L… | `21-update-ioc-to-match` | 2026-04-05 | 2026-04-05 |
| 23 | add pdfs and export v1 of schematic | `21-update-ioc-to-match` | 2026-04-05 | 2026-04-09 |
| 25 | 24 update to clion and new stack | `24-update-to-clion-and-new-stack` | 2026-04-12 | 2026-04-13 |
| 26 | 11 implement sht45 | `11-implement-sht45` | 2026-04-14 | 2026-04-14 |
| 27 | Implement SCD41 power-cycled single-shot integration in `stm32_node` and uplink CO2 via CayenneLPP | `copilot/implement-scd41-sensor` | 2026-04-14 | 2026-04-14 |
| 29 | implement scd41 with new prewake logic | `7-implement-scd41-sensor` | 2026-04-15 | 2026-04-16 |
| 31 | implement sps30 and fix cayennelpp co2 sending | `8-implement-sps30` | 2026-04-16 | 2026-04-16 |
| 32 | 8 implement sps30 | `8-implement-sps30` | 2026-04-16 | 2026-04-18 |
| 33 | 2 update readmemd | `2-update-readmemd` | 2026-04-18 | none |
| 34 | 2 update readmemd | `2-update-readmemd` | 2026-04-18 | 2026-04-18 |
| 35 | finalize schem and pcb | `2-update-readmemd` | 2026-04-20 | 2026-04-20 |
| 37 | Add professional LaTeX documentation scaffold under `doc/study-documentation` | `copilot/add-documentation-structure` | 2026-04-21 | 2026-04-21 |
| 39 | 30 implement helium status request | `30-implement-helium-status-request` | 2026-04-21 | 2026-04-21 |
| 40 | update logic for sensor values; update sp30 cleaning; add rx helium cmds | `38-fan-cleaning-not-working-at-init` | 2026-04-22 | 2026-04-23 |
| 41 | 14 design pcb | `14-design-pcb` | 2026-04-24 | 2026-04-24 |
| 42 | Bug Fix: Remove conditional GPIO configuration and interrupt handling for STM3… | `14-design-pcb` | 2026-04-24 | 2026-04-24 |
| 44 | 43 refactor the sendtxdata function to make it suitable for the hydronode network | `43-refactor-the-sendtxdata-function-to-make-it-suitable-for-the-hydronode-network` | 2026-04-27 | 2026-04-27 |
| 47 | 45 test pcb | `45-test-pcb` | 2026-05-30 | 2026-05-30 |
| 48 | 45 test pcb | `45-test-pcb` | 2026-06-08 | 2026-06-08 |
| 49 | Implement various enhancements and fixes for the STM32WLE5 firmware | `45-test-pcb` | 2026-06-13 | 2026-06-13 |
| 51 | 50 project cleanup | `50-project-cleanup` | 2026-06-16 | 2026-06-19 |
| 52 | submited pdf | `50-project-cleanup` | 2026-06-19 | 2026-06-19 |
| 53 | Enhance SCD41 sensor handling and application configuration | `50-project-cleanup` | 2026-06-21 | 2026-06-21 |
| 54 | Refactor README and documentation; update LoRaWAN integration details… | `50-project-cleanup` | 2026-06-22 | 2026-06-22 |
| 55 | docs: finalize study presentation and enclosure CAD | `50-project-cleanup` | 2026-09-05 | 2026-09-05 |
| 56 | Fix 49-day uplink outage and harden unattended operation | `feature/long-term-reliability` | 2026-09-06 | 2026-09-06 |

## After the republication

Firmware 2.0 for hardware revision 2 (PCB 1.1) was developed in the public
repository on the branch `pcb-1.1-firmware-2.0`; its commit messages carry the
planning references (`Refs TD_2_0_n`). Revision 1 boards stay on firmware 1.6.x.

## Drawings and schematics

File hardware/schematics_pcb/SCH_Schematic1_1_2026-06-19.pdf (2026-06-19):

## 10uFGND GND

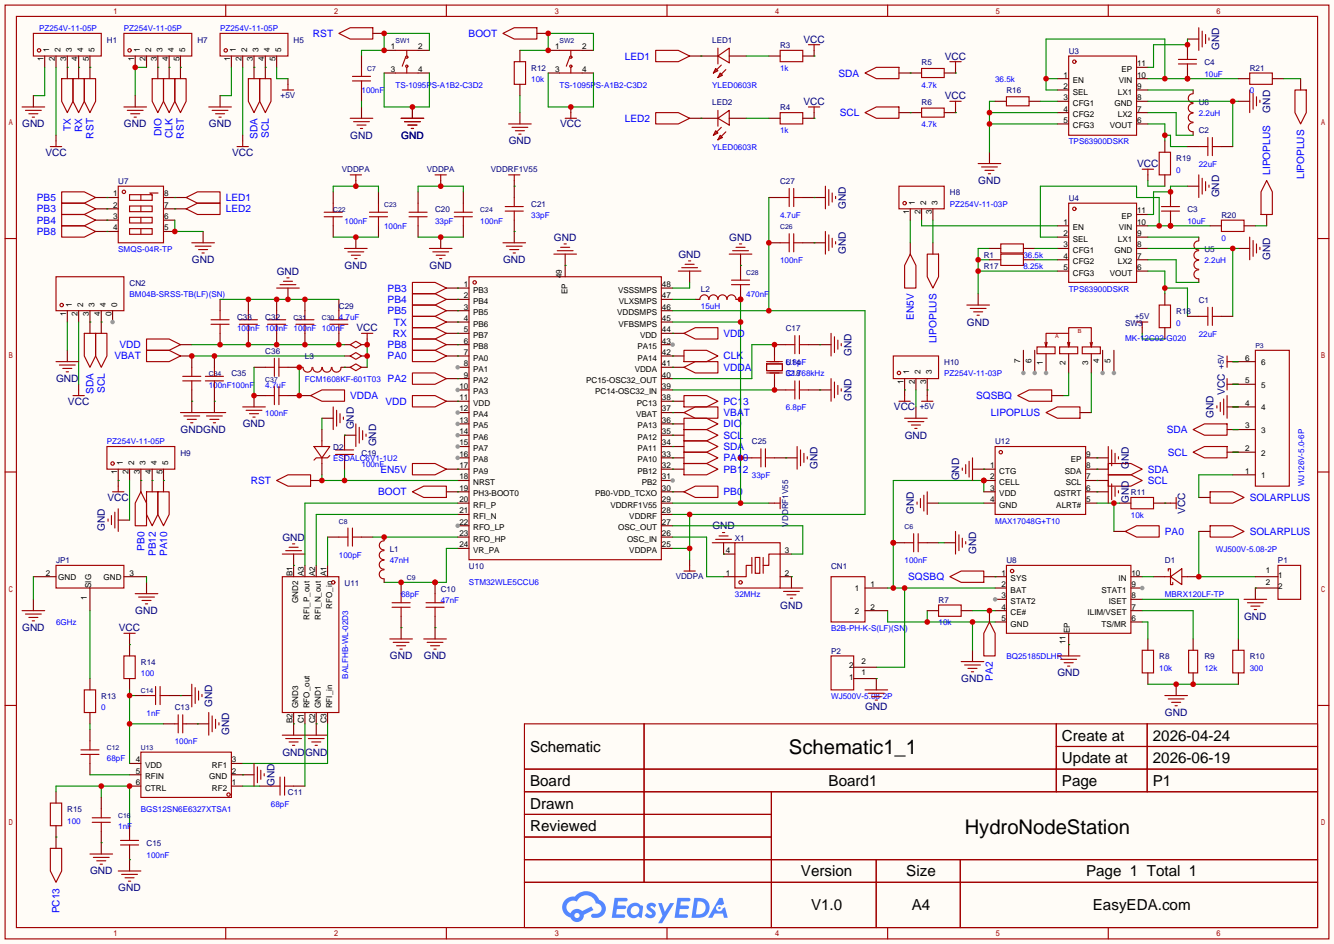
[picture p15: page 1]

BM04B-SRSS-TB(LF)(SN)

Schematic | Schematic1_1 | Create at | 2026-04-24

Update at | 2026-06-19

Board | Board1 | Page | P1
Drawn | | HydroNodeStation
Reviewed

Version | Size | Page 1 Total 1
V1.0 | A4 | EasyEDA.com

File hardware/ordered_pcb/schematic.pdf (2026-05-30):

# 10uFGND GND

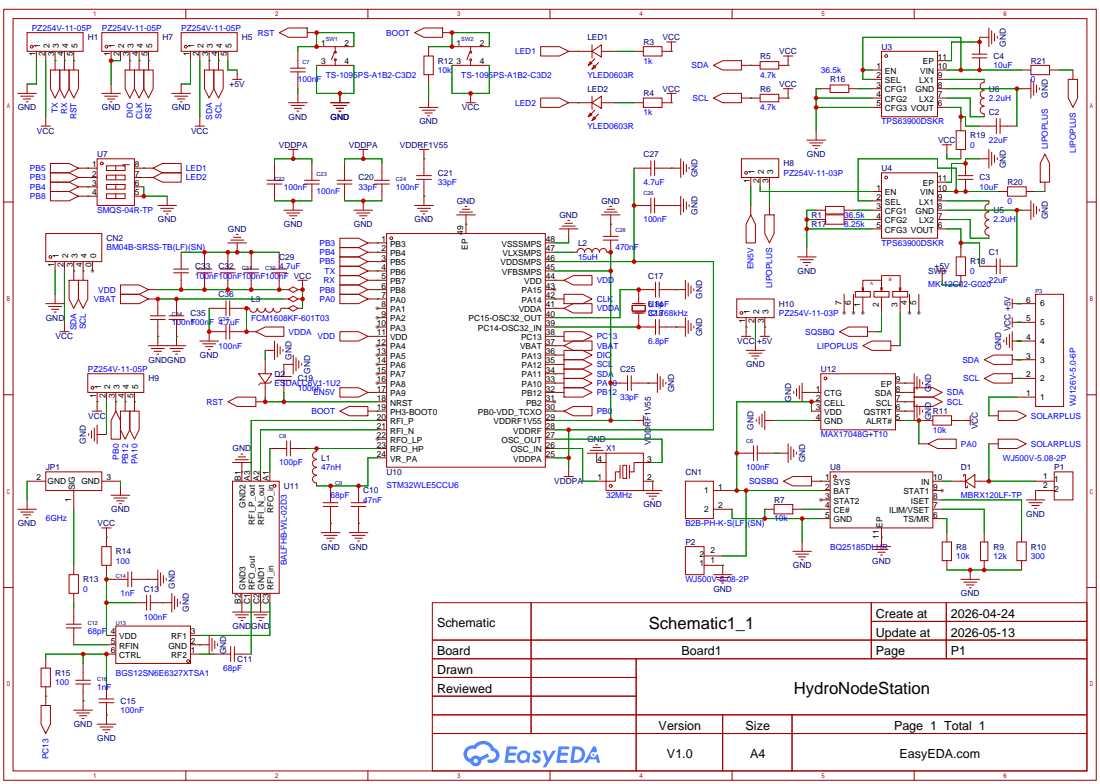
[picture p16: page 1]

BM04B-SRSS-TB(LF)(SN)

Schematic | Schematic1_1 | Create at | 2026-04-24

Update at | 2026-05-13

Board | Board1 | Page | P1
Drawn | | HydroNodeStation
Reviewed

Version | Size | Page 1 Total 1
V1.0 | A4 | EasyEDA.com

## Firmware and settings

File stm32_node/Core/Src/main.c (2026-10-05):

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
/* Includes ------------------------------------------------------------------*/
#include "main.h"
#include "i2c.h"
#include "app_lorawan.h"
#include "usart.h"
#include "gpio.h"

/* USER CODE BEGIN Includes */
#include "debug_profile.h"
#include "runtime_health.h"
#include "power_rail.h"
#include "pulse_counter.h"
#include "standby.h"
#include "lora_app.h"
#include <stdbool.h>
/* USER CODE END Includes */

/* USER CODE BEGIN PD */
/* Per attempt. The LSE crystal U14 sits 12 mm from PC14/PC15 with vias on
 * Inner2 (PCB 1.1 finding P2), so its start is given a second chance. */
#define LSE_START_TIMEOUT_MS 2000U
/* Without the LSE the RTC cannot time the RX windows: show the code, then
 * retry from a reset; a later cold start may succeed. */
#define LSE_FAULT_HOLD_S     60U
/* USER CODE END PD */


/* USER CODE BEGIN PV */
static uint8_t lse_attempts;
/* USER CODE END PV */

void SystemClock_Config(void);
/* USER CODE BEGIN PFP */
static void LSE_Start(void);
/* USER CODE END PFP */

/**
  * @brief  The application entry point.
  * @retval int
  */
int main(void)
{

  /* MCU Configuration--------------------------------------------------------*/

  /* Reset of all peripherals, Initializes the Flash interface and the Systick. */
  Runtime_EarlyInit();
  HAL_Init();

  /* Configure the system clock */
  SystemClock_Config();

  /* USER CODE BEGIN SysInit */
  /* After a Standby wake-up: back to Standby while the battery is low,
   * before any rail or sensor draws current. */
  Standby_CheckWake();
  /* +5 V for the SPS30 before any sensor init, also when booting into
   * RECOVERY or the debug profile; 3V3SWITCHABLE stays off. */
  PowerRail_Init();

  /* USER CODE END SysInit */

  /* Initialize all configured peripherals */
  MX_GPIO_Init();
  MX_I2C2_Init();
  MX_LoRaWAN_Init();
  /* USART1 (H1) is started by the trace driver or the DIP 3 profile only. */
  /* USER CODE BEGIN 2 */
  PulseCounter_Init();
  /* DIP 3 (debug profile) wins over DIP 4 (installation mode). The debug
   * profile reads all sensors forever on USART1 and never starts LoRaWAN;
   * LoRaWAN_Init() already ran, so the sensors are ready. */
  {
    uint8_t dip = DIP_Read();
    if (dip & DIP_DEBUG)
    {
      DebugProfile_Run(); /* never returns */
    }
    if (dip & DIP_INSTALL)
    {
      LoRaWAN_EnableInstallMode();
    }
  }
  /* USER CODE END 2 */

  /* Infinite loop */
  /* USER CODE BEGIN WHILE */
  while (1)
  {
    /* USER CODE END WHILE */
    MX_LoRaWAN_Process();
    Runtime_Process();

    /* USER CODE BEGIN 3 */

  }
  /* USER CODE END 3 */
}

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
/* USER CODE BEGIN 4 */
static bool LSE_Try(uint32_t drive)
{
  RCC_OscInitTypeDef osc = {0};

  /* The LSE lives in the backup domain and survives a system reset; keep it
   * running then (its drive cannot be raised while it is on anyway). */
  if (!LL_RCC_LSE_IsReady())
  {
    LL_RCC_LSE_Disable();
    LL_RCC_LSE_SetDriveCapability(drive);
    LL_RCC_LSE_Enable();
    uint32_t start = HAL_GetTick();
    while (!LL_RCC_LSE_IsReady())
    {
      if ((HAL_GetTick() - start) > LSE_START_TIMEOUT_MS)
      {
        LL_RCC_LSE_Disable();
        return false;
      }
    }
  }
  /* Ready now: the HAL only adds LSESYSEN and returns at once. */
  osc.OscillatorType = RCC_OSCILLATORTYPE_LSE;
  osc.LSEState = RCC_LSE_ON;
  return HAL_RCC_OscConfig(&osc) == HAL_OK;
}

/* MEDIUMHIGH drive is sufficient by calculation (F18); HIGH is the fallback.
 * No LSI fallback: the LSI is too inaccurate for the RX windows. */
static void LSE_Start(void)
{
  lse_attempts = 1U;
  if (LSE_Try(RCC_LSEDRIVE_MEDIUMHIGH)) return;
  lse_attempts = 2U;
  if (LSE_Try(RCC_LSEDRIVE_HIGH)) return;
  Runtime_EarlyFault(RUNTIME_FAULT_LSE, LSE_FAULT_HOLD_S);
}

uint8_t SystemClock_LseAttempts(void)
{
  return lse_attempts;
}
/* USER CODE END 4 */
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


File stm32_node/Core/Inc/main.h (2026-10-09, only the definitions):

#define RTC_N_PREDIV_S 10
#define RTC_PREDIV_S ((1<<RTC_N_PREDIV_S)-1)
#define RTC_PREDIV_A ((1<<(15-RTC_N_PREDIV_S))-1)
#define RTC_PREDIV_A ((1<<(15-RTC_N_PREDIV_S))-1)
#define RTC_N_PREDIV_S 10
#define RTC_PREDIV_S ((1<<RTC_N_PREDIV_S)-1)
#define BOARD_HW_REV 2U
#define LED1_Pin            GPIO_PIN_5      /* PB5, via DIP 1 */
#define LED1_GPIO_Port      GPIOB
#define LED_DIAG_Pin        GPIO_PIN_3      /* PB3, via DIP 2 */
#define LED_DIAG_GPIO_Port  GPIOB
#define DIP3_DEBUG_Pin          GPIO_PIN_4  /* PB4 */
#define DIP3_DEBUG_GPIO_Port    GPIOB
#define DIP4_INSTALL_Pin        GPIO_PIN_8  /* PB8 */
#define DIP4_INSTALL_GPIO_Port  GPIOB
#define MAX17048_ALRT_Pin       GPIO_PIN_0  /* PA0 */
#define MAX17048_ALRT_GPIO_Port GPIOA
#define CHG_CE_Pin          GPIO_PIN_2      /* PA2 */
#define CHG_CE_GPIO_Port    GPIOA
#define CNT1_Pin            GPIO_PIN_4      /* PA4, EXTI4 */
#define CNT1_GPIO_Port      GPIOA
#define CNT2_Pin            GPIO_PIN_5      /* PA5, LPTIM2_ETR / EXTI5 */
#define CNT2_GPIO_Port      GPIOA
#define EN3V3SW_Pin         GPIO_PIN_8      /* PA8, U1 3V3SWITCHABLE */
#define EN3V3SW_GPIO_Port   GPIOA
#define EN5V_Pin            GPIO_PIN_9      /* PA9, U4 +5 V */
#define EN5V_GPIO_Port      GPIOA
#define SOLAR_ADC_Pin       GPIO_PIN_2      /* PB2 */
#define SOLAR_ADC_GPIO_Port GPIOB
#define DBG_UART_TX_Pin     GPIO_PIN_6      /* PB6 */
#define DBG_UART_RX_Pin     GPIO_PIN_7      /* PB7 */
#define DBG_UART_GPIO_Port  GPIOB
#define RF_SW_VDD_Pin       GPIO_PIN_12     /* PB12 */
#define RF_SW_VDD_GPIO_Port GPIOB
#define RF_SW_CTRL_Pin      GPIO_PIN_13     /* PC13, driven by the radio BSP */
#define RF_SW_CTRL_GPIO_Port GPIOC

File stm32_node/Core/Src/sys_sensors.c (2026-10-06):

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

/* Includes ------------------------------------------------------------------*/
#include "stdint.h"
#include "platform.h"
#include "sys_conf.h"
#include "sys_sensors.h"

/* USER CODE BEGIN Includes */
#include "sht45.h"
#include "bmp390.h"
#include "ltr390.h"
#include "max17048.h"
#include "scd41.h"
#include "sps30.h"
#include "i2c.h"
#include "sys_app.h"
#include "adc_if.h"
#include "ina226.h"
#include "fault_report.h"
/* USER CODE END Includes */

/* External variables ---------------------------------------------------------*/

/* USER CODE BEGIN PD */
/* 7-bit addresses for the "not found" detail on fPort 99. */
#define ADDR_SHT45     0x44U
#define ADDR_BMP390    0x77U
#define ADDR_LTR390    0x53U
#define ADDR_SCD41     0x62U
#define ADDR_MAX17048  0x36U
/* USER CODE END PD */


/* USER CODE BEGIN PFP */
static void note_result(uint8_t comp, bool ok);
/* USER CODE END PFP */

/* Exported functions --------------------------------------------------------*/
int32_t EnvSensors_Read(sensor_t *sensor_data, uint8_t sensor_flags)
{
  /* USER CODE BEGIN EnvSensors_Read */
  if (sensor_data == NULL)
  {
    return -1;
  }

  sensor_data->valid = 0U;
  /* Invalid sentinels are distinct from legitimate zero readings. */
  sensor_data->humidity         = SENSOR_INVALID_U16;
  sensor_data->temperature      = SENSOR_INVALID_T;
  sensor_data->pressure         = SENSOR_INVALID_U16;
  sensor_data->battery_voltage  = SENSOR_INVALID_U16;
  sensor_data->uvi_x100         = SENSOR_INVALID_U16;
  sensor_data->co2_ppm          = SENSOR_INVALID_U16;
  sensor_data->pm1_0            = SENSOR_INVALID_U16;
  sensor_data->pm2_5            = SENSOR_INVALID_U16;
  sensor_data->pm4_0            = SENSOR_INVALID_U16;
  sensor_data->pm10_0           = SENSOR_INVALID_U16;
  sensor_data->nc_0_5           = SENSOR_INVALID_U16;
  sensor_data->nc_1_0           = SENSOR_INVALID_U16;
  sensor_data->nc_2_5           = SENSOR_INVALID_U16;
  sensor_data->nc_4_0           = SENSOR_INVALID_U16;
  sensor_data->nc_10_0          = SENSOR_INVALID_U16;
  sensor_data->typ_size         = SENSOR_INVALID_U16;

  /* 1. Read MAX17048 */
  MAX17048_Data_t max17048;
  uint32_t gauge_error = 0U;
  if (MAX17048_Read(&max17048) == MAX17048_OK)
  {
    sensor_data->battery_voltage = max17048.voltage_mv;
    sensor_data->valid |= SENSOR_VALID_BATTERY;
  }
  else
  {
    /* Try to recover I2C and re-init fuel gauge when first read fails at boot. */
    gauge_error = HAL_I2C_GetError(&hi2c2);
    I2C2_RecoverBus();
    if ((MAX17048_Init() == MAX17048_OK) && (MAX17048_Read(&max17048) == MAX17048_OK))
    {
      sensor_data->battery_voltage = max17048.voltage_mv;
      sensor_data->valid |= SENSOR_VALID_BATTERY;
    }
  }
  Fault_ComponentResult(FAULT_COMP_MAX17048, (sensor_data->valid & SENSOR_VALID_BATTERY) != 0U,
                        (sensor_data->valid & SENSOR_VALID_BATTERY) != 0U ? 0U : gauge_error);

  if (sensor_flags & SENSOR_FLAG_ONLY_BATTERY)
  {
    return 0;
  }

  /* 2. Read SHT45 */
  SHT45_Data_t sht45;
  if (SHT45_Read(&sht45) == SHT45_OK)
  {
    sensor_data->valid |= SENSOR_VALID_RHT;
    sensor_data->temperature = sht45.temperature;   /* 0.01 degC */
    sensor_data->humidity    = sht45.humidity;      /* 0.01 %RH  */
    note_result(FAULT_COMP_SHT45, true);
  }
  else
  {
    note_result(FAULT_COMP_SHT45, false);
    I2C2_RecoverBus();
  }

  /* 3. Read BMP390 */
  BMP390_Data_t bmp390;
  if (BMP390_Read(&bmp390) == BMP390_OK)
  {
    sensor_data->valid |= SENSOR_VALID_PRESSURE;
    sensor_data->pressure = bmp390.pressure_hPa;  /* 0.1 hPa */
    note_result(FAULT_COMP_BMP390, true);
  }
  else
  {
    note_result(FAULT_COMP_BMP390, false);
    I2C2_RecoverBus();
  }

  /* 4. Read LTR390 */
  LTR390_Data_t ltr390;
  if (LTR390_ReadUV(&ltr390) == LTR390_OK)
  {
    sensor_data->valid |= SENSOR_VALID_UV;
    sensor_data->uvi_x100 = ltr390.uvi_x100;
    note_result(FAULT_COMP_LTR390, true);
  }
  else
  {
    note_result(FAULT_COMP_LTR390, false);
  }

  /* 5. Read SCD41 */
  if (SCD41_ENABLED && (sensor_flags & SENSOR_FLAG_CO2))
  {
    uint16_t scd41_co2_ppm = 0U;
    if (SCD41_ReadCo2SingleShot(&scd41_co2_ppm, NULL, NULL) == SCD41_STATUS_OK)
    {
      sensor_data->valid |= SENSOR_VALID_CO2;
      sensor_data->co2_ppm = scd41_co2_ppm;
    }
    note_result(FAULT_COMP_SCD41, (sensor_data->valid & SENSOR_VALID_CO2) != 0U);
  }

  /* 6. Read SPS30 */
  if (sensor_flags & SENSOR_FLAG_SPS30)
  {
    SPS30_Data_t sps30_data;
    if (SPS30_ReadMeasurement(&sps30_data) == SPS30_STATUS_OK)
    {
      sensor_data->valid |= SENSOR_VALID_PM;
      sensor_data->pm1_0    = sps30_data.mc_1_0;   /* 0.1 ug/m3 */
      sensor_data->pm2_5    = sps30_data.mc_2_5;
      sensor_data->pm4_0    = sps30_data.mc_4_0;
      sensor_data->pm10_0   = sps30_data.mc_10_0;
      sensor_data->nc_0_5   = sps30_data.nc_0_5;   /* 0.1 #/cm3 */
      sensor_data->nc_1_0   = sps30_data.nc_1_0;
      sensor_data->nc_2_5   = sps30_data.nc_2_5;
      sensor_data->nc_4_0   = sps30_data.nc_4_0;
      sensor_data->nc_10_0  = sps30_data.nc_10_0;
      sensor_data->typ_size = sps30_data.typ_size; /* nm */
    }
    note_result(FAULT_COMP_SPS30, (sensor_data->valid & SENSOR_VALID_PM) != 0U);
  }

  /* ADD YOUR SENSOR (read): read it here, store the value in sensor_data,
   * set its SENSOR_VALID_* bit and call note_result(FAULT_COMP_<PART>, ok);
   * after a failure I2C2_RecoverBus(), like the blocks above. Thread mode
   * only, never from a timer. See doc/ADDING_SENSORS.md. */

  return 0;
  /* USER CODE END EnvSensors_Read */
}
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

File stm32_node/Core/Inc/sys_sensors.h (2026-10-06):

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

/* Define to prevent recursive inclusion -------------------------------------*/
#ifndef __SENSORS_H__
#define __SENSORS_H__

#ifdef __cplusplus
extern "C" {
#endif
/* Includes ------------------------------------------------------------------*/

/* Exported types ------------------------------------------------------------*/
/**
  * Sensor data parameters
  */
typedef struct
{
  uint16_t valid;         /*!< SENSOR_VALID_* bitmask */
  uint16_t pressure;      /*!< pressure in 0.1 hPa (hPa*10) */
  int16_t  temperature;   /*!< temperature in 0.01 degC (degC*100) */
  uint16_t humidity;      /*!< humidity in 0.01 % (%*100) */
  uint16_t battery_voltage;  /*!< battery voltage in mV */
  uint16_t uvi_x100;      /*!< LTR390 UV Index * 100 (e.g. 350 = UVI 3.50) */
  uint16_t co2_ppm;       /*!< SCD41 CO2 in ppm */
  uint16_t pm1_0;         /*!< SPS30 PM1.0 MC in 0.1 ug/m3 */
  uint16_t pm2_5;         /*!< SPS30 PM2.5 MC in 0.1 ug/m3 */
  uint16_t pm4_0;         /*!< SPS30 PM4.0 MC in 0.1 ug/m3 */
  uint16_t pm10_0;        /*!< SPS30 PM10.0 MC in 0.1 ug/m3 */
  uint16_t nc_0_5;        /*!< SPS30 PM0.5 NC in 0.1 #/cm3 */
  uint16_t nc_1_0;        /*!< SPS30 PM1.0 NC in 0.1 #/cm3 */
  uint16_t nc_2_5;        /*!< SPS30 PM2.5 NC in 0.1 #/cm3 */
  uint16_t nc_4_0;        /*!< SPS30 PM4.0 NC in 0.1 #/cm3 */
  uint16_t nc_10_0;       /*!< SPS30 PM10  NC in 0.1 #/cm3 */
  uint16_t typ_size;      /*!< SPS30 Typical Particle Size in nm (um*1000) */
  /* ADD YOUR SENSOR (data): add your field here, as an integer in a fixed
   * unit, plus a free SENSOR_VALID_* bit below. See doc/ADDING_SENSORS.md. */
} sensor_t;

/* Exported constants --------------------------------------------------------*/

/* External variables --------------------------------------------------------*/
/* Exported macro ------------------------------------------------------------*/
/* Exported functions prototypes ---------------------------------------------*/
/**
  * @brief  initialize the environmental sensor
  */
int32_t EnvSensors_Init(void);

/* USER CODE BEGIN EFP */
/* USER CODE BEGIN sensor_flags */
#define SENSOR_VALID_BATTERY (1U << 0)
#define SENSOR_VALID_RHT     (1U << 1)
#define SENSOR_VALID_PRESSURE (1U << 2)
#define SENSOR_VALID_UV      (1U << 3)
#define SENSOR_VALID_CO2     (1U << 4)
#define SENSOR_VALID_PM      (1U << 5)
/* ADD YOUR SENSOR: bits 6..15 are free for your SENSOR_VALID_* flag. */
#define SENSOR_INVALID_U16  UINT16_MAX
#define SENSOR_INVALID_T    INT16_MIN
int32_t EnvSensors_Sleep(void);
#define SENSOR_FLAG_CO2   (1U << 0)         /*!< Read SCD41 CO2 this cycle */
#define SENSOR_FLAG_SPS30 (1U << 1)         /*!< Read SPS30 particulates this cycle */
#define SENSOR_FLAG_ONLY_BATTERY (1U << 2)  /*!< Read only battery voltage */
/* USER CODE END sensor_flags */

/**
  * @brief  Environmental sensor read.
  */
int32_t EnvSensors_Read(sensor_t *sensor_data, uint8_t sensor_flags);

/**
  * @brief  Start pre-measurement
  */
int32_t EnvSensors_StartPreMeasurement(uint8_t sensor_flags);

/**
  * @brief  Discard the stabilisation single shot and start the useful one
  *         (power-cycled SCD41 single shot, phase 2 of 3)
  */
int32_t EnvSensors_RestartPreMeasurement(uint8_t sensor_flags);
/* USER CODE END EFP */

#ifdef __cplusplus
}
#endif

#endif /* __SENSORS_H__ */

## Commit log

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2026-04-05 update structure
    [LoRa-E5 mini v1.0.sch, components.xlsx, stevensonscreenbottom.stl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]
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2026-04-07 safe schem and hardware docs
    [MB1848_HP-(No Variations)-A01_BOM.xlsx]
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2026-04-09 add diff
    [diff.xlsx]
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2026-04-14 Potential fix for pull request finding
    [sht45.c]
2026-04-15 Implement SCD41 CO2 sensor integration and I2C bus recovery functionality and improve sendTX logic with prewake logic
2026-04-15 bug fix duplicate sensor init
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2026-04-20 Add SENSOR_FLAG_ONLY_BATTERY to read only battery voltage and update sensor reading sequence
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2026-04-20 Refactor sensor data types to use scaled integers for improved precision and consistency across sensor modules
2026-04-20 Add battery voltage thresholds to manage transmission frequency based on battery levels
2026-04-20 Enhance SPS30 sensor data structure and logging to include number concentration metrics and typical particle size
2026-04-20 Add support for STM32WLE5xx series
    - Introduced a new linker script for STM32WLE5xx devices (STM32WLE5XX_FLASH.ld).
    - Updated CMake configuration to select the appropriate linker script based on build type.
    - Modified the CMakeLists.txt to define macros specific to STM32WLE5xx for Release and Debug builds.
    - Added startup assembly file for STM32WLE5xx (startup_stm32wle5xx.s) to handle initialization and vector table setup.
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2026-04-22 bug fix: fan cleaning: implement bus acquisition and release for SPS30 commands
    [sps30.h]
2026-04-22 fix fan clean at init
    [sys_sensors.c]
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2026-05-01 Add documentation for open-source release, firmware, and testing strategy
    - Introduced a new chapter on open-source release detailing motivation, OSWHLAB contest participation, licensing under CC BY-NC-SA 4.0, and planned publication contents.
    - Added a comprehensive section on firmware and software, including build system, development environment, firmware architecture, and battery-adaptive behavior.
    - Created a new chapter on testing and validation, outlining the test strategy, results from the development prototype, and planned tests for the custom PCB.
2026-05-01 clean up hardware and add docu
    [LoRa-E5 mini v1.0.sch]
2026-05-02 Add 3D model files for outdoor screen
    [hydroNodeStation01_outdoor_screen.3mf, hydroNodeStation01_outdoor_screen_test_1.3mf]
2026-05-02 add outdoor box and screen step files
    [hydroNodeStation01_outdoor_box.step, hydroNodeStation01_outdoor_screen.step]
2026-05-02 Add 3D model file for outdoor box
    [hydroNodeStation01_outdoor_box.3mf]
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2026-05-14 Implement software UART functionality and integrate RF switch control for custom board
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2026-05-26 Update I2C configuration to use PA11 and PA12 for SDA and SCL pins
2026-05-30 Refactor UV sensor data handling to report UV Index (UVI) instead of raw counts
    - Updated LTR390 driver to calculate and store UV Index scaled by 100 (UVI * 100).
    - Changed data structure in LTR390_Data_t and sys_sensors.h to reflect UVI instead of raw UV counts.
    - Modified LTR390_ReadUV function to compute UVI from raw counts using defined scaling factors.
    - Adjusted EnvSensors_Read function to read and store UVI instead of raw UV counts.
    - Updated logging and data transmission functions to report UVI in a user-friendly format.
    [hydroNodeStation01_outdoor_box.3mf, hydroNodeStation01_outdoor_screen.3mf]
2026-06-08 Add debug profile functionality to read all sensors when DEBUG_SW_Pin is HIGH; Update and calibrate ltr390 uv
2026-06-08 Remove unused USART1 initialization and ADC measurement services from main and sys_app; optimize energy usage; add oshwlab markdown project desc
2026-06-13 Implement various enhancements and fixes for the STM32WLE5 firmware
    - Updated software initialization sequence in software.tex to reflect changes in I2C pin assignments and debug profile functionality.
    - Added a new section in solution.tex summarizing implemented solutions and project results, including TPS63900 workaround, sensor optimizations, I2C bus robustness, energy optimization via software UART, and debug profile for sensor verification.
    - Enhanced testing documentation in testing.tex with detailed results from electrical inspection, sensor verification, and long-term field tests.
    - Expanded time effort documentation in time-effort.tex with a detailed project plan, a comparison of pl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
    [bq25185.c]
2026-06-16 clean up project struct
    [bom_diff.xlsx, hydroNodeStation01_outdoor_box.3mf, hydroNodeStation01_outdoor_box.step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]
2026-06-21 Enhance SCD41 sensor handling and application configuration
    - Added functions to discard and restart CO2 single shot measurements for improved accuracy.
    - Updated pre-measurement logic to handle stabilisation and useful shots.
    - Introduced persistent application configuration for TX duty cycle, allowing runtime adjustments.
    - Adjusted TX duty cycle default and bounds for better operational flexibility.
2026-06-22 Refactor README and documentation; update LoRaWAN integration details and power consumption metrics
2026-06-23 add presentation and update outdoor box cad file
    [hydroNodeStation01_outdoor_box.3mf]
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2026-09-06 fix: stop persistence and modem anomalies from resetting the station
    A committed NVM snapshot was reported as lost when the migration marker
    could not be programmed, and StoreContext resets the MCU on a reported
    loss. On a board upgraded from the legacy layout that marker doubleword
    is already programmed with all ones, because the old flash_if rewrote
    whole pages including their unused tail: it reads erased but cannot be
    programmed again. Every join therefore ended in a reset inside the
    JoinAccept window, and the station never joined.
    Nvm_Write now reports success once the snapshot is committed and
    verified. The marker step erases the obsolete legacy context page once
    before retrying, and N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
    [gpio.c, main.h, nvm_port.c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]
2026-09-06 fix: start the SPS30 measurement after waking it from sleep
    Particulate uplinks carried zeroes instead of readings. Sleep-Mode
    disables the sensor's I2C interface: the first wake-up command only
    wakes it and is not acknowledged, and the interface needs its wake-up
    time before it can answer the next one. Both commands went out back to
    back with the delay after them, so the second was NACKed on a healthy
    sensor. EnvSensors_StartPreMeasurement gated the start command on that
    NACK and skipped it, leaving the sensor awake but idle. Reading an idle
    SPS30 returns CRC-valid zeroes, which passed as a measurement and were
    published in place of the missing-value sentinels.
    The delay now sits between t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
    [sys_sensors.c]
2026-09-07 docs: prepare repository for public open-source release
    Relicense from CC BY-NC-SA 4.0 to a set of genuinely open licences:
    - Hardware (schematic, PCB, CAD, BOM): CERN-OHL-S v2, strongly reciprocal
    - Documentation and media: CC BY-SA 4.0
    - Own firmware code (sensor drivers, NVM, power policy, tests): MIT
    - Vendored ST/Arm/Semtech components keep their upstream terms
    CC BY-NC-SA is not an open-source licence: the non-commercial clause is
    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
2026-09-07 docs: rename project from HydroNodeStation01 to HydroNodeStation
    The project is republished under github.com/TexhFexLabs/HydroNodeStation,
    so drop the trailing "01" everywhere. The number was a working title for
    the first station, not a product name; individual deployed units are now
    numbered in the architecture diagram instead.
    Renamed in prose, links and the two CAD filenames. No build files, CMake
    targets or firmware identifiers reference the old name, so the build is
    unaffected. The study documentation was recompiled.
    Also:
    - Add doc/DEVELOPMENT_HISTORY.md preserving the issue and pull-request
    record of the private development phase, which does not carry over to
    the new repository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
    [hydroNodeStation_outdoor_box.3mf, hydroNodeStation_outdoor_screen.3mf]
2026-09-07 docs: tighten accuracy of the OSHWLab project description
    Final pass against the repository and the measured data:
    - Drop "fully solar-autonomous" from the lead. Long-term autonomy is not
    verified yet; the measured figure is ~24 days without solar input.
    - Label the cost table as sensor BOM cost, which is what the numbers
    actually are, and state that board and fabrication come on top.
    - The DeviceEUI is derived from the STM32 unique ID, so the reproduction
    steps no longer tell people to set one.
    - Name the third-party licences correctly: ST HAL BSD-3-Clause, Arm CMSIS
    Apache-2.0, Semtech LoRa Basics Modem BSD-3-Clause.
    - Split the deliverables list into what is attached to the OSHWL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
2026-09-07 docs: move live dashboard links to hydronode.tech
    The public dashboard is now served from hydronode.tech. Both hosts
    currently answer, but the short domain is the one to publish.
    Rewrites every hydronode.texhfexlabs.de link in the README, the issue
    template config, the getting-started guide, the OSHWLab description and
    both LaTeX reports, and recompiles the two PDFs. The
    contact@texhfexlabs.de address is unrelated and stays.
2026-09-07 docs: add a full build guide and drop emoji and dash styling
    The README now carries the complete path from ordering parts to live
    readings on the dashboard, in twelve steps: choosing between the custom
    PCB and the Wio-E5 prototyping route, ordering and assembling the board
    at JLCPCB, sourcing the parts that are not on the PCB, printing the
    enclosure, assembly, toolchain, build, flashing, reading the derived
    Device EUI, registering the OTAA device, entering the keys, binding the
    station in HydroNode, and verifying the first uplink.
    Previously that path was split between a six-bullet summary in the README
    and doc/GETTING_STARTED.md, and the hardware half was not documented at
    all outside the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
    [bom_diff.xlsx, components.xlsx, pcb_bom_jlcpcb.xlsx]
2026-10-05 feat: map PCB 1.1 pins and drop Nucleo leftovers
    Name the pins after the schematic nets, park unused pins analog and
    remove the Nucleo buttons, LEDs and USART2 on PA2/PA3, which collide
    with the charger CE and the 1-Wire header.
    Refs TD_2_0_1
    [gpio.c, main.c, main.h]
2026-10-05 docs: freeze the CubeMX project file
    The .ioc is still the ST template; regenerating would overwrite the
    PCB 1.1 pin map and clock setup.
    Refs TD_2_0_21
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2026-10-05 fix: move the charger CE control to PA2
    PCB 1.1 routes BQ25185 CE to PA2; PA7 only reaches H2.5. The LOW level
    comes from R7, not from an internal pull-down.
    Refs TD_2_0_4
    [bq25185.c]
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2026-10-05 fix: drop the debug probe lines and trace over USART1
    PROBE_LINE1 was PB12, which now supplies the RF switch, and the radio
    planner toggled it on every RX. sys_debug no longer touches PA11/PA12
    or PB12 and refuses RF monitor outputs on board pins. The software
    UART on PA6 is replaced by USART1 on H1, started only while output is
    enabled; Debug builds turn APP_LOG on, Release keeps it off.
    Refs TD_2_0_2
    [main.c, sys_conf.h]
2026-10-05 feat: start the LSE at medium-high drive with a retry
    Wait 2 s for LSERDY at MEDIUMHIGH, retry once at HIGH. If both fail,
    record restart reason 6 in the RTC backup, blink it on the diagnostic
    LED for 60 s and reset; a later cold start may succeed. No LSI
    fallback, it cannot time the RX windows.
    Refs TD_2_0_6
    [main.c, main.h, runtime_health.c]
2026-10-05 fix: describe the PCB 1.1 radio: crystal, RFO_HP, switch VDD on PB12
    The inactive non-BSP branch now also reports no TCXO and RFO_HP only.
    The BSP supplies the RF switch from PB12 and leaves PB0 (VDD_TCXO)
    untouched.
    Refs TD_2_0_7
2026-10-05 fix: select the RF switch state for the PA actually wired
    sx126x_set_ant_switch hard-coded RFO_LP and so also applied the LP-only
    SMPS drive tweak. Follow RBI_GetTxConfig() like the TX power setup.
    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
2026-10-05 feat: sample the INA226 at the solar input every 30 s
    Triggered shunt and bus conversion (AVG 16, 1.1 ms, about 36 ms), then
    power-down. The timer only posts an event; I2C runs in thread mode and
    only in NORMAL and SAVE. A pure accumulator keeps mean V, I and V x I
    power, energy in 0.1 mWh and sunshine seconds for the next block, with
    sentinels when the part is missing.
    Refs TD_2_0_10
    [ina226.c, solar.c, sys_sensors.c]
2026-10-05 feat: measure the solar voltage at PB2 with every solar sample
    Convert ADC_IN4 behind the 150k/100k divider with VREFINT scaling and
    the longest sampling time, then switch the ADC off. ADC errors are no
    longer fatal on this path. adc.c and adc_if.c were not built before.
    Refs TD_2_0_11
    [adc_if.c]
2026-10-05 feat: read the board temperature in 0.01 degC
    SYS_GetTemperatureLevel() only resolves whole degrees (q8.8). Add a
    reader that rescales the sensor to the 3.3 V calibration VDDA and
    interpolates TS_CAL1/TS_CAL2 in 0.01 degC, with the ADC off afterwards.
    Refs TD_2_0_12
    [adc_if.c]
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2026-10-05 feat: append the solar and gauge block to ports 2 and 3
    Port 2 grows to 32 bytes and port 3 to 34: solar V, I, P, energy and
    sunshine, the PB2 voltage, SOC, charge rate, board temperature and the
    two counters. Port 4 stays at 32 bytes without block, since 54 bytes
    would not fit DR0-DR2. The block is reset only once the modem accepted
    it. The decoder reads the new lengths and still accepts 1.x frames.
    Refs TD_2_0_14
2026-10-05 feat: add the fault and event queue for fPort 99
    Entries are code + detail, 4 bytes each, at most 8 per frame. States
    (categories 0x01-0x03) are queued on entry and on exit, events
    (0x04-0x06) per occurrence. A 16-entry RAM queue drops resolved entries
    first, then the oldest, and reports the loss as 0x054F. Read errors
    count as a fault after three in a row.
    Refs TD_2_0_15
    [fault_codes.h, fault_report.c]
2026-10-05 feat: report faults, supply states and boot info on fPort 99
    After the join the first frame carries the restart reason with reset
    flags (0x0540), the version (0x0541) and a LSE retry (0x0542). Sensors,
    INA226, solar ADC, board sensor and I2C bus feed the component states;
    supply modes, rejoins, unsent or rejected uplinks and NVM errors are
    queued as well. One frame may follow each accepted regular uplink.
    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
    [i2c.c, sys_sensors.c]
2026-10-05 feat: acknowledge every fPort 2 command on fPort 99
    Each non-empty command downlink queues 0x06xx with its result: done,
    invalid, refused by battery or mode, save failed, unknown, reply not
    accepted or execution failed. 10 HH LL now applies at once by
    rescheduling the next round instead of only after a restart. FF stores
    restart reason 7 so the boot entry 0x0540 acknowledges it.
    Refs TD_2_0_16
    [fault_codes.h, runtime_health.c]
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2026-10-06 fix: subtract the antenna gain from the requested EIRP
    The stack asks for 16 dBm EIRP in EU868 and the PA delivered it conducted, so a 2 dBi antenna radiated 18 dBm. BOARD_ANTENNA_GAIN_DB (default 2) now comes off before the PA setting.
    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
2026-10-06 feat: rank fault reports and damp the noisy ones
    Urgent entries (boot, rejoin, missing part, supply, command acknowledgements) still leave with the next uplink; everything else waits until an hour has passed since the last fault frame. A part whose read errors reopen within 6 h is reported resolved only after 6 h of good reads. 0x0431/0x0432 are counted and sent once a day.
    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
    [fault_codes.h, fault_report.c]
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2026-10-06 docs: show where an own Qwiic sensor goes
    doc/ADDING_SENSORS.md walks through driver, fault id, init, read, sleep, own fPort and debug output; ADD YOUR SENSOR comments mark each place in the code. Also fixes the stale I2C pins in sht45.h.
    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
    [debug_profile.c, fault_codes.h, sys_sensors.c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]
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2026-10-12 feat: status report on fPort 99 for command 12 (2.1.1)
    0x12 queued its fPort 5 diagnostic straight from the downlink handler; the
    fault frame requested at the next TXDONE replaced it in LBM, so it never left.
    Now 0x12 queues 0x0545 (open states count), the version, every open state
    with its detail and the ack through the fault queue, plus the fPort 6
    settings report. Drops the unused diagnostic counters.
2026-10-12 fix: status report goes out whole and without delay
    A report that did not fit could lose entries to the queue's eviction, and the
    backend would close states that are still open. Now it is queued only with room
    for all of it plus the ack (else 0x0612 result 6), later entries cannot evict
    it, and a frame is due until it has left, also when the rest is only read
    errors.
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

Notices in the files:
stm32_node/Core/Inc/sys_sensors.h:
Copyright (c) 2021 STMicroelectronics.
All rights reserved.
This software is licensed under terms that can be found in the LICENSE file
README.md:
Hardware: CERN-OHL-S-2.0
